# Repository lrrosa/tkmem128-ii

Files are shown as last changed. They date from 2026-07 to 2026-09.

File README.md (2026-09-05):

# TKMEM-128 II



Expansão externa de **128 KB (ou 512 KB) de RAM paginada no padrão ZX Spectrum 128**
para **TK90X, TK95 e ZX Spectrum 48K**. Redesenho completo em **KiCad 10**, com
arquivos de fabricação prontos.

> O nome vem da placa brasileira que originou este redesenho, mas o circuito é do
> **Velesoft e nasceu para o ZX Spectrum 48K**. A adaptação de 2012 ao TK usava um
> contato que no Spectrum carrega vídeo; aqui isso foi corrigido, e a placa voltou
> a servir nas duas famílias. Ver [Compatibilidade](#compatibilidade).

> **Estado: placas fabricadas e conferidas eletricamente, ainda não montadas.**
> ERC e DRC estão zerados, a netlist foi conferida contra a intenção de projeto,
> e as duas placas **voltaram da fábrica em setembro de 2026 com todas as ilhas
> aprovadas no teste de continuidade**. O que ainda não foi feito: **montar os
> componentes e ligar num micro real**. Antes de mandar fabricar, leia
> [`docs/ANTES-DE-FABRICAR.md`](docs/ANTES-DE-FABRICAR.md) — há itens que
> dependem de medir peças físicas.
>
> O conector de borda é o **TE/AMP 5645235**, de entrada vertical. As cotas do
> footprint saíram do desenho de cliente e estão no
> [datasheet arquivado](docs/), mas ninguém montou a peça ainda.

---

## Este projeto é uma derivação

Ele não inventa o circuito: junta e redesenha dois trabalhos anteriores.

| Origem | Autor | O que veio de lá |
| --- | --- | --- |
| [**external 128kb upgrade**](https://velesoft.speccy.cz/zx/external_128kb_upgrade/index.htm) (`zx48_to_128-EASY_3`), 2009 | **Velesoft** (Pavel Cimbal, República Tcheca) | O circuito base: as equações do GAL20V8, o latch da porta `0x7FFD` e o esquema de paginação da SRAM, incluindo a extensão de 512K |
| **TKMEM-128**, 2012 | **Luccas Eletrônica** (Eduardo Luccas, Brasil) | A adaptação ao TK90X/TK95: soquete de EPROM com a ROM do Spectrum 128, jumpers de seleção de ROM, a auto-desativação da RAM interna de 32K por um pino livre do barramento, e a divisão em placa principal + expansor |

Créditos também a **Flávio Matsumoto**, que sugeriu o circuito do Velesoft para
os TKs e identificou a caixa Patola PB 085/3, e a **Daniel Jose Viana
(danjovic)**, cujo trabalho documentou as cotas da placa para essa caixa.

E a [**goloskokovic/zx16to128upgrade**](https://github.com/goloskokovic/zx16to128upgrade),
que redistribui o material do Velesoft com o crédito devido. De lá vieram duas
coisas que não estavam aqui: os **pontos de desativação da RAM interna num ZX
Spectrum 48K**, por Issue de placa-mãe (ver
[`docs/PREPARAR-O-TK.md`](docs/PREPARAR-O-TK.md#e-num-zx-spectrum-48k)), e os
arquivos da variante **`EASY_6b`**, que permitiram comparar as duas versões do
circuito original (ver
[`docs/VELESOFT-EASY3-x-EASY6B.md`](docs/VELESOFT-EASY3-x-EASY6B.md)). Nenhum
desses dois foi verificado em bancada por nós.

Este redesenho é distribuído sob **CERN-OHL-S v2** (ver [LICENSE.txt](LICENSE.txt)),
uma licença *fortemente recíproca*: quem fabricar, modificar ou distribuir
precisa disponibilizar as fontes das modificações sob a mesma licença.

---

## O que a placa faz

O ZX Spectrum 128 difere do 48K em três coisas: 128K de RAM em 8 bancos de 16K,
o chip de som AY-3-8912, e o espelhamento da memória de vídeo ("shadow video").
Esta placa entrega **a primeira**. O som AY exige interface separada; o shadow
video é inviável numa interface externa, porque exigiria interceptar a RAM baixa
da ULA dentro do micro.

Na prática a grande maioria dos jogos de 128K funciona — a exceção são os poucos
títulos que dependem do shadow video.

### Mapa de memória

| Faixa | Quem responde |
| --- | --- |
| `0x0000-0x3FFF` | ROM — a interna do micro, ou a 27C256 da placa (jumper) |
| `0x4000-0x7FFF` | RAM baixa **interna do micro** (memória de vídeo da ULA). Não é decodificada aqui |
| `0x8000-0xBFFF` | SRAM externa, **banco 2 fixo** |
| `0xC000-0xFFFF` | SRAM externa, banco selecionado pela porta `0x7FFD` |

Como a SRAM externa cobre `0x8000-0xFFFF`, **os 32 KB superiores de RAM interna
precisam ser desativados** — é a única alteração necessária dentro do micro, e a
única coisa que difere entre TK e ZX Spectrum. Veja
[`docs/PREPARAR-O-TK.md`](docs/PREPARAR-O-TK.md).

> **Sobre a variante `EASY_6b` do Velesoft.** Circula junto com a nossa em
> outros repositórios, e é fácil confundir com uma versão melhor. Não é: a
> serigrafia da placa dela diz `MEMORY UPGRADE FOR ZX 16`. É para um Spectrum de
> **16 KB**, onde a RAM inteira vem de fora — por isso as equações dela também
> decodificam `0x4000-0x7FFF`. **Este projeto deriva da `EASY_3`**; a comparação
> completa, incluindo a conferência do nosso esquemático e do nosso layout contra
> os do Velesoft, está em
> [`docs/VELESOFT-EASY3-x-EASY6B.md`](docs/VELESOFT-EASY3-x-EASY6B.md).

### Porta 0x7FFD

Um `74HCT273` latcheia o barramento de dados quando o GAL detecta a escrita na
porta (`A15=0`, `A5=1`, `A1=0`, `/IORQ` e `/WR` ativos):

| Bit | Sinal | Função |
| --- | --- | --- |
| 0–2 | `BANK0..BANK2` | Banco de RAM em `0xC000` |
| 3 | `VRAM` | Shadow screen — latcheado, **sem uso** nesta arquitetura (disponível em TP1) |
| 4 | `ROMA14` | Seleciona a metade da 27C256 |
| 5 | `DIS128` | Trava a paginação até o reset |
| 6–7 | `BANK3..BANK4` | Extensão 512K (só no modo ZX512) |

A trava do bit 5 é elegante: `DIS128` entra na equação do clock do latch
(`CLK7FFD = ... + DIS128`), então ao ser setado o clock fica preso em nível alto
e o latch nunca mais é acionado.

---

## Compatibilidade

**TK90X, TK95 e ZX Spectrum 48K.** Não é uma promessa vaga: reduz-se a uma regra
que dá para verificar.

O barramento de expansão é o mesmo conector de 2×28 nas duas famílias, mas
**nove contatos não carregam a mesma coisa** em cada uma. Enquanto a placa não
tocar nenhum deles, ela serve nas duas:

| Contato | No TK90X/TK95 | No ZX Spectrum 48K |
| --- | --- | --- |
| 4 | +9 V | USS |
| 7 | N.C. | GND |
| 15 | GND | sinal |
| 16, 17, 18 | livres | **Y, V e U do vídeo componente** |
| 34, 35 | 12 V | difere |
| 37 | **+5 V** | **−5 V** |

Esta placa liga **34 dos 54 contatos, e nenhum é dessa lista.** Alimentação sai
dos contatos 3 (+5 V), 6 e 14 (GND), que são iguais nas duas máquinas.

A verificação é automática, para a afirmação não envelhecer:

```bash
python tools/confere_compatibilidade.py
```

Ele cruza a lista de divergências de `busdef.py` com os contatos que a netlist
realmente usa, e falha se algum aparecer.

> ⚠️ **O que ainda é específico de cada máquina: desativar a RAM interna de 32 KB.**
> Isso não é opcional — sem desativar, a memória do micro colide com a SRAM
> externa em `0x8000-0xFFFF`. No TK é um fio do contato 29 ao pino 10 do IC27;
> num Spectrum o ponto é outro e **depende da Issue da placa-mãe** — os dois
> procedimentos estão em
> [`docs/PREPARAR-O-TK.md`](docs/PREPARAR-O-TK.md#e-num-zx-spectrum-48k).
> Num Spectrum a placa não aciona nada pelo contato 29 — mas **não porque o
> contato seja diferente**: ele é N.C. nas duas máquinas. É porque o
> procedimento publicado para o Spectrum amarra o pino do mod ao +5 V do
> próprio CI, sem trazer fio até o conector. Levar o truque do TK para lá é a
> mesma topologia, e esbarra numa diferença *elétrica* —
> [analisada aqui](docs/PREPARAR-O-TK.md#dava-para-levar-a-auto-desativação-para-o-spectrum).
>
> Não montamos a placa num Spectrum: a compatibilidade acima é do barramento,
> conferida contato a contato, não de bancada — e o ponto interno do Spectrum
> vem de terceiros, também não verificado por nós.

---

## As duas placas

A placa de componentes fica **em pé** dentro da caixa. O conector de borda é
soldado **diretamente nela** — e como esse conector é de entrada vertical
(a placa que entra fica perpendicular à que segura o conector), a fenda dele cai
no plano horizontal e recebe a placa do micro.

Os terminais do conector são **retos** e atravessam a placa, sobrando ~3,18 mm
do outro lado em duas fileiras a 4,85 mm. A **tira de expansão** entra **entre
essas fileiras** — uma passa por cima dela, a outra por baixo — e é soldada
**dos dois lados**. Ela não tem conector nenhum: ilhas de solda nas duas faces
de um extremo, dedos de borda no outro.

Vista de lado, com as caixas em corte

O **conector fica fora da caixa Patola**, atravessando o recorte que se abre na
frente dela. Não é escolha estética: no TK e no ZX Spectrum a abertura
`EXPANSION` é **recuada dentro da carcaça**, então a caixa encosta na traseira do
micro e só o conector entra. A placa, por sua vez, assenta rente ao fundo da
caixa.

> No conector, **1..28 fica na fileira de baixo** (junto à aresta inferior da
> placa), igual à fileira inferior da placa do micro; 29..56 fica do lado de
> dentro. É a mesma convenção no TK e no ZX Spectrum, onde essas fileiras são
> chamadas de B e A.
>
> ⚠️ **O lado dos componentes tem que ficar virado para a tira de expansão**,
> nunca para o lado do conector. Ao contrário, a placa dentro da caixa esbarra
> no micro e não encaixa direito. Na prática o conector de borda é **o único
> componente do lado do cobre**: entra por baixo e é soldado por cima.

| Placa | Arquivo | Conteúdo |
| --- | --- | --- |
| Principal | [`hardware/tkmem128-ii.kicad_pro`](hardware/) | GAL20V8B, 74HCT273, SRAM DIP-32, EPROM 27C256, 3 jumpers, desacoplamento e o conector de borda |
| Tira de expansão | [`hardware/expansor/`](hardware/expansor/) | Ilhas de solda nas duas faces de um lado, dedos de borda do outro — nenhum componente, só o fio de terra `W1` |

A **placa principal é de 4 camadas**; a tira de expansão, de 2.

| Camada | Placa principal | Tira |
| --- | --- | --- |
| F.Cu | sinal | 27 retas de 1,5 mm (pinos 29..56) |
| In1.Cu | **plano de GND** inteiro | — |
| In2.Cu | **plano de +5V** inteiro | — |
| B.Cu | sinal | 27 retas de 1,5 mm (pinos 1..28) |

Como todos os componentes são passantes, cada ilha de `+5V` e de `GND` toca o seu
plano direto: **não há uma única trilha de alimentação nas faces de sinal**, e
nenhuma via serve só para alimentação. Sinal de 0,5 mm, isolação de 0,2 mm,
21 vias, e nenhum fio de ligação.

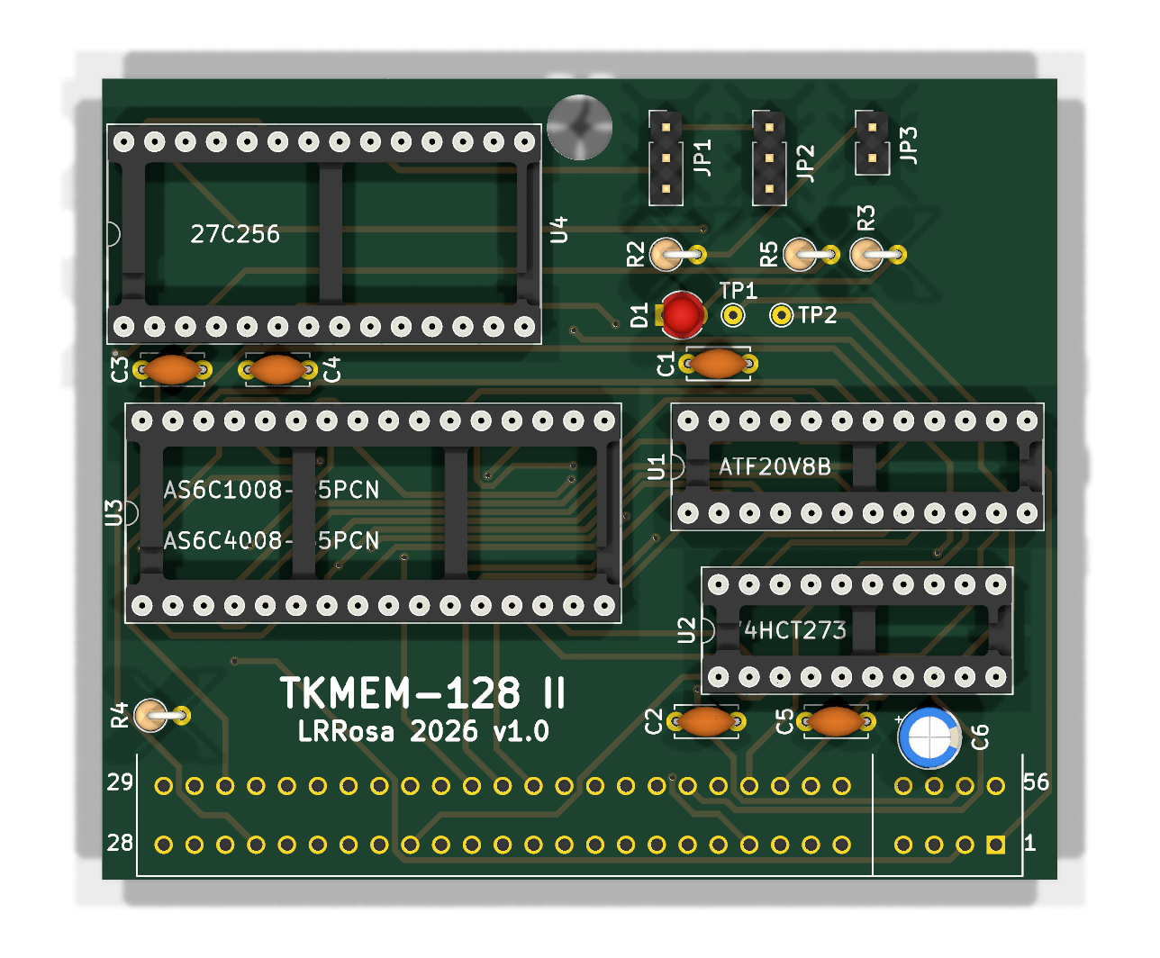
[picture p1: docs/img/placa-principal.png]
Placa principal


O furo grande no topo é o `H1`, e ele não é furo de parafuso: por ali **passa a
torre** de fixação da caixa Patola, que tem Ø5 externo e nasce do fundo da
tampa. O parafuso da caixa corre dentro da torre e nunca toca a placa — `H1`
serve para localizar, não para apertar.

O conector é passante e é usado pelos dois lados — por baixo entra o conector,
por cima solda a tira —, então a numeração dele está serigrafada nas duas
faces.

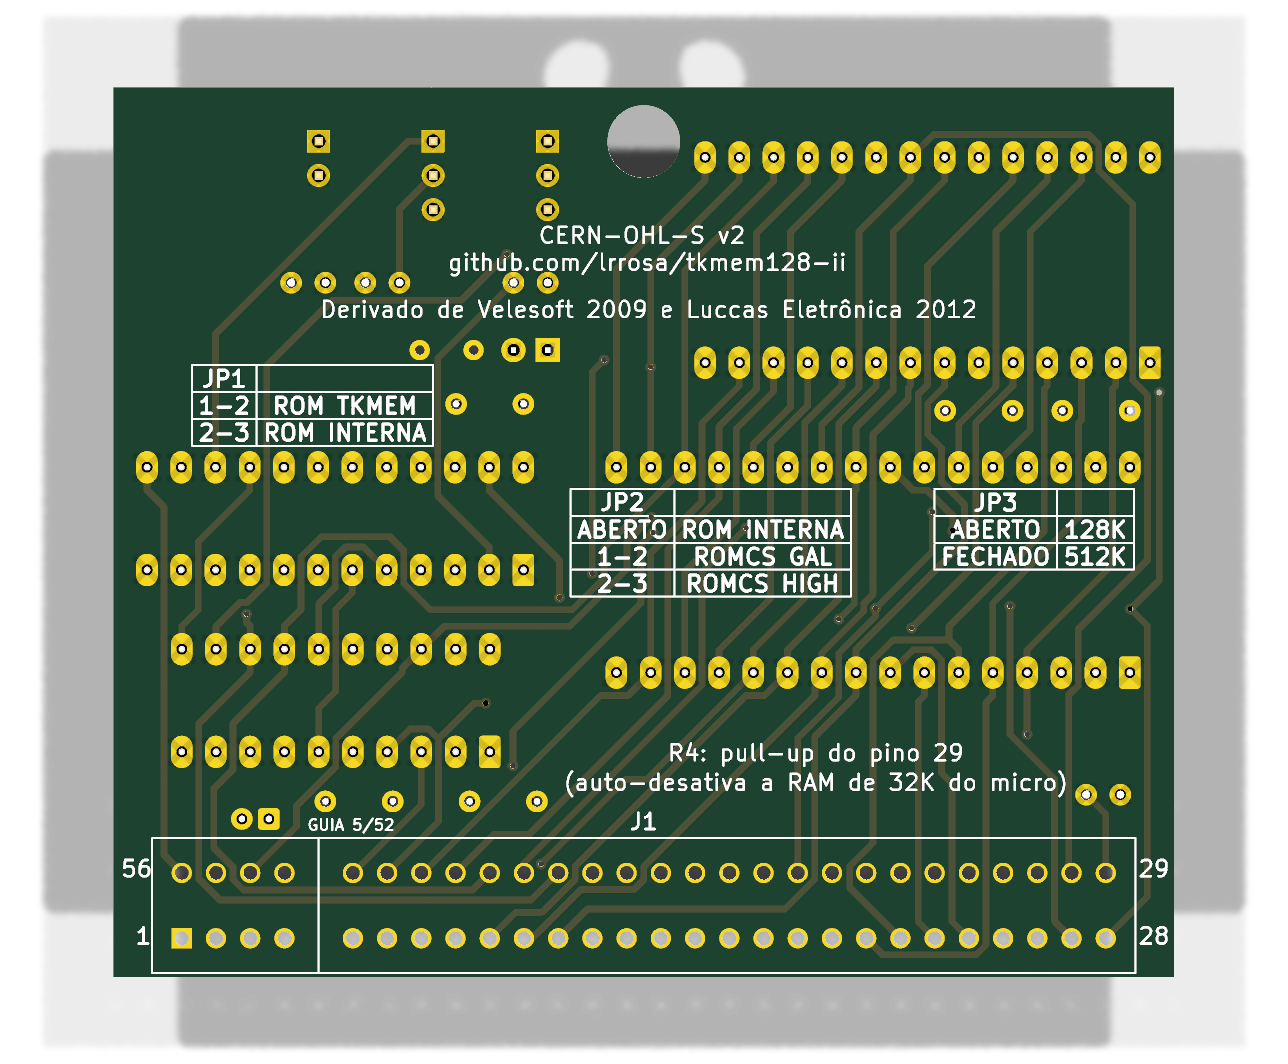
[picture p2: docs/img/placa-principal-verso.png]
Placa principal, verso


O verso é o manual da placa. Traz as **três tabelas de jumper**, a função do
`R4` e a licença — na bancada, com um shunt na pinça, isso vale mais que este
README.

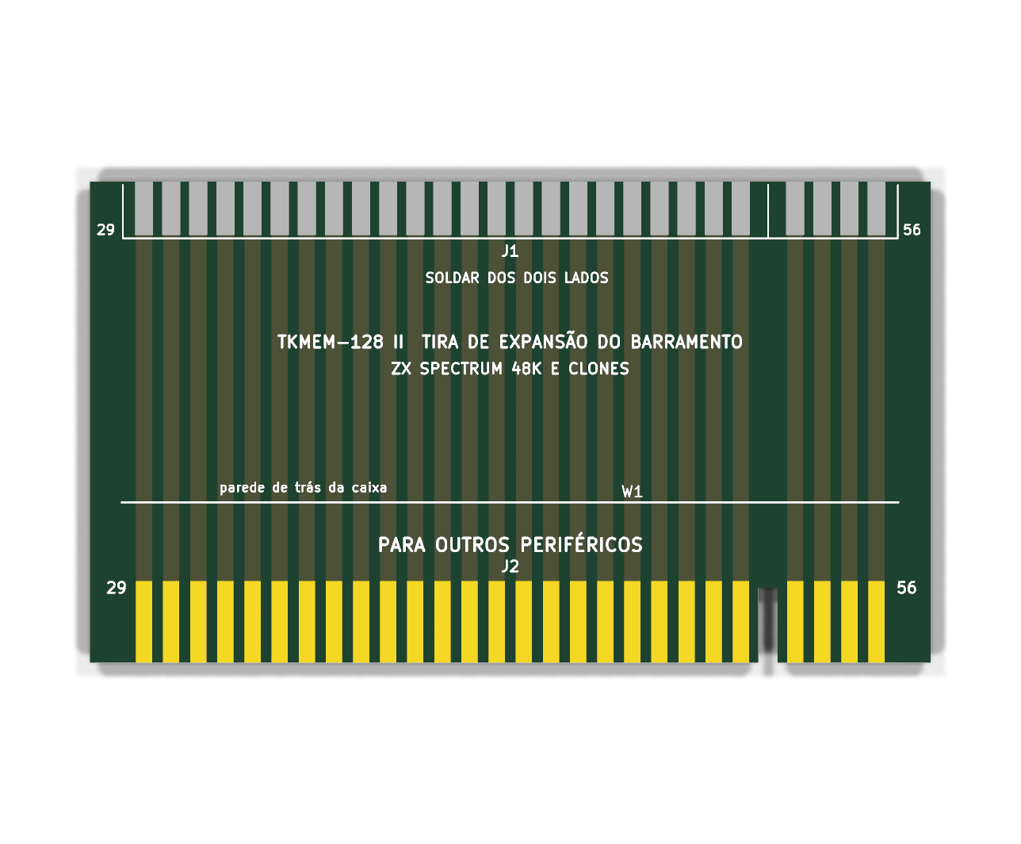
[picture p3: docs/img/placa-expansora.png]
Tira de expansão


A tira é soldada dos dois lados, então cada face traz a numeração dos **seus**
pinos: 29..56 na frente, 1..28 no verso.

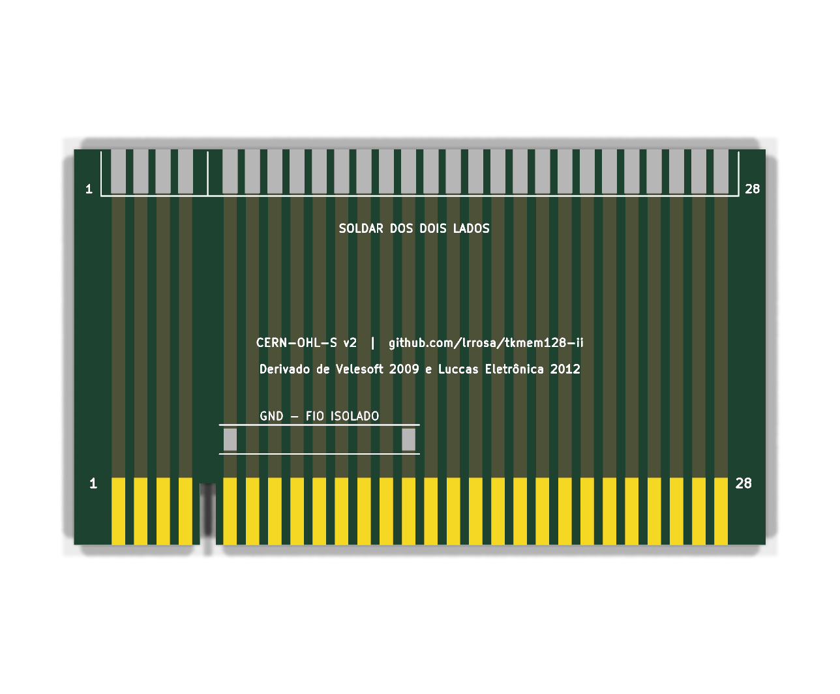
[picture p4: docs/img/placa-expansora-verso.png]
Tira de expansão, verso


### E fabricadas

Primeira tiragem, setembro de 2026. **Todas as ilhas passaram no teste de
continuidade** — as placas ainda não foram montadas nem ligadas num micro.

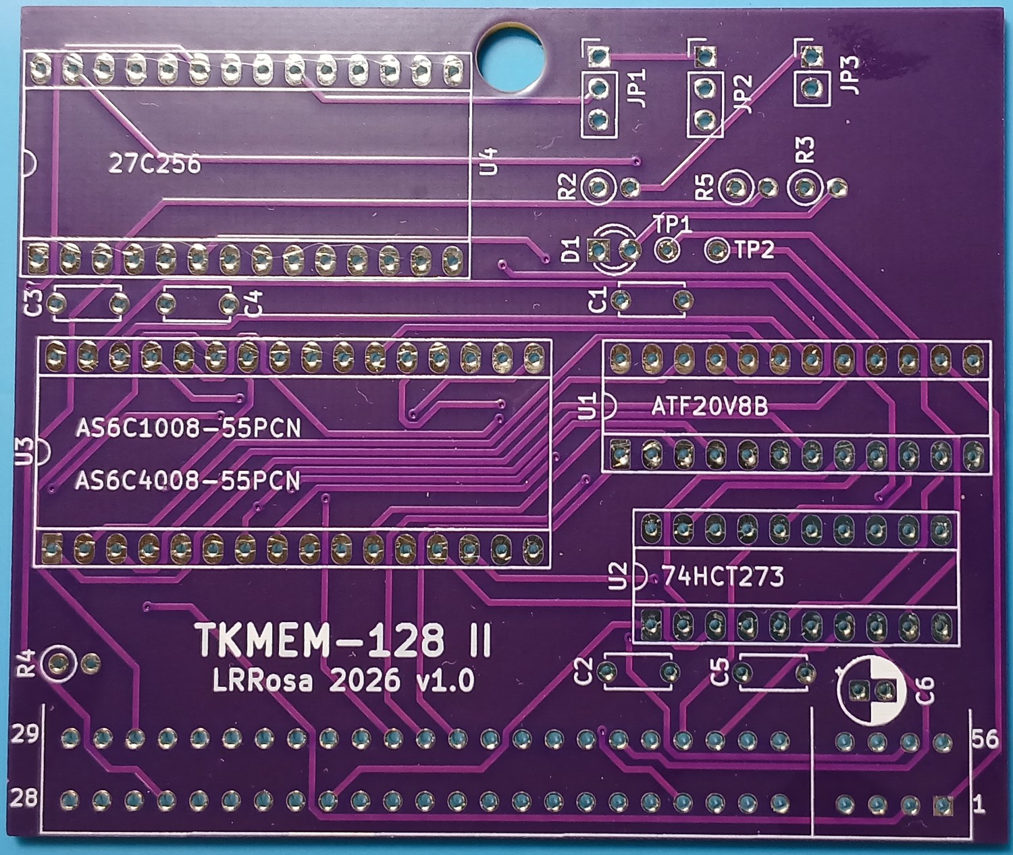
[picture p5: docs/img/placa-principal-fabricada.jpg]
Placa principal fabricada, lado dos componentes


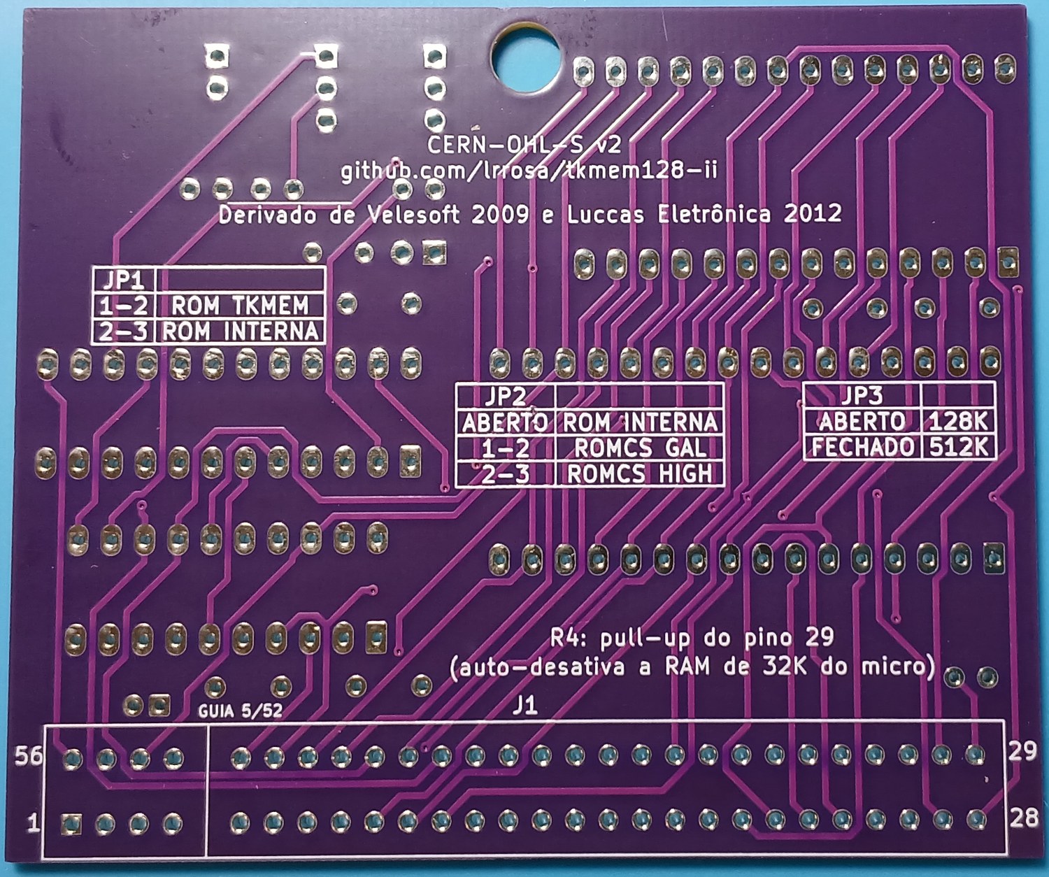
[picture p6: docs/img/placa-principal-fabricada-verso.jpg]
Placa principal fabricada, lado do cobre


O verso cumpriu o que o render prometia: as três tabelas de jumper e a nota do
`R4` ficam legíveis a olho nu com a serigrafia de 1,2 mm — que é o ponto de
tê-las na placa em vez de só aqui.

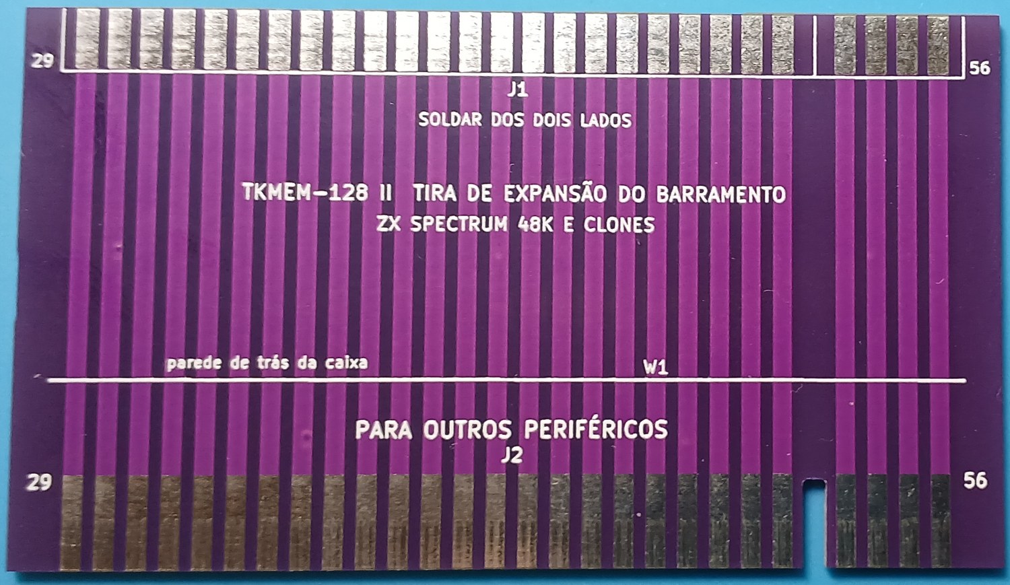
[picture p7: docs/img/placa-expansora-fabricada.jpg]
Tira de expansão fabricada


A tira mostra os dois itens do formulário que **não viajam nos gerbers** (item 0
do [ANTES-DE-FABRICAR](docs/ANTES-DE-FABRICAR.md)) tendo saído certos: os dedos
vieram com **ENIG** e com o **chanfro de 45°**. O entalhe na borda de baixo, à
direita do centro, é o rasgo da guia — aprofundado de 5,0 para 7,0 mm depois da
conferência em papel.

---

## O que mudou em relação ao original

| Melhoria | Motivo |
| --- | --- |
| **Passagem do barramento** (dedos de borda na expansora) | O original ocupava o barramento; agora dá para encadear outros periféricos |
| **Desacoplamento por CI** (100 nF em cada um) + 10 µF de reservatório | O original tinha desacoplamento mínimo |
| **4 camadas com planos de GND e +5V inteiros** | Alimentação sem uma única trilha nas faces de sinal, retorno de corrente curto e imunidade a ruído. O original era de 2 camadas |
| **Jumper JP2 com duas estratégias de ROMCS** | O `ROMCS` do barramento é **ativo em nível alto** para desligar a ROM interna, o oposto da saída `/ROMCS` do GAL. É a explicação mais provável para a ROM 128 do original "funcionar num TK e não em outro". JP2 permite escolher entre acionar pelo GAL ou fixar em nível alto (como fazem os cartuchos da Interface 2), com R5 em série |
| **Auto-desativação sem jumper nenhum** | A original usava o **pino 17**, livre no TK mas **V do vídeo componente no ZX Spectrum** — daí o jumper e o aviso de que a posição errada danifica o micro. Aqui o sinal vai pelo **pino 29**, que é N.C. nas duas máquinas, então o pull-up é permanente e **JP4 deixou de existir**. Ver [a análise](docs/PREPARAR-O-TK.md#por-que-o-pino-29) |
| **GAL com `.jed` pronto e verificado** | O usuário não precisa montar nada: o `.jed` distribuído é gerado das equações deste projeto e conferido fusível a fusível contra o mapa de referência (checksum `C5752`, zero divergências) |
| **Degrau zero na corrente de periféricos** | A tira de expansão solda nos terminais do próprio conector, ficando coplanar com a placa do micro. O periférico seguinte entra no mesmo plano, sem escadinha |
| **Bit N da porta 7FFD no flip-flop N** | O original embaralhava as entradas do latch; aqui a ordem é natural e o esquemático se lê sozinho |
| **Endereços e dados da EPROM 1:1** | Obrigatório (o conteúdo da ROM é fixo) e documentado |
| **Pontos de teste** (`VRAM`, `CLK7FFD`) | Para depurar sem grampear em perna de CI |
| **LED de energia** (opcional) | Diagnóstico imediato |
| **Peças em produção na BOM** | AS6C1008 e ATF20V8B no lugar de peças só encontráveis como estoque antigo |

---

## Configuração dos jumpers

| Jumper | Posição | Efeito |
| --- | --- | --- |
| **JP1** SELECIONA ROM | 1-2 | ROM 128: a EPROM da placa responde em `0x0000-0x3FFF` |
| | 2-3 | ROM interna: EPROM desligada (padrão) |
| **JP2** ROMCS BARRAMENTO | aberto | Usa a ROM interna do micro (padrão) |
| | 1-2 | Aciona `ROMCS` pelo GAL (comportamento da placa original) |
| | 2-3 | Fixa `ROMCS` em nível alto (estilo Interface 2) |
| **JP3** ZX128/ZX512 | aberto | 128K — SRAM `AS6C1008` (padrão) |
| | fechado | 512K — SRAM `AS6C4008` |

Esta tabela está **serigrafada no verso da placa**, uma por jumper, com as
mesmas palavras — ver o render do verso acima.

> ⚠️ **JP1 em 1-2 sem JP2** não faz nada útil: sem desligar a ROM interna, os dois
> chips disputam o barramento de dados. Use os dois juntos ou nenhum.

> **A auto-desativação da RAM não tem jumper.** `R4` mantém o **pino 29** em
> nível 1 permanentemente, e esse pino é N.C. tanto no TK quanto no ZX Spectrum.
> Num Spectrum a placa não faz nada ali; num TK, com o fio interno do pino 29 ao
> pino 10 do IC27, ela desliga os 32 KB. Nada a configurar.

---

## Lista de material

### Placa principal

| Ref | Valor | Encapsulamento | Observação |
| --- | --- | --- | --- |
| U1 | GAL20V8B, **ATF20V8B-15PC** ou PALCE20V8H | DIP-24 300 mil | Grave [`hardware/gal/tkmem128.jed`](hardware/gal/tkmem128.jed) — peças equivalentes em [hardware/gal](hardware/gal/README.md) |
| U2 | 74HCT273 | DIP-20 300 mil | Latch da porta 7FFD |
| U3 | **AS6C1008-55PCN** (128K×8) | DIP-32 600 mil | Ou `AS6C4008-55PCN` (512K×8) no modo ZX512 — outras peças servem, ver [equivalentes](#equivalentes-para-u3-a-sram) |
| U4 | 27C256 | DIP-28 600 mil | **Opcional** — ver seção da ROM |
| R2, R4 | 1 kΩ | axial, vertical | |
| R5 | 0 Ω | axial, vertical | Fio; 100–470 Ω se houver disputa no ROMCS |
| R3 | 2,2 kΩ | axial, vertical | Opcional (LED) |
| C1–C5 | 100 nF cerâmico | disco 5 mm, passo 5 mm | |
| C6 | 10 µF eletrolítico | radial 5 mm, passo 2 mm | |
| D1 | LED 3 mm | | Opcional |
| JP1, JP2 | header 1×3 | passo 2,54 mm | |
| JP3 | header 1×2 | passo 2,54 mm | |
| J1 | **TE/AMP 5645235** — conector de borda 56 vias, entrada vertical | passo 2,54 mm, fileiras a 4,85 mm | Único componente do lado do cobre; recebe os dedos do micro |
| — | soquetes torneados DIP-20/24/28/32 | | Recomendado |

### Equivalentes para U3 (a SRAM)

O projeto não depende de um fabricante. Serve **qualquer SRAM 128K×8 de 5 V em
DIP-32 na pinagem JEDEC de 1 Mbit** — que é a pinagem padrão dessa família:
`/CS1` no 22, `/OE` no 24, `/WE` no 29, `CE2` no 30, `VCC` no 32, `GND` no 16.

| Peça | Fabricante | Situação |
| --- | --- | --- |
| **AS6C1008-55PCN** | Alliance | Da BOM — ainda em produção, a mais fácil de achar nova |
| **HM628128A** (ex.: `HM628128ALP-7`) | Hitachi | Descontinuada; comum como estoque antigo |
| **TC551001** | Toshiba | Descontinuada |
| **KM681000** | Samsung | Descontinuada |
| **CY62128** | Cypress | |
| **IS61C1024 / IS62C1024** | ISSI | O `1024` é 1024 kbit = 1 Mbit, não 1 M×8 |

> ⚠️ **Uma 62256 não serve.** É 32K×8 (256 kbit) em DIP-28 — outra
> capacidade e outro encapsulamento. A confusão é fácil porque a numeração
> parece próxima.

**A única divergência real entre essas peças é o pino 30**, e vale conferir no
datasheet da que você comprou:

| Pino 30 | Funciona? |
| --- | --- |
| `CE2` / `CS2`, ativo alto | **Sim** — é o caso da `AS6C1008` |
| `NC`, não conectado | **Sim** — o sinal é ignorado e o `/CS1` do pino 22 controla sozinho |
| `A17` | Aí é uma 512K×8, não uma 128K — ver abaixo |

Isso funciona porque `/SA17` é uma saída **invertida** do GAL:

```
/SA17 = A14 * A15 * BANK3 * /ZX512
```

Com **JP3 aberto**, o pull-up põe `ZX512` em alto, o produto zera e o pino 30
fica **fixo em nível alto** — exatamente o `CE2` que a memória espera.

> ⚠️ **Com uma 128K×8, JP3 fica aberto — sempre.** Fechado por engano, o
> pino 30 deixa de ser nível fixo e passa a receber `/SA17` paginado: toda vez
> que o software escrever `BANK3=1` na porta `0x7FFD`, o pino cai para nível
> baixo e **desabilita a RAM** em 0xC000. A falha é intermitente e depende do
> jogo, que é o pior tipo de falha para diagnosticar.

**Velocidade é indiferente.** Peças dessa família vão de 55 a 100 ns, e a
3,5 MHz há mais de 500 ns entre o endereço ficar válido e o Z80 amostrar o
dado. Até a mais lenta sobra.

**Procedência importa mais que velocidade.** As descontinuadas circulam como
estoque antigo e SRAM antiga é alvo comum de remarcação. Se o preço for
parecido, prefira a peça em produção.

#### No modo 512 KB

Aí a peça tem que ser uma **512K×8** de verdade — `AS6C4008`, `HM628512`,
`TC554001`, `IS61C4008` — porque o pino 30 passa a ser `A17` e o pino 1, `A18`.
E **JP3 fecha**. Ver [Modo 512 KB](docs/MONTAGEM.md#modo-512-kb).

### Tira de expansão

Não leva componente nenhum, nem conector: os "conectores" são cobre da própria
PCB, e o único item a soldar além das ilhas é um pedaço de fio.

| Ref | O que é | Observação |
| --- | --- | --- |
| J1 | Ilhas de solda nas duas faces, até a borda | Solda nos terminais retos do conector da placa principal, por cima e por baixo |
| J2 | Dedos de borda | Passagem do barramento ao próximo periférico |
| W1 | Fio isolado curto | Liga as duas ilhas `GND - FIO ISOLADO` no verso (pinos 6 e 14); passa por cima das trilhas, por isso isolado |

---

## Montagem

Guias detalhados:

- [`docs/PREPARAR-O-TK.md`](docs/PREPARAR-O-TK.md) — desativar a RAM interna de 32K
- [`docs/MONTAGEM.md`](docs/MONTAGEM.md) — ordem de montagem, guia do conector, caixa
- [`docs/ANTES-DE-FABRICAR.md`](docs/ANTES-DE-FABRICAR.md) — conferências obrigatórias
- [`docs/VELESOFT-EASY3-x-EASY6B.md`](docs/VELESOFT-EASY3-x-EASY6B.md) — as duas variantes do circuito original, e por que este projeto usa a `EASY_3`

Dois pontos que costumam pegar quem monta:

1. **A guia do conector de borda.** O conector de 56 vias vem sem guia. Na
   posição **5/52** você encaixa um pedacinho de PCB (ou material equivalente)
   casando com o rasgo entre os dedos do TK — a placa não tem furos ali,
   porque não há terminal nessa posição. Sem a guia é fácil plugar deslocado
   e danificar o micro.
2. **A tira de expansão é soldada dos dois lados.** Ela entra entre as duas
   fileiras de terminais retos do conector — uma fileira por cima, outra por
   baixo — e as ilhas chegam até a borda, então o terminal encontra cobre
   mesmo se for curto.

---

## Fabricação

Arquivos prontos em [`production/`](production/): Gerber X2, furação Excellon,
BOM e mapa de posições, para as duas placas.

Cada placa tem o seu `gerbers.zip`, que é o arquivo que se envia à fábrica.

| | Placa principal | Tira de expansão |
| --- | --- | --- |
| Camadas | **4** (F.Cu / GND / +5V / B.Cu) | **2** |
| Espessura | 1,6 mm | 1,6 mm |
| Trilha | 0,5 mm | 1,5 mm |
| Isolação | 0,2 mm | 0,25 mm |
| Furo mínimo | 0,3 mm | — (sem furos) |
| Via | 0,8 mm com furo de 0,4 mm | nenhuma |
| Furo não metalizado | 1 × Ø5,4 (`H1`, passagem da torre da caixa) | nenhum |

Tudo folgado dentro da capacidade padrão de fábrica barata — nada aqui entra em
faixa de preço especial, a não ser as 4 camadas da placa principal.

> ⚠️ **Peça 4 camadas para a placa principal.** Se pedir 2 por engano, a fábrica
> descarta os dois planos internos e a placa sai sem alimentação nenhuma — falha
> que não aparece na inspeção visual. Ver
> [ANTES-DE-FABRICAR, item 3b](docs/ANTES-DE-FABRICAR.md).

**A tira de expansão precisa de acabamento em ouro (ENIG) na placa inteira e
chanfro de 45° na borda dos dedos.** Os dedos entram e saem do conector do
periférico seguinte muitos ciclos, e as ilhas de solda do outro extremo também
chegam à borda — HASL descasca nos dois casos. Peça o chanfro explicitamente,
é um item à parte no pedido.

---

## Gravando o GAL

**Já vai pronto**: grave [`hardware/gal/tkmem128.jed`](hardware/gal/tkmem128.jed)
direto no programador. Checksum de fusíveis **`C5752`** — confira no software do
gravador ao abrir o arquivo.

Esse `.jed` não foi copiado de lugar nenhum: é gerado por
[`tools/galgen.py`](tools/galgen.py) a partir das equações deste projeto, e
conferido **fusível a fusível** contra o mapa de referência do projeto do
Velesoft — *zero divergências em 2706 fusíveis*. O fonte em sintaxe GALasm está
em [`tkmem128.pld`](hardware/gal/tkmem128.pld) para quem quiser modificar.

Programadores XGecu (T48/T56) gravam GAL20V8B, ATF20V8B e PALCE20V8H — mas
**escolha no software o dispositivo que você tem de verdade**: o mapa de
fusíveis é o mesmo, o algoritmo de gravação não.

---

## A ROM do Spectrum 128

**A imagem da ROM não está neste repositório** — ela é copyright da Amstrad/Sky.
O hardware (soquete U4 + jumpers) está lá; a imagem você monta com as suas
cópias de `128-0.rom` e `128-1.rom`:

```bash
cat 128-0.rom 128-1.rom > rom_tkmem128_27c256.bin
```

A ordem importa: `A14` da EPROM vem de `ROMA14` (bit 4 da porta 7FFD), então a
ROM 0 (editor do 128) tem que ficar na metade baixa.

Vale dizer que **a ROM é dispensável**: o autor da TKMEM-128 original deixou de
fornecê-la depois de constatar que os jogos de 128K não dependem dela, e que ela
causava incompatibilidades entre unidades diferentes de TK90X.

---

## Estrutura do repositório

```
hardware/
  tkmem128-ii.kicad_pro/.kicad_sch/.kicad_pcb   placa principal
  expansor/                                   tira de expansão
  lib/                                        símbolos e footprints próprios
  gal/                                        fonte e documentação do GAL
production/
  placa-principal/                            gerbers, furação, BOM, posições, PDF
  tira-expansao/                            idem
docs/
  PREPARAR-O-TK.md   MONTAGEM.md   ANTES-DE-FABRICAR.md
  VELESOFT-EASY3-x-EASY6B.md                  comparação com a variante do autor original
  relatorios/                                 saídas de ERC e DRC
tools/                                        geradores do projeto KiCad
```

A biblioteca de símbolos e footprints é **local ao projeto** — nada depende da
versão das bibliotecas do seu KiCad.

O projeto KiCad **nasceu gerado por script** a partir de uma descrição única da
netlist ([`tools/`](tools/)) — é o que garante que esquemático e placa não
divergem — e depois foi refinado à mão no KiCad. A fonte corrente são os
arquivos em `hardware/`; os geradores ficam como registro e ferramenta de apoio.

### Estado da verificação

| Placa | ERC | DRC | Ligações |
| --- | --- | --- | --- |
| Principal | 0 | 0 erros (6 avisos cosméticos) | 0 pendentes |
| Tira de expansão | 0 | 0 erros (4 avisos cosméticos) | 0 pendentes |

A netlist exportada pelo KiCad foi comparada nó a nó com a intenção de projeto
nas duas placas: **74 nets na principal e 53 na tira, zero divergência**.

---

## Licença

Hardware sob **CERN-OHL-S v2** — ver [LICENSE.txt](LICENSE.txt).

```
Copyright Leonardo Rosa e contribuidores.
Derivado de: "external 128kb upgrade" (Velesoft, 2009)
             TKMEM-128 (Luccas Eletrônica, 2012)

Este código-fonte é licenciado sob CERN-OHL-S v2 ou posterior.
Você pode redistribuí-lo e modificá-lo nos termos dessa licença.
Distribuído SEM QUALQUER GARANTIA, incluindo as de COMERCIALIZAÇÃO,
ADEQUAÇÃO A UM FIM ESPECÍFICO E NÃO-VIOLAÇÃO.
Consulte a CERN-OHL-S v2 para os termos aplicáveis.
```

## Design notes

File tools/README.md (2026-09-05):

# Geradores

Todo o projeto KiCad deste repositório é **gerado por script** a partir de uma
descrição única da netlist. Isso mantém esquemático, PCB, símbolos e footprints
sempre coerentes entre si — não existe a possibilidade de o esquemático dizer
uma coisa e a placa outra.

Você **não precisa destes arquivos** para fabricar ou modificar a placa: abra o
projeto no KiCad normalmente. Eles estão aqui porque documentam como o desenho
nasceu, e porque a CERN-OHL-S pede a fonte completa.

> ⚠️ **Os geradores são ferramenta de bootstrap, não a fonte corrente.**
> O esquemático e o posicionamento foram refinados à mão no KiCad depois de
> gerados. Rodar `gen_schematic.py` ou `gen_pcb.py` de novo **sobrescreve esse
> trabalho**. A fonte corrente são os arquivos em `hardware/`.
>
> O que continua seguro rodar a qualquer momento: `gen_symbols.py` e
> `gen_footprints.py` (bibliotecas), `galgen.py` (o `.jed` do GAL), e o trio de
> roteamento `mk_decoy.py` / `import_ses.py` / `add_zones.py` quando você
> quiser reroteá-las de propósito.

## Arquivos

| Arquivo | Papel |
| --- | --- |
| `busdef.py` | Pinagem 1..56 do barramento do TK e mapa do header entre as placas |
| `netlist.py` | Netlist, posicionamento e serigrafia da **placa principal** |
| `netlist_exp.py` | Idem para a **placa expansora** |
| `gen_symbols.py` | Gera `hardware/lib/tkmem128.kicad_sym` |
| `gen_footprints.py` | Gera `hardware/lib/tkmem128.pretty/` |
| `gen_schematic.py` | Gera o `.kicad_sch` (estilo netlist: rótulo global em cada pino) |
| `gen_pcb.py` | Gera o `.kicad_pcb` com contorno, footprints posicionados e nets |
| `mk_decoy.py` | Placa-isca + export do DSN para o Freerouting |
| `import_ses.py` | Importa o `.ses` roteado de volta |
| `add_zones.py` | Planos de GND nas duas faces (usado só na tira, que é de 2 camadas) |
| `limpa_cotocos.py` | Remove fragmentos de trilha de décimos de mm deixados pela importação do SES |
| `maze.py` | Roteador de labirinto A* de duas camadas com via, para fechar a última ligação quando o autorouter desiste. **Não é mais necessário** — fica como ferramenta |
| `galgen.py` | Monta o mapa de fusíveis do GAL20V8 das equações e confere contra um `.jed` de referência |
| `troca_j1.py` | Troca o footprint de `J1` na placa principal preservando esquemático e serigrafia |
| `corrige_silk_tira.py` | Acerta a serigrafia da tira (numeração por face, contorno em U, texto da passagem) sem regerar a placa |
| `silk_conector_principal.py` | Leva a numeração de `J1` para o lado dos componentes e apara o contorno que passava da aresta |
| `ajusta_guia.py` | Refaz o rasgo da guia da tira com a profundidade de `KEYSLOT_DEPTH` e repreenche as zonas |
| `silk_negrito.py` | Poe toda a serigrafia em negrito (espessura = 0,2 x tamanho, como o KiCad faz) |
| `rota_tira.py` | Roteia a tira a mao: 54 retas verticais de 1,5 mm, zero via, zero plano |
| `tira_sem_c1.py` | Removeu C1 do esquematico da tira (ilha passante e curto numa placa de passagem) |
| `repoe_principal.py` | Reposicionamento da principal para roteamento: CIs horizontais, desacoplamento junto aos CIs, corredor livre, regras 0,5/0,20 |
| `silk_principal.py` | Reposiciona a serigrafia de nível de placa depois do rearranjo |
| `tira_sj.py` | Removeu SJ1/SJ2 do esquemático — histórico, já aplicado |
| `planos_4camadas.py` | Cria os planos internos de GND e +5V da placa principal |
| `move_ramdis.py` | Moveu a auto-desativação do pino 17 para o 29 e removeu JP4 — histórico, já aplicado |
| `sobe_j1.py` | Subiu `J1` 1,5 mm: o corpo do conector deixa de sair pela aresta. Apaga o roteamento de propósito |
| `furo_da_torre.py` | Abriu `H1` em Ø5,4 — passagem da **torre** Ø5 da caixa, não do parafuso — e recuou `U4` 1,5 mm para caber. Apaga o roteamento |
| `tabelas_jumpers.py` | Serigrafia dos jumpers em tabela no verso e título da placa em duas linhas. Idempotente: limpa a faixa antes de desenhar |
| `endireita_trilhas.py` | Poda os desvios que o Freerouting deixa e chanfra cantos de 90°. Simula por padrão; `--grava` aplica. Rodar até dar zero |
| `silk_r4.py` | Quebra a nota do `R4` em duas linhas (era uma só de 43,4 mm) e troca "do TK" por "do micro" |
| `ajusta_u4_c6.py` | Traz a referência de `U4` de volta para dentro da placa (o recuo dele a jogou para x = −0,57), aproxima o `27C256`, e move `C6` 0,70 mm para cima e 0,80 para a esquerda — longe dos terminais de `J1` e da vertical de `D5`. Confere as trilhas vizinhas antes de gravar |
| `fecha_silk_conector.py` | Fecha o contorno de `J1` na serigrafia agora que o corpo cabe dentro da placa, tira as linhas duplicadas, e afasta o rótulo `GUIA 5/52` de qualquer ilha vizinha |
| `fecha_a14.py` | Fecha `A14` à mão pela margem direita: o Freerouting deixa essa uma em aberto |
| `producao.sh` | Regenera **tudo que é derivado** das placas — gerbers, furação, BOM, posições, esquemático em PDF, os `.zip`, os renders de `docs/img/` e o manifesto `production/fontes.json` — e no fim roda as verificações de regressão. Qualquer uma falhando derruba a geração |
| `confere_svg.py` | Procura texto pousado sobre trilha, ilha, parede ou outro texto no `docs/img/vista-de-lado.svg` |
| `confere_saidas.py` | **Verificação de regressão**: diz se as saídas correspondem às placas atuais, comparando o hash das fontes contra o manifesto |
| `confere_compatibilidade.py` | **Verificação de regressão**: confere que a placa não liga nenhum contato que difere entre TK e ZX Spectrum 48K |
| `confere_pinos.py` | **Verificação de regressão**: confere que os rótulos de pino do conector nos dois esquemáticos e na biblioteca de símbolos batem com `busdef.py` |
| `confere_alinhamento.py` | **Verificação de regressão**: confere que as colunas, a guia, as faces e a numeração serigrafada batem entre a placa principal e a tira |
| `confere_links.py` | **Verificação de regressão**: confere que os links entre os documentos e as âncoras de seção ainda resolvem. Aceita uma raiz por argumento, para conferir também o pacote de release |
| `monta_pacote.py` | Monta o `.zip` de fabricação e montagem publicado pelo `release.yml` |
| `corta_fotos.py` | Recorta a placa do fundo nas fotos das placas fabricadas, conferindo o resultado contra a razão real da placa |

## Refazendo tudo do zero (destrói os ajustes manuais)

Símbolos e footprints usam o Python comum; o resto usa o Python embutido do
KiCad (que traz o módulo `pcbnew`).

```bash
python gen_symbols.py
python gen_footprints.py
python gen_schematic.py netlist
python gen_schematic.py netlist_exp
```

```bash
KIPY="C:/Program Files/KiCad/10.0/bin/python.exe"
"$KIPY" gen_pcb.py netlist
"$KIPY" gen_pcb.py netlist_exp
```

Roteamento (Freerouting), para cada placa:

**Placa principal** (4 camadas). Os planos internos entram *antes* do roteamento:
o DSN precisa declará-los para o Freerouting saber que `+5V` e `GND` já estão
ligados e não tentar roteá-los nas faces de sinal.

```bash
"$KIPY" planos_4camadas.py                   # GND em In1.Cu, +5V em In2.Cu
"$KIPY" mk_decoy.py netlist main
sed -i "s/(clearance 200)/(clearance 215)/g" route.dsn
freerouting -de route.dsn -do route.ses -mp 900
"$KIPY" import_ses.py netlist main
"$KIPY" limpa_cotocos.py netlist
"$KIPY" fecha_a14.py                         # a unica que o autorouter nao fecha
```

Depois de importar, **repreencher as zonas**: o SES traz só as trilhas, e um DRC
com os planos desatualizados acusa centenas de violações que não existem.

**Tira de expansão** — não usa autorouter: as 54 ligações são retas verticais.

```bash
"$KIPY" rota_tira.py
```

O Freerouting fecha 73 das 74 nets da principal com isolação **0,215** no DSN; a
que sobra é sempre `A14`, fechada à mão por `fecha_a14.py`. Ele é determinístico
por entrada: se sobrar ligação em aberto, repetir não muda nada — tem que
perturbar a isolação. E a resposta **não é monotônica**: uma varredura deu, numa
mesma placa,

| isolação no DSN | 200 | 205 | 211 | 213 | 214 | 216 | 220 |
| --- | --- | --- | --- | --- | --- | --- | --- |
| nets em aberto | 14 | 2 | 1 | 1 | **17** | 2 | 13 |

— ou seja, 1 mícron a mais que o ótimo faz saltar de 1 para 17. Não adianta
"afrouxar até funcionar"; varra a faixa 200–220 e escolha o melhor. E **varra de
novo a cada mudança de placa**: com `U4` recuado e o furo em Ø5,4 o ótimo saiu de
0,213 para **0,215**, e 0,213 passou a deixar 2 nets.

Antes de mexer em posicionamento por causa de net em aberto, **conferir o vão
entre ilhas do conector**: foi ali que o gargalo real estava.

E depois de importar o SES, rodar `endireita_trilhas.py`. O otimizador do
Freerouting não desfaz escadinha: sobra caminho de iterações anteriores, de
quando outra rede ainda ocupava o espaço. Na rodada em que isto foi escrito ele
tirou **54,7 mm em 41 cadeias** e reduziu os cantos de 90° de 23 para zero, sem
mudar nenhuma ponta, sem trocar de camada e sem mexer em via. Rodar repetido
até dar `total: 0` — cada passada muda a decomposição em cadeias e abre a
seguinte.

> Os caminhos das ferramentas estão fixos no topo dos scripts — ajuste para a
> sua instalação.

## Uma regra de DRC que vale a pena estar ligada

Os dois projetos trazem `silk_over_copper` em **`warning`**, e não no `ignore`
que é o padrão do KiCad. É a regra que acusa serigrafia por cima da abertura de
máscara de uma ilha — texto que na placa pronta sai cortado, ou pior, tinta
sobre a área a soldar.

Ela ficou desligada por um tempo e no meio disso um capacitor andou 0,8 mm, o
rótulo `GUIA 5/52` passou a cobrir uma ilha dele, e **nada acusou**: DRC zerado,
os quatro conferidores passando, e o defeito só apareceu quando alguém olhou o
render. Ligada, ela acusa exatamente esse caso e nenhum falso positivo nas duas
placas.

## Refazendo o `.jed` do GAL

`galgen.py` monta o mapa de fusíveis do GAL20V8 a partir das equações (matriz
AND, polaridade das saídas, habilitação dos termos e bits de modo), **deduzindo o
mapa de colunas das próprias equações** em vez de assumi-lo, e compara o
resultado com um `.jed` de referência:

```bash
python tools/galgen.py caminho/para/referencia.jed
```

Saída esperada:

```
fusiveis divergentes: 0 de 2706
checksum de referencia: 5752
checksum reconstruido : 5752
```

É essa comparação que autoriza distribuir `hardware/gal/tkmem128.jed` pronto: o
arquivo é gerado das equações deste projeto, e bate fusível a fusível com o mapa
do projeto original.

## Uma geração que também confere

`producao.sh` termina rodando `confere_pinos`, `confere_links`,
`confere_compatibilidade`, `confere_svg` e `confere_alinhamento`. Com
`set -eo pipefail`, qualquer uma falhando derruba a geração antes do
`pronto.` — conferido com teste negativo.

Não é zelo: regerar sem conferir já deixou passar coisa demais aqui. A
biblioteca ficou com ilha de 1,75 mm enquanto a placa usava 1,50; o bloco de
legenda ficou com o nome antigo do projeto; e o símbolo do conector continuou
rotulando *pino 17 = RAMDIS* depois de a auto-desativação ter ido para o 29 —
esse último saindo no PDF entregue. **Nenhum aparecia no ERC nem no DRC**, que
não leem `busdef.py` nem o esquemático um do outro.

O `pipefail` não é decoração: a saída do `confere_alinhamento` passa por um
`grep` para tirar o ruído do wxWidgets, e sem ele o status seria o do `grep`.

### E no CI

[`.github/workflows/conferidores.yml`](../.github/workflows/conferidores.yml)
roda **as seis** verificações a cada push e pull request, em dois jobs
paralelos porque os custos são diferentes:

| Job | O que roda | Como |
| --- | --- | --- |
| `rapidos` | os cinco conferidores em Python puro | ~15 s, sem dependência nenhuma |
| `alinhamento` | `confere_alinhamento.py` | dentro de `kicad/kicad:10.0.4`, porque precisa do `pcbnew` |

A versão da imagem é a mesma da bancada de propósito: as placas estão no
formato do KiCad 10 (`version 20260206`) e não abrem em 8 nem 9. O job usa
`docker run` em vez de `container:` para o checkout rodar no host como
usuário normal — a imagem do KiCad não roda como root, e o conferidor só
precisa **ler** o workspace montado.

Isso cobre o furo que o `producao.sh` não cobre: ele só confere quando alguém
lembra de rodá-lo. As duas que mais ganham com isso são o `confere_saidas`,
que pega o caso de editar uma placa e commitar sem regerar — aí gerbers, BOM,
PDF e renders passam a descrever uma placa que não existe mais —, e o
`confere_alinhamento`, que é o único a enxergar a relação **entre** as duas
placas. Uma tira espelhada passa em ERC e em DRC, porque cada placa é válida
sozinha; o que não existe é o casamento entre elas.

O job do KiCad só se tornou possível depois que os caminhos absolutos saíram
do `netlist.py` e do `netlist_exp.py`: dentro do container eles resolviam
para `F:/downloads/...`, o disco da máquina de origem.

## O pacote de release

```bash
python tools/monta_pacote.py v1.0
```

Monta em `dist/` o que alguém precisa para **mandar fabricar e montar** — os
dois gerbers, a lista de material, o `.jed`, os renders, os esquemáticos e os
três documentos — e fecha num `.zip`. Ficam de fora os fontes do KiCad e o
`tools/` (quem quer modificar clona o repositório), o `posicoes.csv` (é
pick-and-place, e aqui tudo é passante montado à mão) e a ROM do Spectrum 128
(copyright da Amstrad/Sky).

Não é para rodar à mão a cada versão: quem publica é o
[`release.yml`](../.github/workflows/release.yml), disparado por uma tag
`v*`, **depois** que os seis conferidores passam. O comando acima serve para
conferir o resultado antes de criar a tag.

Duas coisas que o script faz e que não são óbvias:

1. **A tag tem que bater com a serigrafia da placa.** O `.kicad_pcb` traz
   `LRRosa 2026 v1.0`, e uma tag divergente aborta a montagem. O número no
   cobre é o que fica na mão de quem monta — se o download disser outra
   coisa, a placa e o arquivo contam histórias diferentes.
2. **Os links dos `.md` são reescritos.** Os que apontam para arquivos que
   entram no pacote continuam relativos; os que apontam para fora (como
   `../tools/galgen.py`) viram URL do GitHub na tag. No fim o próprio
   `confere_links.py` roda sobre o pacote montado, então link quebrado
   derruba a geração em vez de sair no zip.

## Como saber se as saídas estão atualizadas

```bash
python tools/confere_saidas.py
```

As duas maneiras óbvias de responder isso **não funcionam** neste projeto, e vale
saber por quê antes de tentar:

| Tentativa | Por que falha |
| --- | --- |
| comparar **data** dos arquivos | O `kicad-cli` reescreve a `.kicad_pcb` byte a byte idêntica ao rodar `export` e `render`. A placa fica sempre "mais nova" que os derivados dela, e a comparação acusa defasagem que não existe |
| comparar **conteúdo** | Gerber, `.drl`, `.gbrjob` e PDF carregam a data de geração embutida. E o **raytracer dos renders não é determinístico**: duas rodadas seguidas dão PNGs diferentes com a placa intacta |

Então `producao.sh` registra o hash das **fontes** em `production/fontes.json`, e
`confere_saidas.py` compara. Se bate, as saídas foram geradas desta versão das
placas. Sai com código 1 se não bate, então serve em hook ou CI.

## A outra verificação de regressão

```bash
python tools/confere_compatibilidade.py
```

A placa serve em TK90X/TK95 **e** em ZX Spectrum 48K, e isso se resume a uma
regra: dos 54 contatos do barramento, **nove não carregam a mesma coisa nas duas
máquinas** (4, 7, 15, 16, 17, 18, 34, 35, 37), e a placa não pode tocar nenhum.
O script cruza as ressalvas de `busdef.py` com os contatos que a netlist usa e
falha se algum aparecer. Rodar depois de qualquer mexida em `busdef.py` ou
`netlist.py` — e antes de repetir a afirmação de compatibilidade em qualquer
lugar.

## A verificação que vale rodar sempre

```bash
"$KIPY" confere_alinhamento.py
```

As duas placas se encaixam por solda, não por conector — nada no KiCad amarra
uma à outra. Cada uma passa em ERC e DRC isoladamente mesmo se a tira estiver
espelhada; o erro só apareceria na bancada, com o barramento invertido ponta a
ponta. Esse script fecha essa lacuna: confere que a coluna de cada pino, a
guia, as faces das fileiras e a fileira junto à aresta batem entre as duas.

Ele também confere a **numeração serigrafada**. As ilhas e os dedos são SMD —
cada pino existe em uma face só —, então a serigrafia de uma face não pode
nomear o pad da outra: na coluna x=73,66 o cobre de `F.Cu` é o pino 56 e o de
`B.Cu` é o pino 1. O script acha, para cada rótulo numérico, o pad mais próximo
*naquela face* e exige que o número bata.

## Por que gerado

O barramento do TK tem 56 posições e a numeração dele (1..56) não bate com a
convenção A/B do ZX Spectrum. Descrever isso uma vez em `busdef.py` e derivar
símbolo, footprint, esquemático e placa a partir dali elimina a classe de erro
mais provável neste tipo de projeto: um pino trocado entre o desenho e a placa.

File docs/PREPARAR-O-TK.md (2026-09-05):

# Preparando o TK90X / TK95

A TKMEM-128 II mapeia a SRAM externa em `0x8000-0xFFFF`. Como o banco superior de
32 KB do TK ocupa exatamente essa faixa, **os dois brigariam pelo barramento**.
Desativar essa RAM interna é a **única alteração necessária dentro do micro**.

> **TK90X de 16 KB não precisa de nada** — esse modelo não tem o banco de 32 KB.

Há três caminhos, do mais bruto ao mais elegante.

---

## 1. Remover os CIs de RAM

O jeito mais direto: arrancar os **quatro chips 4416**. Só é prático se estiverem
soquetados na sua unidade.

Definitivo enquanto os chips estiverem fora, e trivial de reverter (é só
recolocá-los).

---

## 2. Desabilitar por lógica — um fio

Se os chips estiverem soldados direto na placa e você não quiser dessoldá-los:

Solde um fio ligando o **pino 10 ao pino 14 do IC27** (um 74LS32, que fica no
canto da placa, perto dos CIs de RAM).

Pronto — 32 KB desabilitados. A desvantagem é que o TK fica permanentemente com
16 KB quando a interface não está conectada.

---

## 3. Auto-desativação — o método recomendado

Faz o TK voltar a ser 48 KB sozinho quando você desconecta a interface.

1. Solde um fio do **pino 29 do conector de expansão** até o **pino 10 do IC27**
   (74LS32).
2. Confirme a ligação com multímetro no teste de continuidade **antes de ligar o
   micro**.
3. Nada a fazer na TKMEM-128 II: `R4` já mantém o pino 29 em nível 1
   permanentemente.

Ao remover a interface o pino fica flutuando e o TK volta a operar como 48 KB.
Transparente, e **sem jumper nenhum para configurar**.

> **Atenção ao lado da placa.** O pino 29 está na **fileira de cima** (29..56),
> ou seja, na face da placa do TK oposta à dos pinos 1..28. Se você já viu as
> fotos da modificação original — que usava o pino 17 —, o ponto de solda agora é
> do outro lado da placa-mãe.

### Por que o pino 29

Porque ele é **não-conectado nas duas máquinas**, TK e ZX Spectrum:

```
    fileira de cima (vista da interface, esquerda -> direita)
    [29] 30 31 32 33 34 35 36 37 38 39 40 41 42 43 44 ... [52=guia] ... 56
    ^^^^
    N.C. no TK e no Spectrum (onde é chamado de 28A)

    fileira de baixo
     1  2  3  4 [ 5=guia]  6  7  8  9 10 11 12 13 14 15 16 [17] 18 19 20 ...
                                                            ^^^^
                                              N.C. no TK, mas V do vídeo
                                              componente no ZX Spectrum
```

No TK isso está confirmado na pinagem oficial arquivada em [`docs/`](.), que
marca o 29 como `N.C.`, e nas fotos da placa, onde o dedo não tem trilha
nenhuma. No Spectrum, o 28A também é livre.

**Consequência prática:** o pull-up de `R4` pode ficar permanente. Num Spectrum
não há nada ligado nesse contato, então nada acontece; num TK ele faz exatamente
o que tem que fazer. Foi por isso que **o jumper JP4 deixou de existir** neste
projeto.

> A placa original da Luccas usava o **pino 17**, que é livre no TK mas é o
> **V do vídeo componente no ZX Spectrum** — e por isso precisava de um jumper e
> de um aviso. Um jumper cuja posição errada estraga o micro é um risco que não
> precisa existir. Se você tem uma placa antiga com JP4, o aviso continua
> valendo: **nunca feche JP4 num Spectrum**.

Se algum dia quiser liberar o pino 29 — por exemplo para um periférico que o use
—, basta **não montar R4**.

--- | --- | --- |
| 16, 17, 18 | N.C. | Y, V, U do vídeo componente |
| 34, 35 | 12 V | +12 V / −12 V |
| 37 | **+5 V** | **−5 V** |
| 7 | N.C. | GND |
| 15 | GND | sinal |

Escolher a posição "Spectrum" num TK mandaria o sinal de desativação — que é
nível 1 injetado sem resistor de série na placa original — para um pino que no TK
é trilho de alimentação. Curto entre fontes explica bem um aviso em letras
garrafais.

**Aqui esse risco não existe**, e por dois motivos: não há jumper para pôr na
posição errada, e o sinal vai para o pino 29, que é N.C. nas duas máquinas.
`R4` de 1 kΩ em série continua limitando corrente — é mais firme que o pull-up de
10 kΩ da placa original, que já bastava.

---

## E num ZX Spectrum 48K?

A placa serve — o barramento é compatível contato a contato, ver
[Compatibilidade](../README.md#compatibilidade) — mas **esta página não serve**.
Ela descreve o interior do TK.

O que vale igual: os 32 KB superiores de RAM interna também têm que sair de
`0x8000-0xFFFF`, senão colidem com a SRAM da placa. O que muda é **o ponto
interno onde se faz isso**, e ele depende da revisão da placa-mãe:

| Issue | Componente | Fio |
| --- | --- | --- |
| 2, 3 e 4 | `IC23`, um **74LS32** | do **pino 5** ao **pino 14** (+5 V) |
| 5 e 6 | `IC27`, o **ZX8401** | do **pino 35** ao **pino 40** (+5 V) |

O efeito é o mesmo nos dois casos e é o mesmo do TK: segurar `CAS`/`RAS` em
nível alto para que não chegue aos chips de RAM de cima. Repare que a versão
Issue 2/3/4 é literalmente o mesmo tipo de intervenção que a do TK — forçar a
entrada de uma porta do 74LS32 para +5 V —, só que noutra porta e noutro CI.

**Teste rápido de que o fio ficou certo:** com o mod feito e a interface
*desconectada*, o micro tem que se comportar como um **Spectrum de 16K**.

> ⚠️ **`IC27` não quer dizer a mesma coisa nas duas máquinas.** No TK90X/TK95 o
> `IC27` é o 74LS32 desta página; num Spectrum Issue 5/6 o `IC27` é o ZX8401 —
> outro chip, outro pino, 40 pinos em vez de 14. Lendo os dois procedimentos
> lado a lado é fácil trocar. Confira o que está escrito no encapsulamento
> antes de soldar.

**De onde veio isto:** do [goloskokovic/zx16to128upgrade](https://github.com/goloskokovic/zx16to128upgrade),
que redistribui o mesmo projeto do Velesoft de onde este aqui deriva.
**Não verificamos em bancada** — não temos a máquina aqui. Se você fizer, uma
[issue](https://github.com/lrrosa/tkmem128-ii/issues) dizendo se funcionou é
bem-vinda.

Sem esse fio, o pull-up de `R4` não chega a lugar nenhum — e isso vale para as
**duas** máquinas, não só para o Spectrum. O contato 29 é `N.C.` no TK e no
Spectrum, e é justamente isso que torna a placa segura nas duas: ela nunca
injeta 5 V num contato que já tenha função.

A diferença entre as duas máquinas não está no barramento, está no
**procedimento**. No TK o fio vai do contato 29 até o ponto interno, e a
desativação passa a acompanhar a presença da interface. O mod publicado para o
Spectrum amarra o pino do mod ao +5 V do próprio CI, sem passar pelo conector —
então ali a desativação é permanente, e o micro só volta a ser 48K desfazendo a
solda. Se dá para mudar isso é o assunto da seção seguinte.

### Dava para levar a auto-desativação para o Spectrum?

A pergunta é natural: em vez de amarrar o pino do mod ao +5 V do próprio chip,
por que não ligá-lo ao **contato 29**, como fazemos no TK, e ganhar a mesma
comodidade — tirou a interface, voltou a ser 48K?

Em princípio sim, é a mesma topologia. Mas há uma diferença elétrica que decide
o caso, e ela é fácil de passar despercebida:

> **O contato 29 não é +5 V. É +5 V através de `R4`, 1 kΩ.**
> O mod publicado liga o pino do mod ao **pino de alimentação do próprio CI** —
> impedância zero. `R4` é um pull-up fraco, e pull-up fraco só vence quem não
> está brigando.

| O que houver no ponto do mod | O que o pull-up de 1 kΩ faz |
| --- | --- |
| Nada (entrada solta) ou pull-down ≥ 4k7 | **segura em nível alto com folga** — 4,1 V ou mais |
| Saída TTL-LS puxando para baixo | **perde**: ela absorve 8 mA e o `R4` só injeta 5 mA |

E há um indício de que o ponto do Spectrum é do segundo tipo: **se o pino 5 do
IC23 já ficasse alto sozinho, o mod não precisaria existir**. Amarrá-lo ao +5 V
só faz sentido porque alguma coisa o mantém baixo — e essa alguma coisa
provavelmente é uma saída, que ganharia do `R4`.

Compare com o TK, onde o truque funciona: ali a placa original do Luccas usava
pull-up de **10 kΩ** e bastava. Um ponto que se deixa levar por 10 kΩ é um ponto
de alta impedância, não uma saída em disputa. As duas máquinas simplesmente não
oferecem o mesmo tipo de nó.

**O que precisaria acontecer para funcionar**, se alguém quiser tentar:

1. **Cortar a trilha** que alimenta a entrada do mod, para que ela pare de ser
   disputada;
2. acrescentar um **pull-down** nessa entrada (10 kΩ para GND serve: com o `R4`
   de 1 kΩ o nó vai a 4,55 V com a interface, e a 0 V sem ela);
3. ligar a entrada ao **contato 28A/29** do conector.

Aí sim o comportamento fica igual ao do TK. Sem o passo 2 o resultado é o
oposto do desejado: entrada de LS solta flutua **alta**, e o micro ficaria em
16K justamente quando a interface fosse removida.

> **Nada disto foi verificado por nós, nem em bancada nem em esquemático** — não
> temos a máquina nem o desenho da Issue aqui. Antes de cortar trilha nenhuma,
> meça o pino do mod com o micro ligado: se ele chaveia, é saída, e o caminho é
> este; se fica parado num nível, meça a impedância para GND com o micro
> desligado. E conte o resultado numa
> [issue](https://github.com/lrrosa/tkmem128-ii/issues).

O que **não** muda em nenhum cenário: a placa já faz a parte dela. `R4` está lá,
o contato 29 é N.C. nas duas máquinas, e nada precisa ser alterado no hardware
para tentar.

---

## Conferindo

Com a interface conectada, ligue o TK. Ele deve iniciar
normalmente. Em BASIC:

```basic
PRINT PEEK 23732 + 256 * PEEK 23733
```

Isso mostra o topo da RAM (`RAMTOP`/P-RAMT). Num TK com os 32 KB desativados e a
interface ativa, você tem os 128 KB paginados disponíveis pela porta `0x7FFD` —
o teste real é carregar um jogo de 128 KB.

---

## Fontes

O procedimento vem do artigo **"Preparando o TK90X/TK95 para a TKMEM-128"**, de
Eduardo Luccas (Luccas Eletrônica), que documentou os três métodos com fotos da
placa do TK indicando o IC27 e o ponto do barramento.

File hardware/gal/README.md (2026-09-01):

# GAL20V8B — decodificador da TKMEM-128 II

O GAL faz toda a decodificação de endereços da placa: seleciona ROM e SRAM,
gera o clock do latch da porta `0x7FFD` e produz os bits altos de endereço da
SRAM a partir do banco selecionado.

## Pinagem

Nome do pino = **função programada** (o símbolo no esquemático usa esses nomes).

```
                       ._____    _____.
                       |     \__/     |
                  MREQ |  1        24 | VCC
                 ZX512 |  2        23 | IORQ
                    A1 |  3        22 | SA14
                    WR |  4        21 | SA15
                DIS128 |  5        20 | SA16
                 BANK2 |  6        19 | /RAMCS
                    A5 |  7        18 | /SA17
                 BANK0 |  8        17 | SA18
                 BANK4 |  9        16 | CLK7FFD
                 BANK3 | 10        15 | /ROMCS
                 BANK1 | 11        14 | A14
                   GND | 12        13 | A15
                       |______________|
```

Entradas: 14 pinos dedicados. Saídas: 8, todas combinatórias com habilitação
permanente. Uso de termos-produto: 18 de 64 (28%) — sobra folga para
modificações.

## As equações

```
/ROMCS  = /MREQ * /A14 * /A15
/RAMCS  = /MREQ *  A15
CLK7FFD = /IORQ * /WR * /A15 * A5 * /A1
        + DIS128
SA14    =  A14 * A15 * BANK0
SA15    =  A14 * A15 * BANK1
        + /A14 * A15
SA16    =  A14 * A15 * BANK2
/SA17   =  A14 * A15 * BANK3 * /ZX512
SA18    =  A14 * A15 * BANK4 * /ZX512
```

Três detalhes que não são óbvios:

1. **`+ DIS128` no clock é a trava de paginação.** Quando o bit 5 da porta
   `0x7FFD` é setado, `CLK7FFD` fica preso em nível alto, o latch nunca mais é
   clocado e a paginação trava até o reset — exatamente o comportamento do
   Spectrum 128.
2. **O termo `/A14 * A15` de `SA15`** fixa o banco 2 na janela `0x8000-0xBFFF`,
   independente do que estiver no latch. Só `0xC000-0xFFFF` é paginado.
3. **`SA17` acumula duas funções.** No modo 512K é o bit A17 da SRAM. No modo
   128K (`ZX512` em nível alto, JP3 aberto) a saída fica permanentemente em
   nível alto e serve de `CE2` da `AS6C1008` — que é ativo alto no pino 30.

## Gravando

**Já vai pronto: [`tkmem128.jed`](tkmem128.jed).** Abra no programador, escolha o
dispositivo e grave. Não precisa montar nada.

| | |
| --- | --- |
| Arquivo | `tkmem128.jed` |
| Dispositivo | `GAL20V8B` (Lattice), `ATF20V8B` (Microchip) ou `PALCE20V8H` (AMD/Vantis) |
| Fusíveis | 2706 |
| **Checksum de fusíveis** | **`C5752`** |
| Programador | XGecu T48/T56 (Xgpro) ou equivalente |

Confira o checksum que o software do programador mostra ao abrir o arquivo: tem
que dar `C5752`. Se der outro valor, o arquivo foi corrompido no download.

### De onde vem esse arquivo

O `.jed` **não foi copiado de lugar nenhum** — é gerado por
[`tools/galgen.py`](../../tools/galgen.py) a partir das equações deste projeto:

1. O script monta o mapa de fusíveis do GAL20V8 diretamente das equações
   (matriz AND, polaridade das saídas, habilitação dos termos e bits de modo).
2. O mapa de colunas da matriz AND é **deduzido das próprias equações**, não
   chutado — e depois conferido por consistência entre as oito saídas.
3. O resultado é comparado, fusível a fusível, com o mapa de referência do
   projeto do Velesoft.

O resultado dessa comparação:

```
fusiveis divergentes: 0 de 2706
checksum de referencia: 5752
checksum reconstruido : 5752
```

Ou seja: está provado que o arquivo distribuído implementa **exatamente** as
equações documentadas aqui, e que essas equações são as mesmas do projeto
original. Para reproduzir a verificação você só precisa de um `.jed` de
referência e do Python:

```bash
python tools/galgen.py caminho/para/referencia.jed
```

### Montando a partir do fonte, se preferir

O [`tkmem128.pld`](tkmem128.pld) está em sintaxe **GALasm** (compatível com
`galasm`, derivado do GALer):

```bash
galasm tkmem128.pld
```

Vale lembrar que montadores diferentes podem escolher modos diferentes do GAL
(*simple* × *complex*) e produzir mapas distintos, ainda que funcionalmente
equivalentes. O `.jed` distribuído usa o modo **complex** (SYN=1, AC0=1), que é
o do projeto original.

### Peças que servem

| Peça | Situação |
| --- | --- |
| **GAL20V8B-15LP** (Lattice) | Descontinuada; ainda comum como estoque antigo |
| **ATF20V8B-15PC** (Microchip) | Substituta pino a pino, ainda distribuída — a mais fácil de achar nova |
| **PALCE20V8H-15/-25** (AMD/Vantis/Lattice) | Serve; CMOS EEPROM, regravável. Ver as duas ressalvas abaixo |

Todas são DIP-24 de 300 mil e gravam com **o mesmo mapa de 2706 fusíveis** — o
`.jed` deste diretório serve nas três sem alteração. O modo **complex** que o
projeto usa (SYN=1, AC0=1, todas as saídas combinatórias em tristate) é
justamente a emulação de um PAL20L8, que é o que a PALCE20V8H faz nativamente.

Duas ressalvas para a PALCE20V8H:

1. **Selecione `PALCE20V8H` no software do programador, não `GAL20V8`.** O mapa
   de fusíveis é idêntico, mas o algoritmo de gravação (tensões e sequência) é
   outro. Gravar com o perfil errado falha na verificação — ou grava torto.
2. **Ela consome mais que a ATF20V8B**, e as versões rápidas (`-5`, `-7`)
   consomem bem mais. Prefira `-10`, `-15` ou `-25`. Velocidade aqui não é
   problema: com o barramento a 3,5 MHz há mais de 500 ns entre o endereço
   ficar válido e o Z80 amostrar o dado, contra os 25 ns do pior caso da peça
   mais lenta. A corrente é que pesa, porque tudo sai dos 5 V do micro.

## Mapa de colunas da matriz AND

Deduzido do mapa de fusíveis e confirmado pelas oito equações:

| Coluna | Sinal | | Coluna | Sinal |
| --- | --- | --- | --- | --- |
| 1 | `/ZX512` | | 24 | `BANK0` |
| 3 | `/MREQ` | | 28 | `BANK4` |
| 5 | `/A1` | | 32 | `BANK3` |
| 7 | `/WR` | | 34 / 35 | `A14` / `/A14` |
| 9 | `A5` | | 36 | `BANK1` |
| 12 | `DIS128` | | 38 / 39 | `A15` / `/A15` |
| 16 | `BANK2` | | 20 | `/IORQ` |

Quatro literais (`/IORQ`, `/WR`, `A5`, `/A1`) só aparecem juntos num mesmo termo
produto, então a atribuição entre eles é intercambiável — como AND é comutativo,
qualquer permutação dentro desse grupo dá o mesmo mapa de fusíveis.

## Modificando

Se for alterar as equações, lembre que:

- `SA14..SA18` precisam continuar sendo uma permutação bijetora sobre os bits de
  endereço alto da SRAM — qualquer embaralhamento entre eles é inofensivo, desde
  que consistente, porque nada mais acessa essa memória.
- O mesmo **não vale** para a EPROM: o conteúdo dela é fixo, então endereços e
  dados têm que ser 1:1 com o barramento.
- Sobram 46 termos-produto livres, mas apenas 8 saídas físicas.

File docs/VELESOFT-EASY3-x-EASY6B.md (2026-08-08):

# As duas variantes do Velesoft: `EASY_3` e `EASY_6b`

Este projeto deriva da **`zx48_to_128-EASY_3`** do Velesoft (Pavel Cimbal, 2009).
Existe uma variante posterior, **`EASY_6b`**, que circula nos mesmos pacotes —
por exemplo em [goloskokovic/zx16to128upgrade](https://github.com/goloskokovic/zx16to128upgrade),
que credita o Velesoft e aponta para
[a página original](https://velesoft.speccy.cz/zx/external_128kb_upgrade/index.htm).

Esta página registra o que foi comparado, para ninguém precisar refazer.

## O `EASY_3` de terceiros é o mesmo que o nosso

Os cinco arquivos do `EASY_3` naquele repositório têm **exatamente o mesmo
tamanho** dos que estão preservados aqui, e as nossas cópias são as do pacote
original de 2009:

| Arquivo | Bytes |
| --- | --- |
| `zx48_to_128-EASY_3.sch` | 109 065 |
| `zx48_to_128-EASY_3.brd` | 23 427 |
| `zx48_to_128-easy_3.eqn` | 545 |
| `zx48_to_128-easy_3.jed` | 3 432 |
| `zx48_to_128-easy_3.log` | 3 318 |

O `.jed` daqui tem `QF2706` e checksum **`5752`**, e o `tools/galgen.py`
reconstrói esse mapa de fusíveis a partir das equações deste projeto com **zero
divergências**. Ou seja: o GAL que gravamos é o do Velesoft, bit a bit.

## O `EASY_6b` é outra arquitetura de memória

Comparando as equações lado a lado (`.eqn` de 545 contra 605 bytes):

| Saída | `EASY_3` — o nosso | `EASY_6b` |
| --- | --- | --- |
| `/ROMCS` | `/MREQ*/A14*/A15` | igual |
| `/RAMCS` | `/MREQ*A15` | **`+ /MREQ*A14`** |
| `CLK7FFD` | `/IORQ*/WR*/A15*A5*/A1 + DIS128` | **`+ DIS128*ZX512`** no lugar de `+ DIS128` |
| `SA14` | `A14*A15*BANK0` | **`+ A14*/A15`** |
| `SA15` | `A14*A15*BANK1 + /A14*A15` | igual |
| `SA16` | `A14*A15*BANK2` | **`+ A14*/A15`** |
| `/SA17` | `A14*A15*BANK3*/ZX512` | igual |
| `SA18` | `A14*A15*BANK4*/ZX512` | igual |

Duas mudanças de fundo:

**1. A janela `0x4000-0x7FFF` passa a ser decodificada.** No `EASY_3`, `RAMCS`
só responde com `A15=1`, então a SRAM externa cobre `0x8000-0xFFFF` e a faixa de
baixo continua sendo a RAM interna que a ULA lê. No `EASY_6b`, `RAMCS` também
responde com `A14=1`; e como `SA14` e `SA16` ganham o termo `A14*/A15`, nessa
janela o endereço de banco vira `SA = 0b101` — **banco 5**, que é justamente o
banco de tela do Spectrum 128.

**2. A trava de paginação fica condicionada ao modo.** No `EASY_3`, setar o bit 5
(`DIS128`) prende o clock do latch em nível alto e a paginação trava até o reset,
em qualquer modo. No `EASY_6b` isso só acontece com `ZX512` ativo — o que faz
sentido, porque no modo 512K os bits 6 e 7 da porta continuam sendo necessários.

## O esquemático do `EASY_6b` contradiz o `.eqn` dele

Os `.sch` são binário do Eagle, mas exportados em PDF e rasterizados dão para
ler. E aí aparece uma inconsistência **dentro do próprio pacote deles**:

**A folha do `EASY_6b` imprime, no quadro verde de equações, o conjunto do
`EASY_3`** — `/RAMCS = /MREQ*A15` sem o `+ /MREQ*A14`, `SA14 = A14*A15*BANK0`
sem o `+ A14*/A15`, e `CLK7FFD = ... + DIS128` sem o `*ZX512`. Ou seja, o
desenho diz uma coisa e o arquivo de equações ao lado diz outra.

**Quem ganha é o `.eqn`**, e quem decide é a tabela de uso de termos do relatório
do compilador (`zx48_to_128-EASY_6b.log`), porque ela é o que de fato foi
compilado:

| Saída | Termos no log do `6b` | `EASY_3` teria | `.eqn` do `6b` tem |
| --- | --- | --- | --- |
| `ROMCS`, `SA17`, `SA18` | 1 | 1 | 1 |
| `SA14`, `SA16`, `RAMCS` | **2** | 1 | **2** |

A comparação é interna à mesma tabela, mesma ferramenta, mesma contagem: as três
saídas de uma equação só ficam em 1 termo, e justamente `SA14`, `SA16` e `RAMCS`
— as três que o `.eqn` do `6b` engorda — aparecem com 2. **O quadro de texto da
folha é que ficou para trás.**

## O resto do `EASY_6b` é o `EASY_3`

Lado a lado, as duas folhas têm os mesmos quatro blocos e a mesma fiação: o
conector `ZX-EDGET`, o `GAL 20V8`, o `74HCT273N` e a `SRAM 128 KB`. O que o
`6b` acrescenta é **dois LEDs** junto do jumper `ZX128/512` e **desacoplamento
melhor** (100 µF + 100 nF em vez de dois cerâmicos). O `.sch` ser 2,4× maior é
bagagem do Eagle, não circuito.

## E o layout do `6b` diz para que máquina ele é

A serigrafia da placa `EASY_6b` traz, em letras grandes:

> `ZX 128/512/1024 kB MEMORY UPGRADE FOR ZX 16`

**"FOR ZX 16"** — é para um ZX Spectrum de **16 KB**, não de 48. E aí as
diferenças do `.eqn` param de parecer arbitrárias e passam a fazer sentido: num
16K não existe RAM interna acima de `0x7FFF`, então a SRAM externa tem de cobrir
`0x4000-0xFFFF` — que é exatamente o que `/RAMCS = /MREQ*A15 + /MREQ*A14` faz — e
a janela `0x4000-0x7FFF` tem de aparecer como **banco 5**, que é onde o Spectrum
128 põe a tela. Os termos `+ A14*/A15` em `SA14` e `SA16` são precisamente isso.

Ou seja: **o `EASY_6b` não é uma versão melhor do `EASY_3` para a nossa máquina.
É outra máquina.** E isso reforça, com um motivo melhor do que "conservadorismo",
a decisão de ficar no `EASY_3`.

O que continua **sem explicação**: como a ULA obtém os dados de vídeo se a
janela dela vem de fora. Não há hardware adicional no `6b` para arbitrar isso, e
o pacote não documenta a intervenção interna que essa variante exigiria. Fica
como pergunta em aberto — não é conclusão nossa que funcione.

Enquanto isso, a limitação que este projeto documenta continua valendo: **não há
shadow video aqui**, e os poucos jogos de 128K que dependem dele não funcionam.

## A nossa placa confere com a do Velesoft

Com o esquemático legível deu para comparar o que antes só se comparava pelas
equações. Duas diferenças, as duas deliberadas e nenhuma funcional:

**O latch da porta `0x7FFD`.** O Velesoft usa os flip-flops do `74HCT273` fora de
ordem: `D3` entra no FF1, `D6` no FF2, `D1` no FF3, e assim por diante. Nós
ligamos bit *n* no flip-flop *n*. O que importa é o mapeamento lógico, e ele é
**idêntico nos dois**:

| Bit | Função | Velesoft (pino de entrada → saída) | Nosso |
| --- | --- | --- | --- |
| 0 | `BANK0` | 8 → 9 | 3 → 2 |
| 1 | `BANK1` | 7 → 6 | 4 → 5 |
| 2 | `BANK2` | 14 → 15 | 7 → 6 |
| 3 | `VRAM` | 3 → 2 | 8 → 9 |
| 4 | `ROMA14` | 18 → 19 | 13 → 12 |
| 5 | `DIS128` | 17 → 16 | 14 → 15 |
| 6 | `BANK3` | 4 → 5 | 17 → 16 |
| 7 | `BANK4` | 13 → 12 | 18 → 19 |

`RESET` no `/CLR` (pino 1) e `CLK7FFD` no `CLK` (pino 11) são iguais.

**O endereçamento da SRAM.** O Velesoft **embaralha** as linhas: `A3` do micro vai
no `A2` da SRAM, `A2` no `A3`, `A7` no `A4`, `SA15` no `A8`, `SA14` no `A9`,
`SA16` no `A13`… Nós ligamos 1:1, `A0`→`A0` até `A13`→`A13` e `SA14`→`A14` até
`SA18`→`A18`.

Embaralhar é legítimo e é truque velho de roteamento: a SRAM não liga para qual
bit vai onde, desde que a ligação seja consistente. Com os 14 bits da CPU e os 5
do banco em posições fixas, cada valor de banco continua selecionando um conjunto
de 16 KB disjunto dos outros — só que não contíguo no endereço físico. Como nada
mais acessa essa SRAM, é invisível.

Ficamos no 1:1 porque a placa é de 4 camadas e o roteamento não precisou do
favor, e porque um mapa contíguo é mais fácil de depurar com analisador.

O resto bate: pinagem do GAL idêntica, `/RAMCS` no `/CS1`, `/SA17` no `CS2`
(que no `AS6C1008` é habilitação ativa em alto, e é por isso que essa saída do
GAL é invertida), `WR` no `/WE`, `RD` no `/OE`.

## Os layouts

Medidos nos PDFs, usando o passo de 2,54 mm do conector como régua:

| | Contorno | Camadas | Plano | Passagem do barramento |
| --- | --- | --- | --- | --- |
| `EASY_3` | ~77 × 41 mm | 2 | nenhum | não tem |
| `EASY_6b` | ~77 × 40 mm | 2 | nenhum | não tem |
| **TKMEM-128 II** | 78,7 × 66,0 mm | **4** | GND e +5 V inteiros | dedos de borda na tira |

As duas do Velesoft são **de duas camadas sem plano nenhum**: trilhas finas de
sinal e algumas bem gordas fazendo o papel de alimentação, que é como se fazia
placa caseira de dois lados. As três placas têm as mesmas **27 ilhas por
fileira** no conector — 28 colunas menos a guia —, o que confirma que o
barramento é o mesmo.

Nossa placa é maior por dois motivos que não são do circuito: ela precisa caber
na caixa Patola PB 085/3 (e ocupa a tampa inteira), e leva a **EPROM**, que o
Velesoft não tem — a 27C256 e o soquete dela vieram da adaptação do Luccas.

E nenhuma das duas do Velesoft tem **passagem do barramento**: quem as usa perde
o conector de expansão. A tira que resolve isso é herança do Luccas, e aqui
virou uma segunda PCB.

## Por que ficamos no `EASY_3`

Dois motivos, e o segundo só ficou claro depois de ler a serigrafia do `6b`:

1. A placa de 2012 do Luccas, da qual herdamos a adaptação ao TK, os jumpers e a
   divisão em duas placas, é construída sobre o `EASY_3`.
2. O `EASY_6b` **é para outra máquina** — um Spectrum de 16 KB, onde a RAM
   inteira vem de fora. Adotá-lo aqui não seria uma atualização, seria trocar de
   alvo.

E trocar as equações mudaria o que precisa ser desativado dentro do micro — que
é justamente a parte já específica de cada máquina e a que mais tem chance de
danificar alguma coisa se estiver errada.

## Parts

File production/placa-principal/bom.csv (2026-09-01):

Reference | Value | Footprint | Description
C1-C5 | 100n | Capacitor_THT:C_Disc_D5.0mm_W2.5mm_P5.00mm | Desacoplamento U1,Desacoplamento U2,Desacoplamento U3,Desacoplamento U4,Desacoplamento do conector
C6 | 10u | Capacitor_THT:CP_Radial_D5.0mm_P2.00mm | Reservatorio de entrada
D1 | LED | LED_THT:LED_D3.0mm | LED de energia (opcional)
J1 | Barramento TK | tkmem128:ZX_TK_Bus_Socket_56 | Conector de borda TE 5645235 soldado nesta placa. O corpo fica do lado OPOSTO aos componentes; os terminais atravessam e recebem a tira de expansao pelo lado dos componentes.
JP1 | SELECIONA ROM | Connector_PinHeader_2.54mm:PinHeader_1x03_P2.54mm_Vertical | 1-2 = ROM 128 (EPROM ativa) | 2-3 = ROM TK (EPROM desligada)
JP2 | ROMCS BARRAMENTO | Connector_PinHeader_2.54mm:PinHeader_1x03_P2.54mm_Vertical | Aberto = ROM do TK | 1-2 = aciona ROMCS pelo GAL | 2-3 = ROMCS fixo em 1
JP3 | ZX128/ZX512 | Connector_PinHeader_2.54mm:PinHeader_1x02_P2.54mm_Vertical | Aberto = 128K (AS6C1008) | Fechado = 512K (AS6C4008)
R2,R4 | 1k | Resistor_THT:R_Axial_DIN0207_L6.3mm_D2.5mm_P2.54mm_Vertical | Pull-up do modo ZX128/ZX512,Serie da auto-desativacao da RAM interna
R3 | 2k2 | Resistor_THT:R_Axial_DIN0207_L6.3mm_D2.5mm_P2.54mm_Vertical | Limitador do LED de energia (opcional)
R5 | 0R | Resistor_THT:R_Axial_DIN0207_L6.3mm_D2.5mm_P2.54mm_Vertical | Serie do ROMCS (0R; 100-470R se houver disputa)
TP1 | VRAM | TestPoint:TestPoint_THTPad_D1.5mm_Drill0.7mm | Bit 3 do 7FFD (shadow screen), sem uso nesta arquitetura
TP2 | CLK7FFD | TestPoint:TestPoint_THTPad_D1.5mm_Drill0.7mm | Clock do latch - trava em 1 quando DIS128 e setado
U1 | GAL20V8B | Package_DIP:DIP-24_W7.62mm_Socket_LongPads | Decodificador de enderecos (GAL20V8B, ATF20V8B ou PALCE20V8H)
U2 | 74HCT273 | Package_DIP:DIP-20_W7.62mm_Socket_LongPads | Latch da porta 0x7FFD
U3 | AS6C1008-55PCN | Package_DIP:DIP-32_W15.24mm_Socket_LongPads | SRAM 128Kx8 (ou AS6C4008 512Kx8 no modo ZX512)
U4 | 27C256 | Package_DIP:DIP-28_W15.24mm_Socket_LongPads | EPROM opcional com o par de ROMs do Spectrum 128

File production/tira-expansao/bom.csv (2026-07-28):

Reference | Value | Footprint | Description
J1 | Terminais do conector | tkmem128:ZX_TK_Bus_SolderPads_56 | Ilhas de solda nos terminais do conector de borda que atravessam a placa principal
J2 | Passagem | tkmem128:ZX_TK_Bus_Fingers_56 | Dedos de borda 56 vias - passagem do barramento a outros perifericos

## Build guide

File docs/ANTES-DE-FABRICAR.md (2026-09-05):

# Antes de mandar fabricar

Este projeto foi validado em software (**ERC e DRC zerados, netlist conferida
item a item contra a intenção de projeto**) e as duas placas já voltaram da
fábrica com a **continuidade conferida**. Mas nenhuma delas foi montada nem
ligada num micro real.

Os itens abaixo dependem de medir peças físicas ou de decisões que não dá para
verificar de dentro do KiCad. Confira antes de gastar dinheiro com PCB.

> **Conferência em papel — julho de 2026.** As duas placas foram impressas em
> escala 1:1 e comparadas com as peças reais. **Todas as medidas e alinhamentos
> bateram**, com uma correção: o rasgo da guia da tira passou de 5,0 para
> **7,0 mm** de profundidade (item 3). Isso confirmou as cotas do conector, o
> tamanho das placas e o encaixe na caixa.

> ✅ **Continuidade na placa fabricada — setembro de 2026.** As duas placas
> voltaram da fábrica e **todas as ilhas passaram no teste de continuidade**.
> Isso fecha a pendência que este documento carregava desde o início: os gerbers
> daqui produzem placas eletricamente corretas, com estas regras de fabricação e
> este número de camadas.
>
> **O que isso não cobre:** as placas ainda não foram montadas nem ligadas num
> micro. Os itens abaixo que dependem do *micro* — a fileira do conector
> (item 2), a chaveta (item 3), a polaridade do ROMCS (item 5) e a preparação
> descrita em [PREPARAR-O-TK.md](PREPARAR-O-TK.md) — continuam por confirmar na
> bancada, e são os que podem danificar o computador.

---

## 0. O formulário do pedido (o que não viaja nos gerbers)

Os gerbers descrevem **o cobre**. Empilhamento e acabamento não estão neles:
são campos que você preenche à mão no formulário da fábrica. Se esquecer, a
placa sai errada com os arquivos certos — e nos dois casos o erro **não aparece
na inspeção visual**.

| Campo do pedido | Placa principal | Tira de expansão | Detalhe |
| --- | --- | --- | --- |
| Camadas | **4** | 2 | [item 3b](#3b-a-placa-principal-é-de-4-camadas-crítico-no-pedido) |
| Acabamento | HASL serve | **ENIG (ouro)** | [item 4](#4-acabamento-dos-dedos-de-borda) |
| Chanfro 45° nos dedos | não se aplica | **sim** | [item 4](#4-acabamento-dos-dedos-de-borda) |
| Espessura | 1,6 mm | 1,6 mm | [item 8](#8-regras-de-fabricação) |

São **dois pedidos separados**, um `.zip` cada:
`production/placa-principal/gerbers.zip` e
`production/tira-expansao/gerbers.zip`. Não dá para pedir as duas juntas — o
número de camadas difere.

O chanfro (*gold finger beveling*) costuma ser uma caixinha à parte, fora do
bloco de opções principal, e é o item mais fácil de passar batido.

---

## 1. O conector de borda (cotas do datasheet)

**Onde:** placa principal, conector `J1`.

O conector é o **TE / AMP 5645235, "Standard Edge II", passo 2,54 mm**
(desenho de cliente arquivado em [`docs/`](.)). Cotas usadas no footprint:

| Dimensão | Valor |
| --- | --- |
| Passo entre contatos | 2,54 mm [.100] |
| **Distância entre as duas fileiras de terminais** | **4,85 mm [.191]** |
| **Furo recomendado na PCB** | **1,02 ± 0,08 mm [.040]** |
| Aceita placa de | 1,37 – 1,78 mm [.054–.070] |
| Altura do corpo acima da placa | 15,49 mm [.610] |
| Terminal abaixo da placa | 3,18 ± 0,51 mm [.125] |
| Largura do corpo | 9,35 mm [.368] |
| Chanfro da entrada | 1,52 × 45° [.060] |

A **guia** ocupa a posição das vias 5 e 52 — é um pedacinho de PCB que o
montador encaixa ali, casando com o rasgo entre os dedos do micro. Como não há
terminal nessa posição, o footprint tem **54 furos**, não 56.

**Onde a furação cai em relação à aresta.** A fileira de baixo (pinos 1–28) fica
a **2,885 mm** da aresta inferior — 2,135 mm de cobre até a borda. Não é sobra
gratuita: o corpo do conector tem 10 mm de fundo, e nessa posição ele termina
**0,31 mm dentro** do contorno da placa. Numa versão anterior a furação estava
1,5 mm mais para baixo, e o corpo sobrava 1,19 mm para fora — o contorno da PCB
cortava o conector, restavam 0,635 mm de cobre até a aresta e a serigrafia dele
tinha que ser um "U" aberto. A medida de 1,5 mm veio de conferir interfaces reais
de TK90X.

**Conferido em papel (jul/2026)** contra o conector real: as duas fileiras
(4,85 mm) e o furo (1,02 mm) batem. Ainda assim, **confira com paquímetro o
conector que você comprou** — modelos de outros fabricantes variam, e é aqui que
uma divergência de décimos custa a placa inteira.

---

## 1b. Orientação: componentes virados para a tira (CRÍTICO)

O conector é de **entrada vertical** — a placa que entra fica perpendicular
àquela em que ele está soldado. Por isso ele vai na placa **em pé**, e a fenda cai no
plano horizontal para receber a placa do micro.

O corpo do conector fica de **um** lado da placa e os terminais atravessam para
o **outro**, onde a tira de expansão é soldada.

> ⚠️ **O lado dos componentes tem que ficar virado para a tira de expansão.**
> Se a placa for montada ao contrário, com os componentes do lado do conector,
> ela esbarra no micro dentro da caixa e não encaixa direito.

Consequência prática: o conector é **o único componente do lado do cobre** da
placa principal. Você o encaixa por baixo e solda por cima, pelo lado dos
componentes. No projeto ele está atribuído à camada `B.Cu`, e é assim que
aparece na serigrafia do verso.

---

## 2. Qual fileira do conector é qual (CRÍTICO)

**Onde:** placa principal, conector `J1`.

O projeto assume, com a placa **em pé** e o conector na borda de baixo:

| Fileira de terminais | Pinos | Corresponde a |
| --- | --- | --- |
| a **de baixo**, junto à aresta inferior da placa | **1..28** | fileira de baixo do micro (fileira B no ZX Spectrum) |
| a **de cima**, do lado de dentro da placa | **29..56** | fileira de cima do micro (fileira A no ZX Spectrum) |

Ou seja: o pino 1 (`A14`) fica embaixo, junto da borda. É a mesma orientação
física da placa do micro, onde 1..28 é a fileira inferior.

Trocar as duas inverte a placa inteira e **pode danificar o micro** (alimentação
onde deveriam estar sinais).

Repare que o conector é montado **pelo lado do cobre**: no projeto ele está na
camada `B.Cu`, o que espelha o footprint — inserir a peça pelo outro lado
inverte a ordem das colunas *e* troca as duas fileiras. É a consequência física
de enfiar o conector por baixo, e é justamente por isso que este teste existe.

**O que fazer:** antes de soldar qualquer CI, monte só o conector `J1` na placa
principal e faça um teste de continuidade com o micro **desligado e desconectado**:

1. Encaixe a placa nos dedos do micro.
2. Meça continuidade entre o contato **3** do soquete (+5 V nas duas máquinas) e
   o ponto de +5 V do micro.
3. Meça o contato **6** (GND) contra o terra do micro.

Se +5 V e GND aparecerem trocados ou em contatos inesperados, a fileira está
invertida: gire o footprint 180° no eixo Y (troque as fileiras) e regenere.

---

## 3. A guia do conector

O conector de 56 vias vem **sem guia**. Onde ficariam os contatos **5 e 52**
você precisa encaixar um pedacinho de PCB (ou material equivalente, ~1,6 mm) que
sirva de guia, casando com o rasgo entre os dedos da placa do micro.

Sem isso, é fácil plugar deslocado por uma posição — e aí sinais e alimentação
vão para os lugares errados.

Do outro lado da corrente, a **tira** tem o rasgo correspondente entre os dedos
de `J2`: 1,8 mm de largura por **7,0 mm de profundidade**, centrado em
x = 63,50. A profundidade foi conferida contra a placa real em julho de 2026
(impressão em papel 1:1) — os 5,0 mm iniciais não chegavam ao fundo da guia.

Se algum dia precisar de mais profundidade, saiba que **restam só 0,62 mm**: os
dedos começam em y = 37,38 e o rasgo já vai até y = 38,00. Passar disso obriga a
encurtar os dedos também. A folga lateral para o cobre mais próximo (pinos 4, 6,
51 e 53) é de 0,88 mm.

O valor mora em `KEYSLOT_DEPTH`, em `tools/netlist_exp.py`; para aplicar numa
placa já roteada use `tools/ajusta_guia.py`, que refaz o contorno e repreenche
as zonas.

---

## 3b. A placa principal é de 4 camadas (CRÍTICO no pedido)

**Onde:** `production/placa-principal/gerbers.zip`.

Peça **4 camadas**, empilhamento padrão de 1,6 mm:

| Gerber | Papel |
| --- | --- |
| `tkmem128-ii-F_Cu.gbr` | sinal, lado dos componentes |
| `tkmem128-ii-In1_Cu.gbr` | **plano de GND** |
| `tkmem128-ii-In2_Cu.gbr` | **plano de +5V** |
| `tkmem128-ii-B_Cu.gbr` | sinal, lado do cobre |

Se pedir 2 camadas por engano, a fábrica descarta os dois planos e a placa sai
sem alimentação nenhuma — e isso não aparece na inspeção visual. Confira no
formulário antes de fechar.

A **tira de expansão continua de 2 camadas** e é pedida separadamente
(`production/tira-expansao/gerbers.zip`).

---

## 4. Acabamento dos dedos de borda

**Onde:** tira de expansão, `J2`.

Peça explicitamente à fábrica:

- **ENIG (ouro)** nos dedos — HASL descasca com a inserção repetida
- **chanfro de 45°** na borda dos dedos (às vezes chamado *gold finger
  beveling*); costuma ser item separado no pedido

O ENIG vale para a tira inteira: as ilhas de solda do outro extremo (`J1`)
também chegam à borda e ficam melhor sem HASL.

Sem chanfro, a placa entra forçando e arranha os contatos do conector do micro.

---

## 5. Polaridade do ROMCS

**Onde:** placa principal, `JP2`.

O sinal `ROMCS` do barramento (pino 25) é **ativo em nível alto** para desligar a
ROM interna, enquanto a saída do GAL (`/ROMCS`) é ativa em nível baixo. JP2
oferece as duas estratégias, mas **qual funciona no seu micro só o teste dirá**:

| JP2 | Comportamento |
| --- | --- |
| aberto | ROM interna do micro (comece por aqui) |
| 1-2 | Aciona `ROMCS` pela saída do GAL — comportamento da placa original |
| 2-3 | Fixa `ROMCS` em nível alto, estilo cartucho da Interface 2 |

`R5` fica em série. Comece com 0 Ω (fio). Se houver disputa de barramento
(imagem instável, travamentos ao usar a ROM 128), troque por 100–470 Ω.

Se você não vai usar a EPROM — e ela é dispensável, ver o README — deixe JP1 em
2-3 e JP2 aberto e nada disso importa.

---

## 5b. Alinhamento entre as duas placas (CRÍTICO)

Os dois layouts correm no **mesmo sentido de X**: a principal fica em pé com os
componentes virados para trás, a tira fica deitada com o cobre de cima virado
para cima e sai para trás. Logo, vistos nos respectivos layouts do KiCad:

| | Coluna do pino 1 | Guia (coluna sem contato) |
| --- | --- | --- |
| Conector `J1` da principal | x = 73,66 mm | x = 63,50 mm |
| Ilhas `J1` da tira | x = 73,66 mm | x = 63,50 mm |
| Dedos `J2` da tira | x = 73,66 mm | x = 63,50 mm |

Se a tira for desenhada espelhada, tudo continua com ERC e DRC zerados — os
dois projetos são válidos isoladamente — e a placa só falha na bancada, com o
barramento invertido ponta a ponta.

**Verificação automática:** rode
[`tools/confere_alinhamento.py`](../tools/confere_alinhamento.py) depois de
qualquer mexida em footprint, rotação ou posicionamento de conector. Ele
confere as colunas, a guia, as faces das fileiras e qual fileira fica junto à
aresta, e falha alto se algum invariante quebrar.

---

## 6. A tira de expansão é soldada, não encaixada

**Onde:** tira de expansão, `J1`.

A tira **não tem conector**. Os terminais do conector são **retos** e ficam em
duas fileiras a 4,85 mm; a tira entra **entre elas**, com uma fileira passando
por cima e a outra por baixo.

Por isso ela tem ilhas de solda nas **duas faces**, nas mesmas posições
(`J1`, 54 vias, passo 2,54 mm, sem furos), e **a solda é feita dos dois lados**:
por cima e por baixo. Do outro extremo ficam os dedos de borda (`J2`) para o
próximo periférico.

As ilhas **chegam até a aresta da tira** e entram 5 mm. Os terminais do TE
5645235 avançam 3,18 ± 0,51 mm, mas há conectores com terminal mais curto — com
a ilha começando na borda, o terminal encontra cobre em qualquer caso, e a
solda fica fácil independentemente de quanto a tira entra.

Isso é o que mantém tudo coplanar. Não substitua por um header: qualquer
conector empilhado reintroduz o degrau.

---

## 7. Caixa Patola PB 085/3

Conferido contra os desenhos técnicos da Patola (`PB 085/3_CX` e `PB 085/3_TP`).

| Medida | Valor |
| --- | --- |
| Caixa fechada (externo) | 32 × 73 × 85 mm |
| Tampa: área interna onde a placa assenta | **81 × 69 mm** |
| Tampa: profundidade interna | 6 mm |
| Caixa (metade funda): interna | 83 × 71 × 25 mm |
| Torres de fixação | Ø5 externo, furo Ø2,5, **58 mm entre centros**, centradas |

### A placa principal cabe

| | Disponível | Usado | Folga |
| --- | --- | --- | --- |
| Largura | 81 mm | 78,74 mm | 1,13 mm por lado |
| Altura | 69 mm | 66,04 mm | 1,48 mm por lado |
| Altura de componentes | ~25 mm | ~10 mm (soquete torneado + DIP) | ~15 mm |

### O furo `H1` — passagem da torre, não do parafuso

As torres ficam em **x = 39,37 mm** (centro) e **y = 4,02 e 62,02 mm** nas
coordenadas da placa, medidas conferidas contra a caixa real em impressão 1:1.

O ponto que engana: no desenho `PB 085/3_TP` a torre tem **Ø5 externo**; o Ø2,5
é só o furo-piloto **dentro** dela. E a placa assenta no fundo da tampa, que é de
onde a torre nasce. Ou seja, o furo na placa não é passagem de parafuso — é
**passagem da torre**. Com um furo de parafuso a placa simplesmente não desce:
para em cima da torre.

- A torre de **y = 62,02** cai exatamente sobre o conector `J1`. É a que se
  desgasta com micro-retífica ao abrir a fenda — não tem como ser furo.
- A de **y = 4,02** virou `H1`, **Ø5,4 não metalizado**: 0,2 mm de folga radial,
  que a conicidade de desmoldagem pede, porque é a **base** da torre — a parte
  mais larga — que encontra a placa.

Consequência boa: o parafuso da caixa corre dentro da torre e **nunca toca a
placa**. Não há questão de folga para a cabeça do parafuso, nem risco de parafuso
metálico raspar a parede do furo e encostar o plano de GND no de +5 V. `H1` é um
**pino de localização**, não um ponto de aperto — o que segura a placa continua
sendo o **EVA** colado no fundo e nas laterais, mais a fenda frontal por onde o
corpo do conector atravessa.

O que esse furo custou: **U4 recuou 1,5 mm para a esquerda**, senão ele entraria
no *courtyard* do soquete. Depois do recuo sobram 0,60 mm entre o cobre de U4 e a
aresta esquerda (a regra pede 0,30), e 2,91 mm entre o soquete e o furo. `H1` não
tem courtyard de propósito: nessa vizinhança não existe envelope livre para
declarar.

> Na furação, `H1` sai no mesmo `.drl` dos outros furos, declarado como
> `NonPlated,NPTH` (o arquivo é `MixedPlating`). Se a sua fábrica ignorar o
> atributo e metalizar tudo, não há curto: nenhum cobre chega à parede do furo em
> nenhuma das quatro camadas. Só avise, porque metalizado ele fica com a parede
> mais estreita e a torre pode não passar.

### O conjunto montado também cabe — mas só com a fenda aberta

O corpo do conector (15,49 mm) e a tira de expansão ficam **fora** do contorno
da tampa, na fenda cortada na base. Isso é inerente ao formato e é o que a
montagem original faz.

### Comprimento da tira de expansão

A tira sai da placa principal e atravessa a caixa pelo eixo de **32 mm**, indo
até fora para os dedos de passagem. Com **45 mm** ela cobre a travessia e ainda
sobra o suficiente do lado de fora. O conector do micro fica na frente, do lado
oposto — a tira não precisa alcançá-lo.

### Adaptação da caixa

Conforme documentado por Eduardo Luccas: abra duas fendas na base — uma maior
para o soquete de borda e uma menor para a passagem —, desgaste com
micro-retífica a torre que cair dentro da fenda, e fixe com **pedaços de EVA**
colados no fundo e nas laterais. A caixa fecha com trava, então o EVA segura bem.

---

## 8. Regras de fabricação

| Parâmetro | Placa principal | Tira de expansão |
| --- | --- | --- |
| Camadas | **4** | 2 |
| Espessura | 1,6 mm | 1,6 mm |
| Trilha | 0,5 mm | 1,5 mm |
| Isolação | 0,2 mm | 0,25 mm |
| Furo mínimo | 0,3 mm | sem furos |
| Via | 0,8 mm / furo 0,4 mm | nenhuma |
| Ilha do conector | 1,50 mm / furo 1,02 mm | — |

Nada disso é apertado: 0,2 mm de isolação e 0,5 mm de trilha estão muito acima do
mínimo de qualquer fábrica barata (JLCPCB e PCBWay especificam 0,127 mm). Uma
versão anterior deste projeto usava 0,25 mm de trilha com 0,14 de isolação para
caber em 2 camadas — foi abandonada justamente por ser apertada demais para
inspeção e retrabalho.

A **ilha de 1,50 mm no conector** não é arbitrária: com os 1,75 mm iniciais
sobravam 0,79 mm entre ilhas vizinhas, e nenhum sinal conseguia sair da fileira
de baixo (a fuga passa entre duas ilhas da fileira de cima, e uma trilha de
0,5/0,2 precisa de 0,90 mm). Se for mexer no footprint do conector, **não reduza
o vão abaixo de 0,90 mm**.

---

## Resumo

| Item | Risco se errar |
| --- | --- |
| 0. Formulário do pedido | Camadas ou acabamento errados — **não aparecem na inspeção visual** |
| 1. Cotas do conector | Conector não entra na placa |
| 1b. Orientação invertida | A placa esbarra no micro e não encaixa |
| 2. Fileira invertida | **Pode danificar o micro** |
| 3. Chaveta | **Pode danificar o micro** |
| 3b. Pedir 2 camadas em vez de 4 | **Placa sem alimentação** — não aparece na inspeção visual |
| 4. Acabamento dos dedos | Contato ruim, desgaste rápido |
| 5. ROMCS | ROM 128 instável (só afeta quem usa a EPROM) |
| 5b. Alinhamento das placas | **Barramento invertido ponta a ponta** — ERC/DRC não pegam |
| 6. Tira soldada | Empilhar conector reintroduz o degrau |
| 7. Caixa | Não fecha |
| 8. Regras de fabricação | Nenhuma folga é apertada; conferir só se a fábrica for muito básica |

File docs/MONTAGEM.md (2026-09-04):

# Montagem

Antes de começar, leia [ANTES-DE-FABRICAR.md](ANTES-DE-FABRICAR.md) — há itens
lá que, se estiverem errados, podem danificar o micro.

---

## Antes de tudo: a orientação

A placa principal fica **em pé** e o conector de borda é soldado nela. O corpo
do conector sai por **um** lado e os terminais atravessam para o **outro**, onde
a tira de expansão é soldada.

> ⚠️ **Os componentes vão do mesmo lado da tira de expansão.** O conector de
> borda é **o único componente do lado do cobre**: você o encaixa por baixo e
> solda por cima, pelo lado dos componentes. Montada ao contrário, a placa
> esbarra no micro dentro da caixa.

---

## Ordem de montagem

### Placa principal

1. **Resistores** R2, R4, R5 (e R3 se for usar o LED).
2. **Soquetes torneados** dos CIs — U1 (DIP-24), U2 (DIP-20), U3 (DIP-32),
   U4 (DIP-28). Use soquetes: a SRAM e o GAL são peças caras e o GAL você vai
   querer regravar.
3. **Capacitores** C1–C5 (100 nF) e C6 (10 µF, atenção à polaridade).
4. **Headers de jumper** JP1–JP3.
5. **LED D1** (opcional, atenção à polaridade).
6. **Conector de borda `J1`** — por último. Ele entra pelo **lado do cobre** e
   é soldado pelo lado dos componentes. Solde dois terminais das pontas,
   confira o esquadro, e só então o resto.
   A **guia**: encaixe um pedacinho de PCB de ~1,6 mm na posição **5/52** do
   conector (a placa não tem furos ali, justamente porque não há terminal),
   casando com o rasgo entre os dedos do micro.
7. Só então **encaixe os CIs** nos soquetes.

A numeração do conector está serigrafada **nas duas faces**, nas mesmas
posições: os terminais são passantes, então cada pino existe dos dois lados na
mesma coluna. Você vê `28`/`29` de um lado e `1`/`56` do outro — o pino 1 é o
da **ilha quadrada**. Qual deles aparece à esquerda depende de qual face você
está olhando; o traço vertical curto marca a coluna da guia (5/52) e serve de
referência rápida.

### Tira de expansão

Ela não tem componente nenhum: de um lado ilhas de solda, do outro dedos de
borda. As 54 ligações são retas verticais de **1,5 mm**, 27 em cada face, sem
uma via sequer — J1 e J2 estão nas mesmas colunas, então nada precisa cruzar.

Só há uma coisa a soldar além das ilhas: **o fio de terra `W1`**. Os pinos 6 e
14 do barramento são os dois GND. Cada um atravessa a tira reto, mas ligá-los
entre si exigiria cruzar 7 colunas, e as duas faces estão ocupadas pelas
verticais. Use um pedaço de **fio isolado** entre as duas ilhas marcadas
`GND - FIO ISOLADO`, no verso. Ele passa por cima das outras trilhas — por isso
o fio tem que ser isolado.

1. Enfie a tira **entre as duas fileiras** de terminais do conector, que são
   retos: uma fileira fica por cima da tira e a outra por baixo. Ela sai
   perpendicular à placa principal, no plano da placa do micro.
2. **Solde dos dois lados** — por cima e por baixo. Comece pelas duas pontas
   de cada face para travar o alinhamento, depois preencha o resto.
   As ilhas chegam até a aresta da tira, então não importa se o seu conector
   tem o terminal mais curto: sempre há cobre embaixo dele.
3. Confira com multímetro alguns pontos contra os dedos da outra extremidade
   antes de energizar.

Como as ilhas são SMD — uma face para cada pino — **a serigrafia de cada face
numera só os pinos daquela face**, nas duas extremidades da tira:

| Face | Pinos | O que está escrito nas pontas |
| --- | --- | --- |
| Frente (F.Cu) | 29..56 | `29` à esquerda, `56` à direita |
| Verso (B.Cu) | 1..28 | `1` à esquerda, `28` à direita |

Os números aparecem trocados de lado entre as faces porque você está olhando a
mesma placa por trás — o pino 1 e o pino 56 ocupam a **mesma coluna**, um em
cada face. O traço vertical mais próximo dessa ponta marca a coluna da guia
(onde ficariam os pinos 5 e 52), e serve de conferência rápida: ele tem que
cair no mesmo lugar na tira e no conector da placa principal.

Tira de expansão, verso

---

## Configuração inicial dos jumpers

Comece na configuração mais conservadora — só RAM, sem mexer em ROM:

| Jumper | Posição inicial |
| --- | --- |
| JP1 (SELECIONA ROM) | **2-3** (EPROM desligada) |
| JP2 (ROMCS BARRAM.) | **aberto** |
| JP3 (ZX128/ZX512) | **aberto** (128 KB) |

Nessa configuração U4 (a EPROM) nem precisa estar montada.

**Não há jumper de auto-desativação.** O sinal sai permanentemente por `R4` no
**pino 29**, que é não-conectado tanto no TK quanto no ZX Spectrum — logo não há
nada para configurar nem posição errada para escolher. Num Spectrum a placa
simplesmente não faz nada nesse contato.

---

## Primeiro teste

1. Micro **desligado**. Encaixe o conector da placa principal nos dedos dele,
   atenção à guia das posições 5 e 52.
2. Confira que os componentes estão virados para o lado da tira de expansão.
3. Ligue. O micro deve iniciar normalmente com a tela de sempre.
4. Carregue um jogo de 128 KB. Se rodar, a paginação está funcionando.

Se o micro não iniciar, desligue imediatamente e confira:

- a modificação do pino 29 (continuidade até o pino 10 do IC27)
- se os 32 KB superiores de RAM interna foram mesmo desativados
- orientação dos CIs nos soquetes
- o teste de continuidade do soquete de borda

### Pontos de teste

| Ponto | Sinal |
| --- | --- |
| TP1 | `VRAM` — bit 3 da porta `0x7FFD` (shadow screen; latcheado mas sem uso) |
| TP2 | `CLK7FFD` — clock do latch. Deve pulsar a cada escrita em `0x7FFD` e **travar em nível alto** depois que o bit 5 (`DIS128`) for setado |

---

## Modo 512 KB

Troque U3 por uma **AS6C4008** (512K×8, mesmo encapsulamento DIP-32) e feche
**JP3**. O software precisa saber usar os bits 6 e 7 da porta `0x7FFD` — jogos
comuns de 128 KB não usam.

> Com a SRAM de **128K×8**, JP3 fica **aberto**. Fechado por engano, o pino 30
> passa a receber `/SA17` paginado e a RAM em 0xC000 é desabilitada sempre que o
> software escrever `BANK3=1` — falha intermitente, difícil de diagnosticar.

Outras peças servem no lugar da `AS6C1008` e da `AS6C4008`: a regra e a lista
estão em [Equivalentes para U3](../README.md#equivalentes-para-u3-a-sram).

---

## A EPROM (opcional)

A ROM do Spectrum 128 **não vem neste repositório** (copyright da Amstrad/Sky) e
**não é necessária** para rodar jogos de 128 KB. Se quiser mesmo:

```bash
cat 128-0.rom 128-1.rom > rom_tkmem128_27c256.bin
```

Grave numa 27C256, encaixe em U4, e ponha **JP1 em 1-2** e **JP2 em 1-2**
(ou 2-3 — ver ANTES-DE-FABRICAR item 5). Use os dois juntos: JP1 sozinho deixa a
EPROM e a ROM interna disputando o barramento de dados.

---

## A caixa

Caixa **Patola PB 085/3** (32 × 73 × 85 mm fechada). A placa principal assenta na
**tampa**, cuja área interna é 81 × 69 mm — daí os 78,74 × 66,04 mm da placa.

| | Disponível | Usado |
| --- | --- | --- |
| Largura | 81 mm | 78,74 mm |
| Altura | 69 mm | 66,04 mm |
| Altura livre para componentes | ~25 mm | ~10 mm |

A tira de expansão tem **45 mm** e atravessa a caixa pelo eixo de 32 mm, saindo
pela traseira com os dedos de passagem. O conector do micro fica na frente, do lado
oposto da placa principal.

### Adaptando a caixa

1. Abra duas fendas: uma **na frente**, para o corpo do conector de borda sair
   e receber os dedos do micro, e uma **atrás**, para a tira de expansão passar.
   A da frente não é opcional: a abertura `EXPANSION` do micro é **recuada dentro
   da carcaça**, então a caixa encosta na traseira dele e o conector precisa
   atravessar a parede da caixa para alcançar a placa do micro. Ver a
   [vista de lado](img/vista-de-lado.svg).
2. Uma das torres de fixação (a de `y = 62,02 mm`, sob o conector `J1`) cai dentro
   da fenda maior e precisa ser desgastada com micro-retífica.
3. A outra torre (`y = 4,02 mm`) **passa pela placa**, pelo furo `H1` de
   **Ø5,4 não metalizado**. Ela é que localiza a placa; o parafuso da caixa
   corre por dentro dela e não encosta em nada.
4. Fixe as placas com **pedaços de EVA** colados no fundo e nas laterais — é como
   a montagem original resolve, e funciona bem porque a caixa fecha com trava.

> `H1` não é furo de parafuso: a torre da Patola tem **Ø5 externo** e o Ø2,5 do
> desenho é o furo-piloto dentro dela. Detalhes em
> [ANTES-DE-FABRICAR.md](ANTES-DE-FABRICAR.md#7-caixa-patola-pb-0853).

O resultado fica com a placa em pé dentro da caixa, o conector saindo pela
frente e a tira de expansão pela traseira — exatamente como a TKMEM-128
original e os demais periféricos do micro.

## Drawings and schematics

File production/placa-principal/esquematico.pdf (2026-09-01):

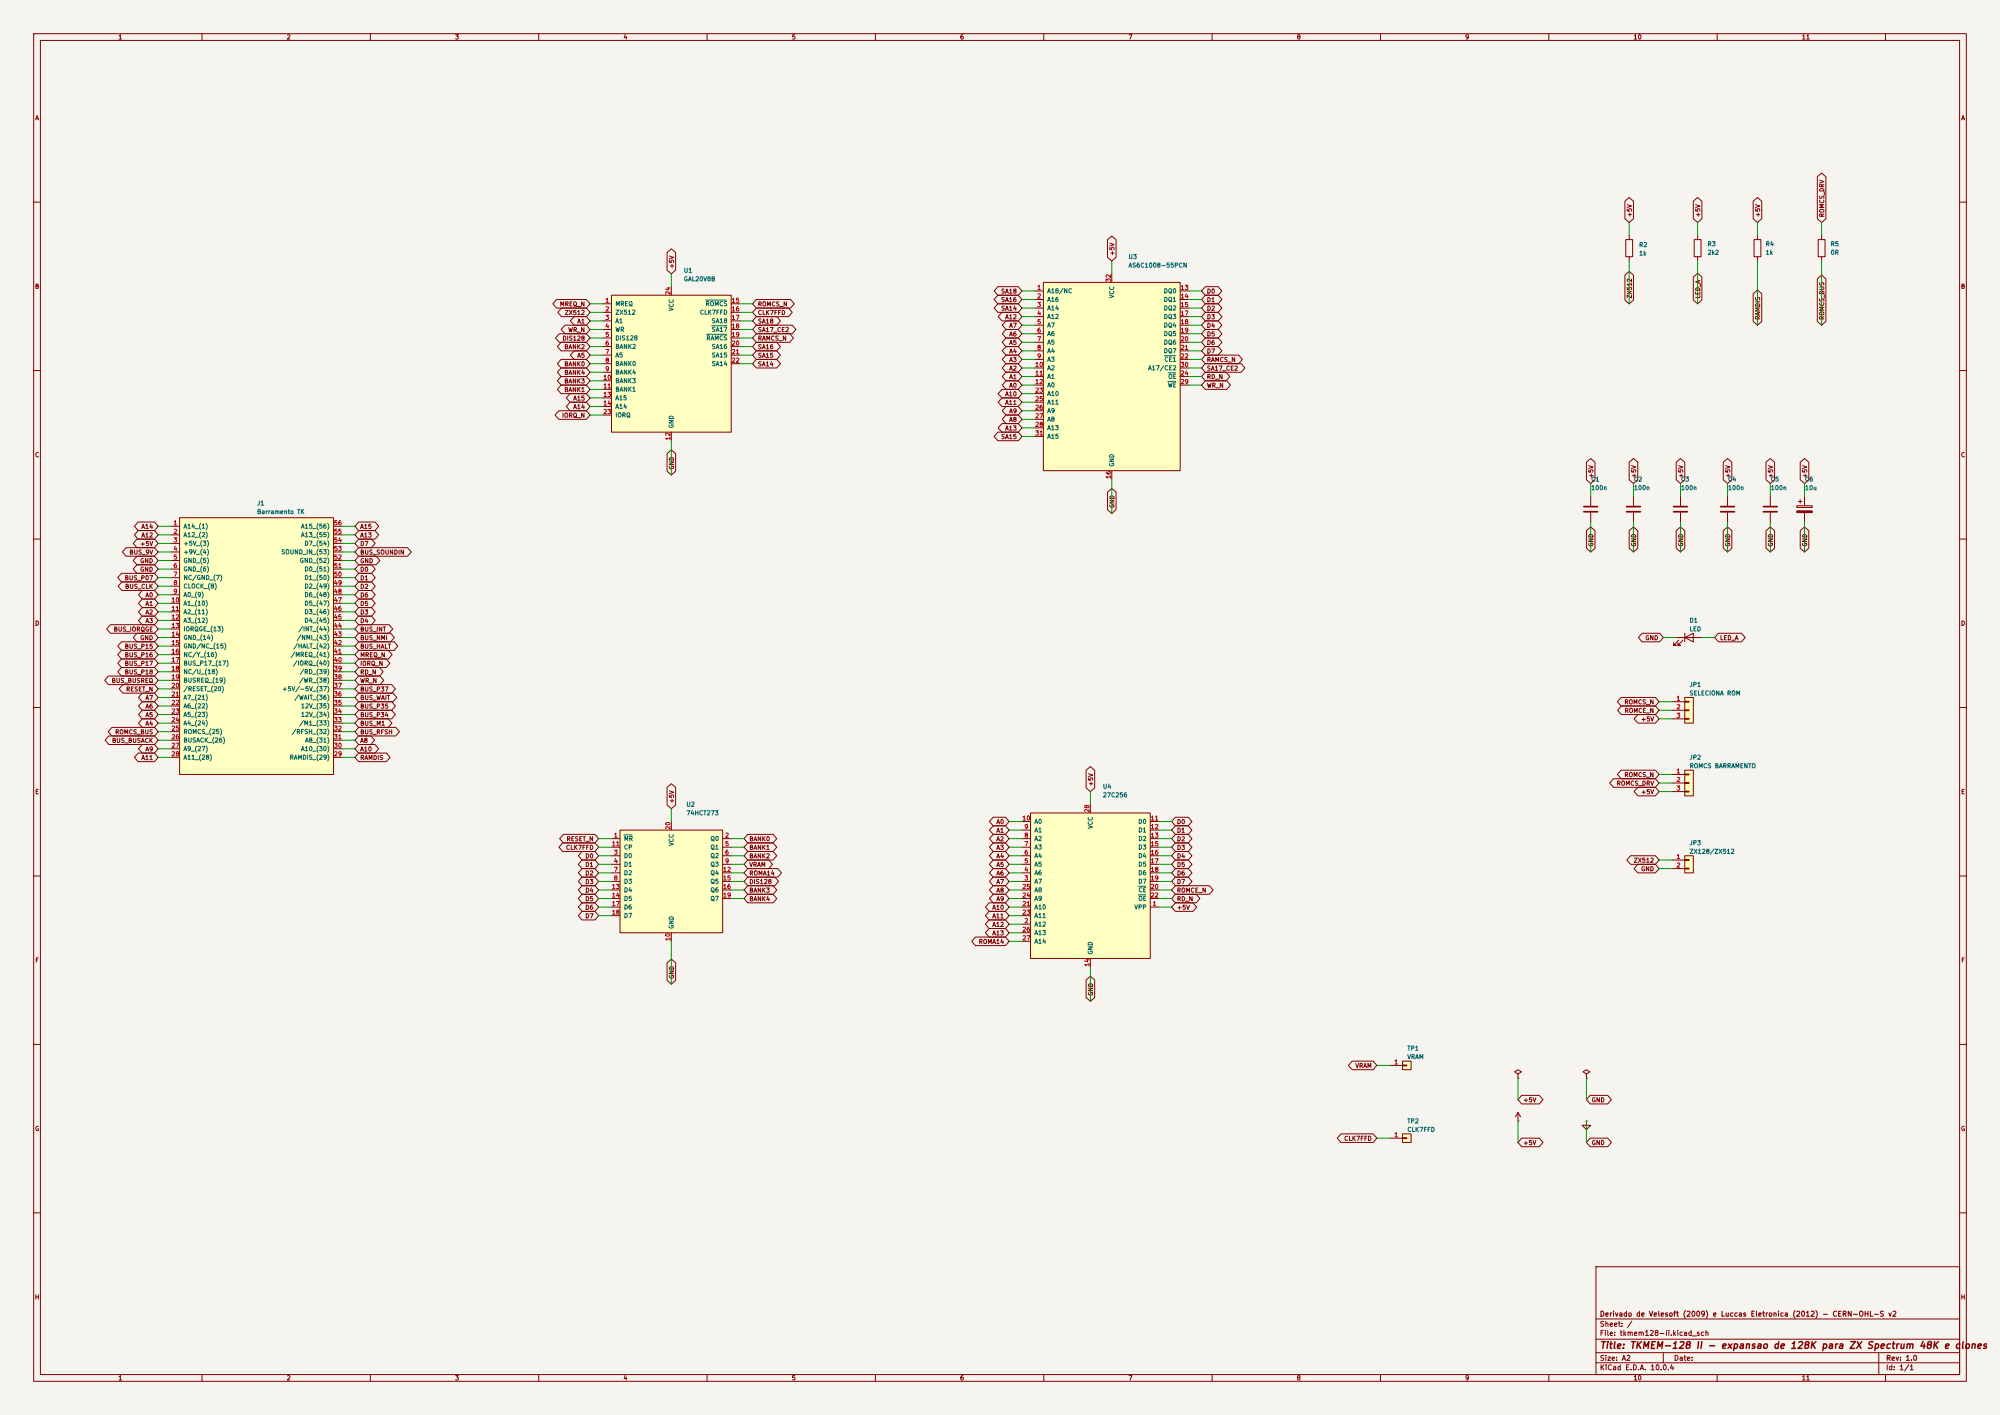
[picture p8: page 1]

Derivado de Velesoft (2009) e Luccas Eletronica (2012) - CERN-OHL-S v2
Sheet: /
File: tkmem128-ii.kicad_sch
Title: TKMEM-128 II - expansao de 128K para ZX Spectrum 48K e clones

Size: A2 | Rev: 1.0
KiCad E.D.A. 10.0.4 | Id: 1/1

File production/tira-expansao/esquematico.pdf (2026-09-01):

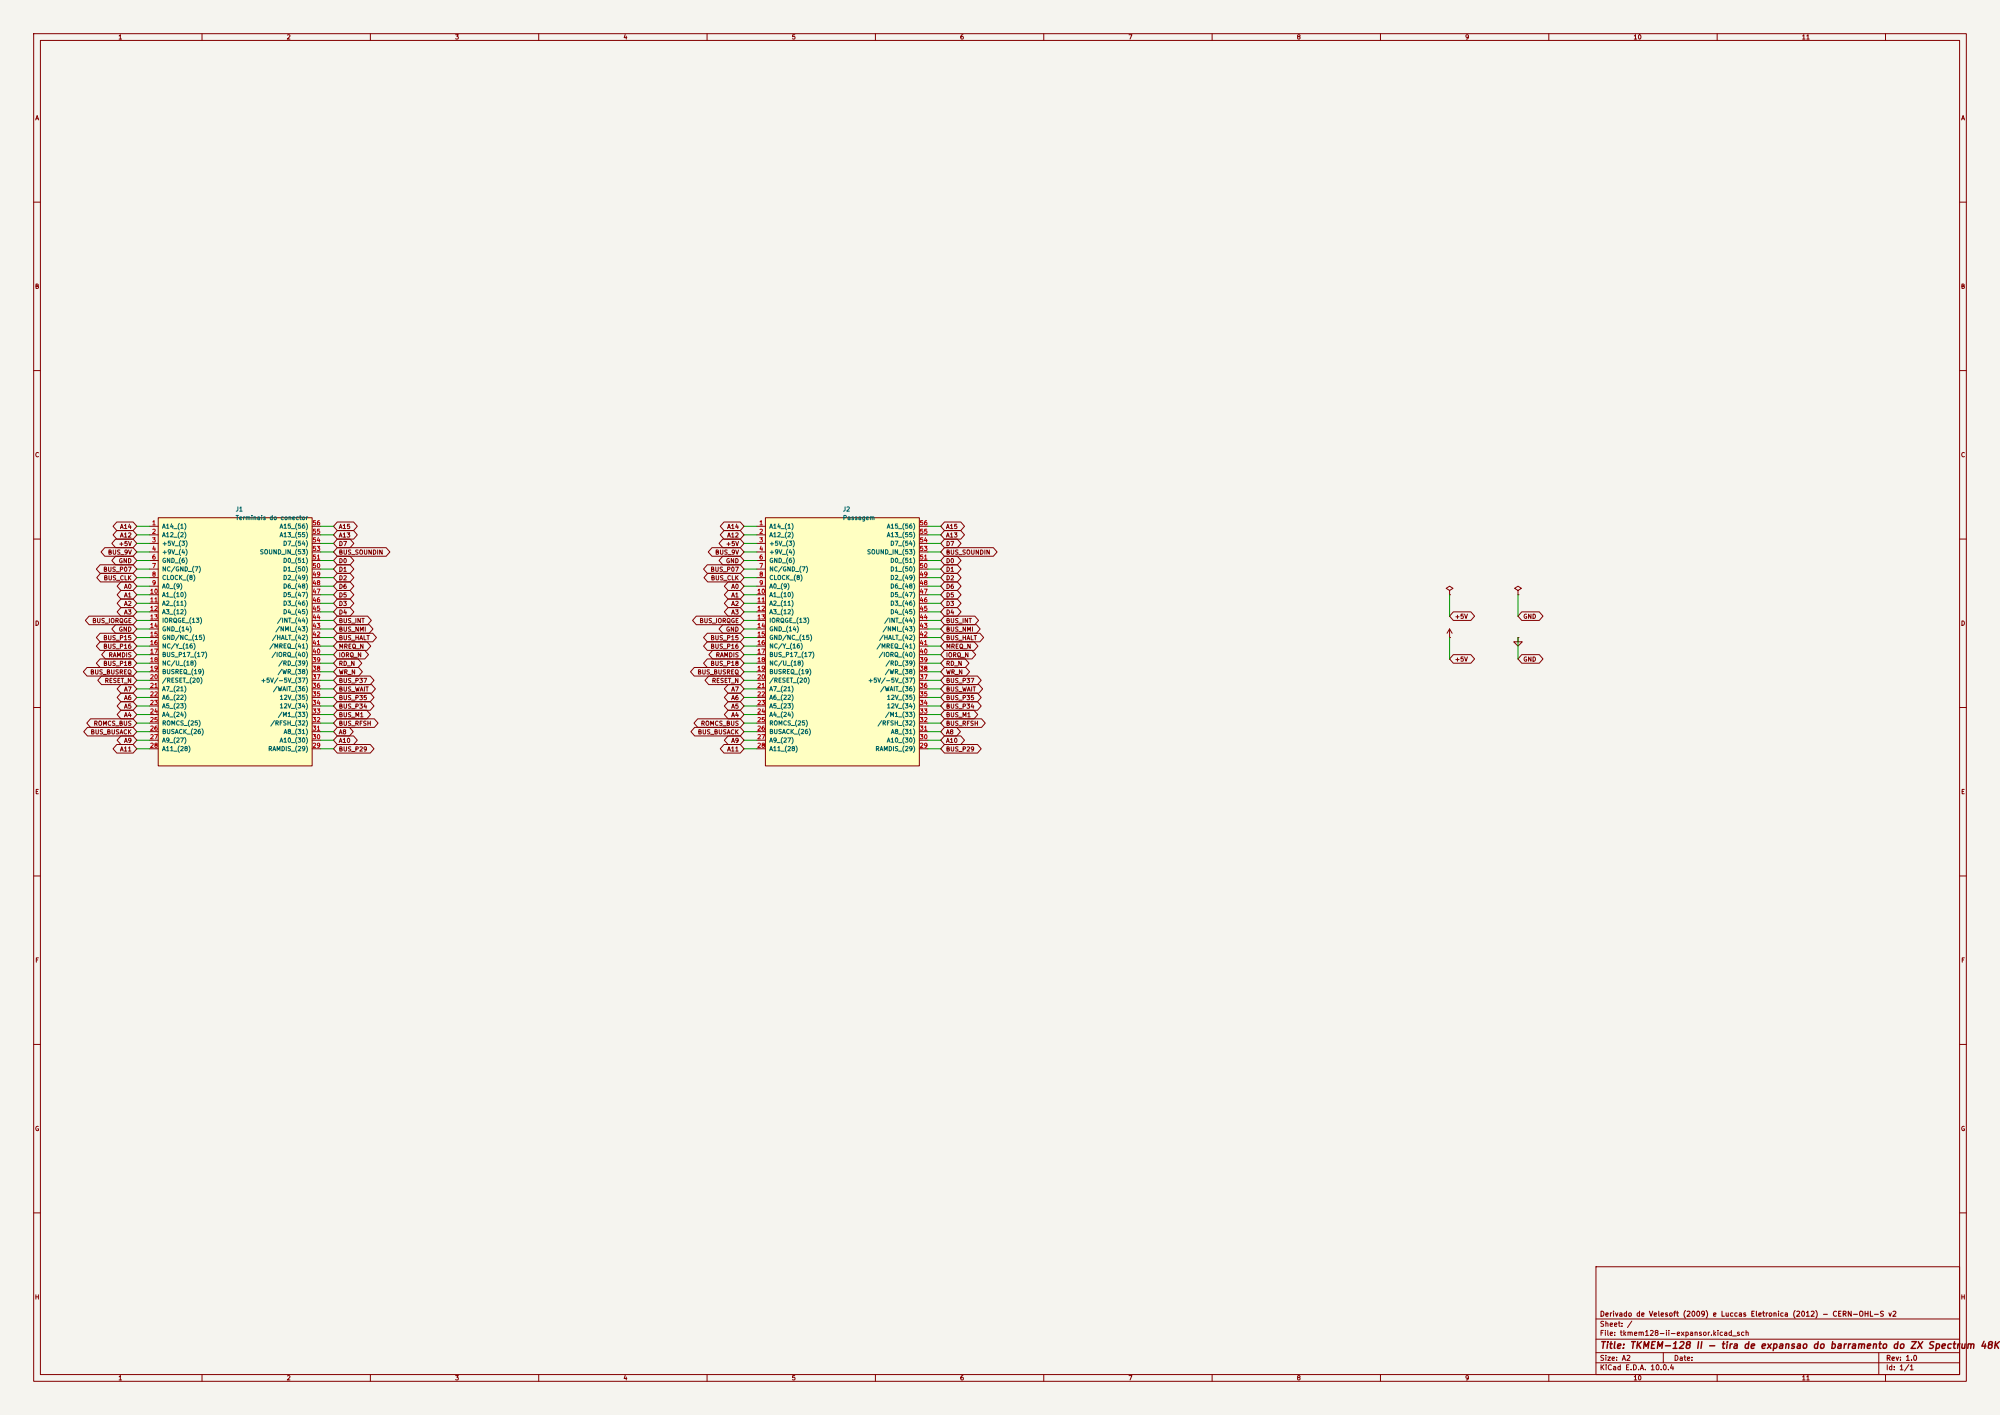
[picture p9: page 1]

Derivado de Velesoft (2009) e Luccas Eletronica (2012) - CERN-OHL-S v2
Sheet: /
File: tkmem128-ii-expansor.kicad_sch
Title: TKMEM-128 II - tira de expansao do barramento do ZX Spectrum 48K e clones

Size: A2 | Rev: 1.0
KiCad E.D.A. 10.0.4 | Id: 1/1

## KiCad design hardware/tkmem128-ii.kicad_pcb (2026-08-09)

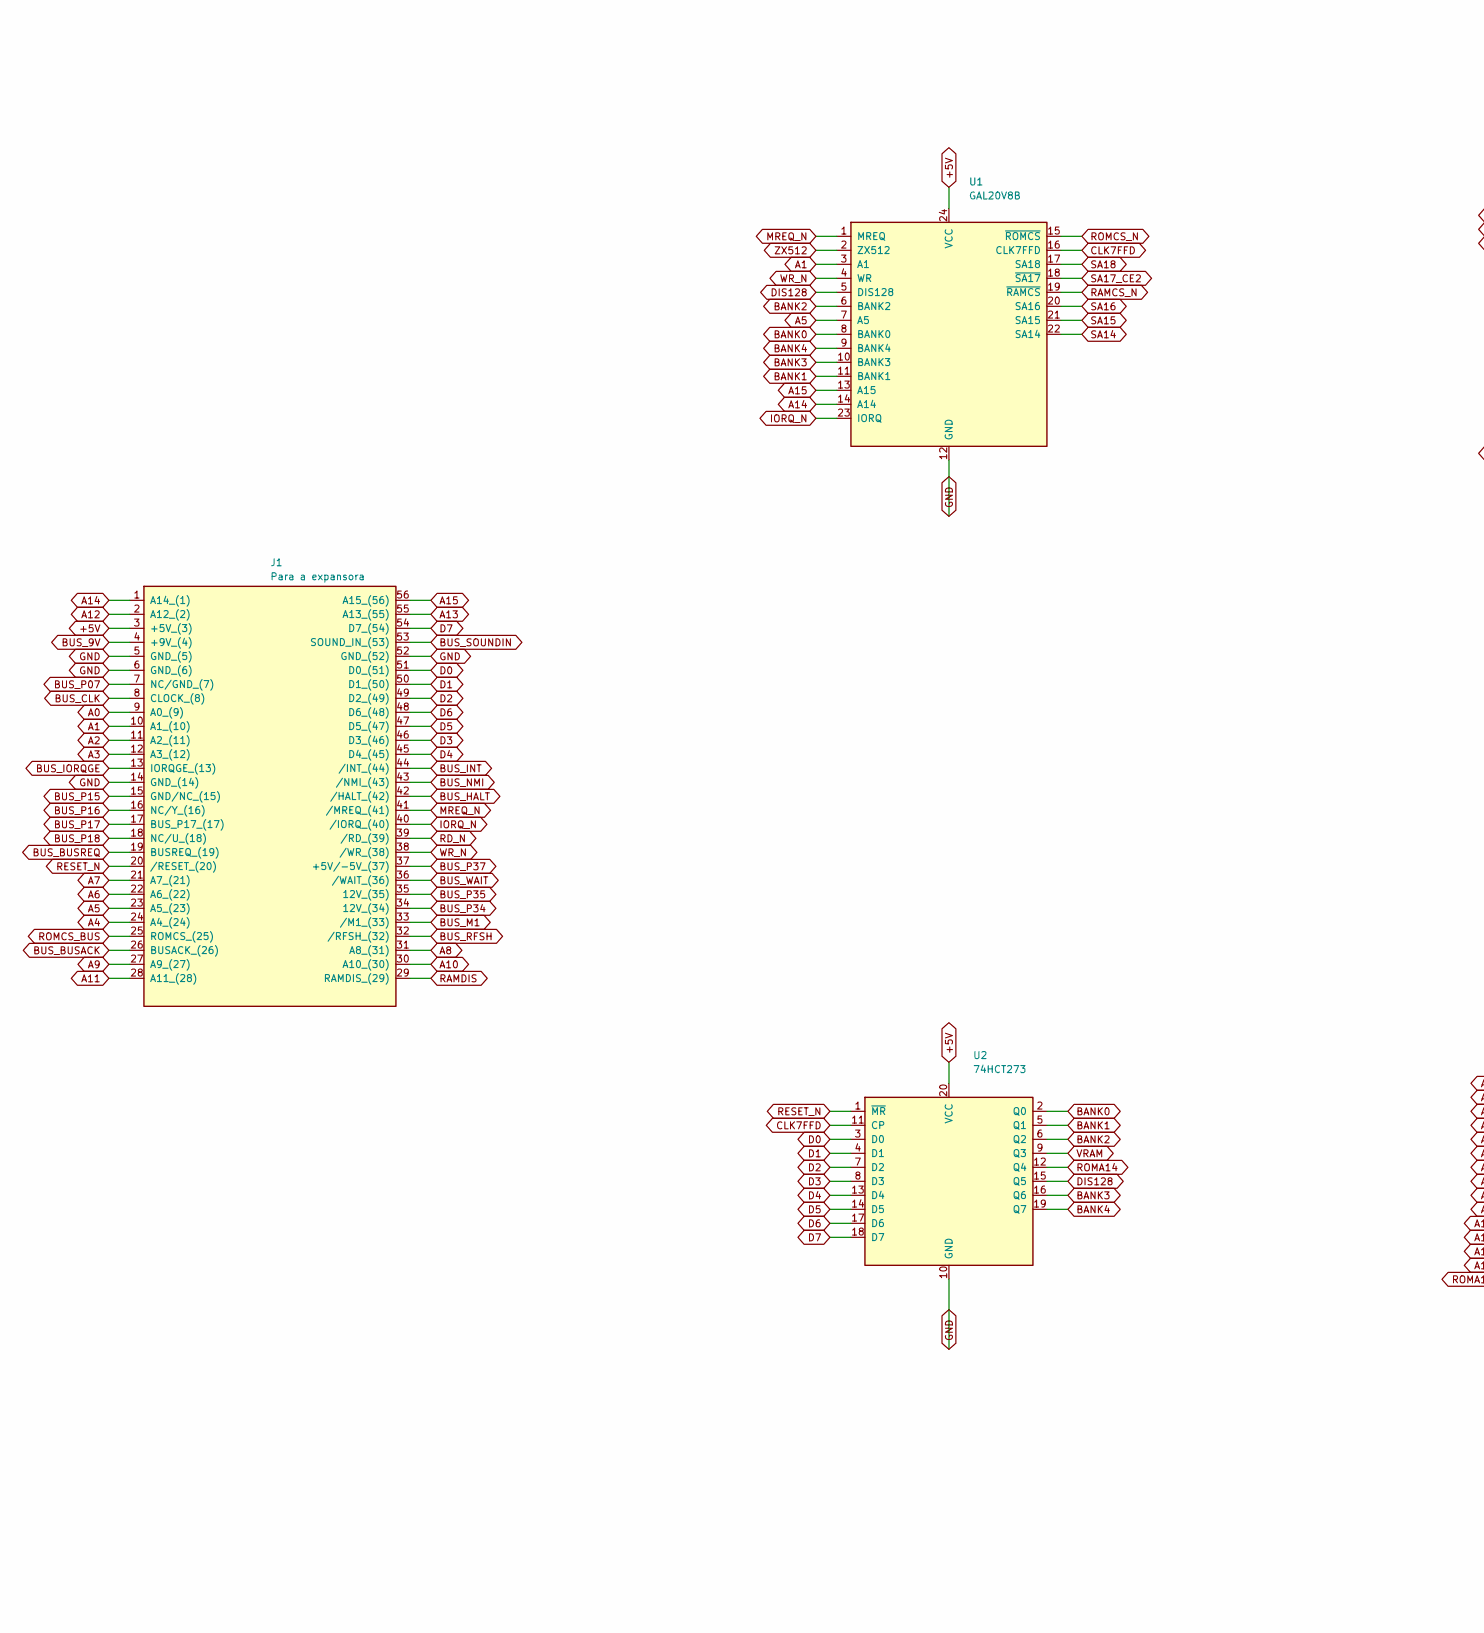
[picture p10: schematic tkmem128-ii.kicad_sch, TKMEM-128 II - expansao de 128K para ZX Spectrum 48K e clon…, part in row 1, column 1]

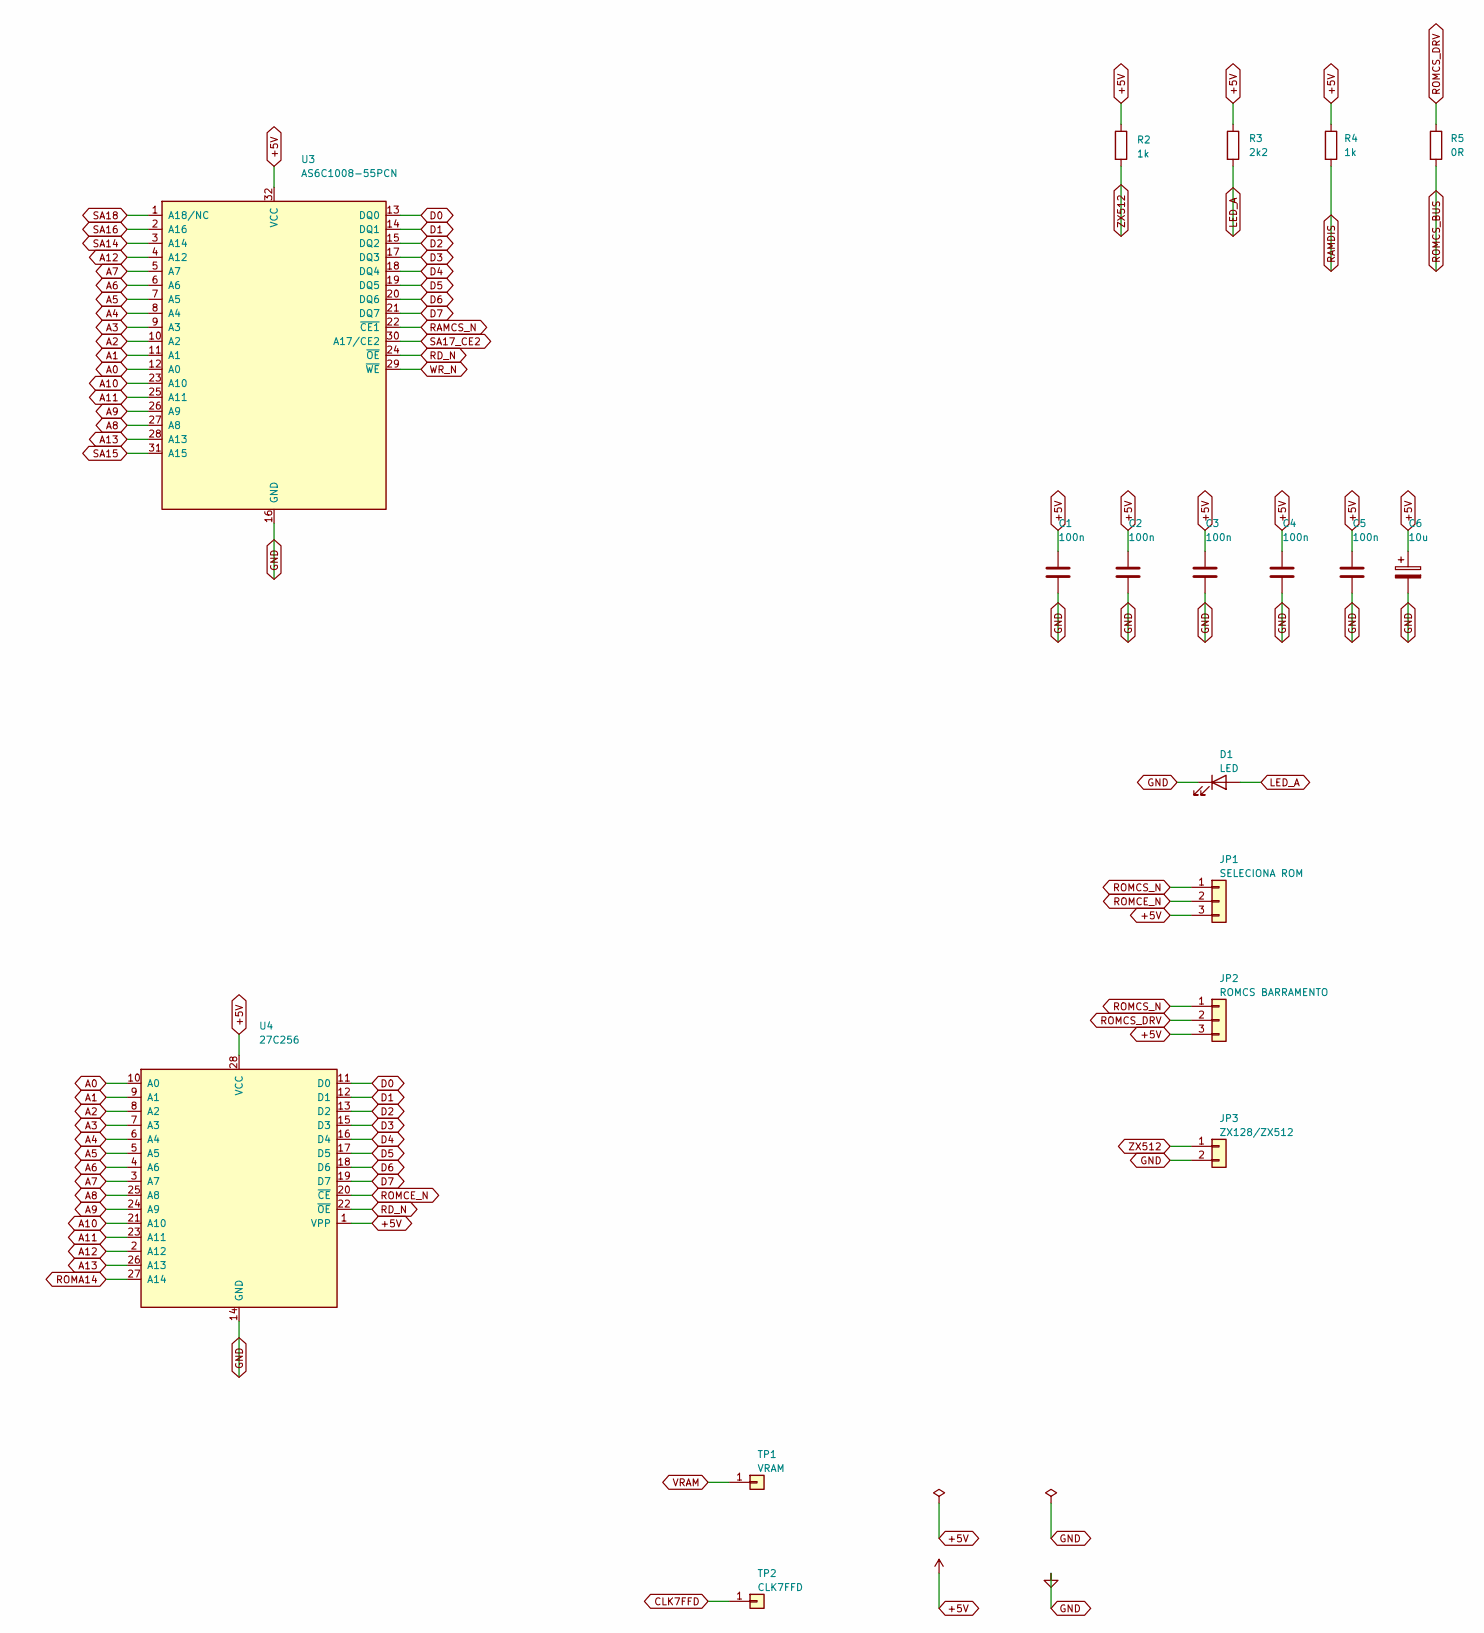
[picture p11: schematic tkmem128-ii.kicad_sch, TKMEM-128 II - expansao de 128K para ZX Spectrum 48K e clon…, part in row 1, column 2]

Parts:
C1, C2, C3, C4, C5: 100n; C_Disc_D5.0mm_W2.5mm_P5.00mm
C6: 10u; CP_Radial_D5.0mm_P2.00mm
D1: LED; LED_D3.0mm
J1: Para a expansora; ZX_TK_Bus_Header_2x28
JP1: SELECIONA ROM; PinHeader_1x03_P2.54mm_Vertical
JP2: ROMCS BARRAMENTO; PinHeader_1x03_P2.54mm_Vertical
JP3: ZX128/ZX512; PinHeader_1x02_P2.54mm_Vertical
R2, R4: 1k; R_Axial_DIN0207_L6.3mm_D2.5mm_P2.54mm_Vertical
R3: 2k2; R_Axial_DIN0207_L6.3mm_D2.5mm_P2.54mm_Vertical
R5: 0R; R_Axial_DIN0207_L6.3mm_D2.5mm_P2.54mm_Vertical
TP1: VRAM; TestPoint_THTPad_D1.5mm_Drill0.7mm
TP2: CLK7FFD; TestPoint_THTPad_D1.5mm_Drill0.7mm
U1: GAL20V8B; DIP-24_W7.62mm_Socket_LongPads
U2: 74HCT273; DIP-20_W7.62mm_Socket_LongPads
U3: AS6C1008-55PCN; DIP-32_W15.24mm_Socket_LongPads
U4: 27C256; DIP-28_W15.24mm_Socket_LongPads

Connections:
+5V: C1.1, C2.1, C3.1, C4.1, C5.1, C6.1, J1.3 (+5V_(3)), JP1.3, JP2.3, R2.1, R3.1, R4.1, U1.24 (VCC), U2.20 (VCC), U3.32 (VCC), U4.1 (VPP), U4.28 (VCC)
A0: J1.9 (A0_(9)), U3.12 (A0), U4.10 (A0)
A1: J1.10 (A1_(10)), U1.3 (A1), U3.11 (A1), U4.9 (A1)
A2: J1.11 (A2_(11)), U3.10 (A2), U4.8 (A2)
A3: J1.12 (A3_(12)), U3.9 (A3), U4.7 (A3)
A4: J1.24 (A4_(24)), U3.8 (A4), U4.6 (A4)
A5: J1.23 (A5_(23)), U1.7 (A5), U3.7 (A5), U4.5 (A5)
A6: J1.22 (A6_(22)), U3.6 (A6), U4.4 (A6)
A7: J1.21 (A7_(21)), U3.5 (A7), U4.3 (A7)
A8: J1.31 (A8_(31)), U3.27 (A8), U4.25 (A8)
A9: J1.27 (A9_(27)), U3.26 (A9), U4.24 (A9)
A10: J1.30 (A10_(30)), U3.23 (A10), U4.21 (A10)
A11: J1.28 (A11_(28)), U3.25 (A11), U4.23 (A11)
A12: J1.2 (A12_(2)), U3.4 (A12), U4.2 (A12)
A13: J1.55 (A13_(55)), U3.28 (A13), U4.26 (A13)
A14: J1.1 (A14_(1)), U1.14 (A14)
A15: J1.56 (A15_(56)), U1.13 (A15)
BANK0: U1.8 (BANK0), U2.2 (Q0)
BANK1: U1.11 (BANK1), U2.5 (Q1)
BANK2: U1.6 (BANK2), U2.6 (Q2)
BANK3: U1.10 (BANK3), U2.16 (Q6)
BANK4: U1.9 (BANK4), U2.19 (Q7)
BUS_9V: J1.4 (+9V_(4))
BUS_BUSACK: J1.26 (BUSACK_(26))
BUS_BUSREQ: J1.19 (BUSREQ_(19))
BUS_CLK: J1.8 (CLOCK_(8))
BUS_HALT: J1.42 (/HALT_(42))
BUS_INT: J1.44 (/INT_(44))
BUS_IORQGE: J1.13 (IORQGE_(13))
BUS_M1: J1.33 (/M1_(33))
BUS_NMI: J1.43 (/NMI_(43))
BUS_P07: J1.7 (NC/GND_(7))
BUS_P15: J1.15 (GND/NC_(15))
BUS_P16: J1.16 (NC/Y_(16))
BUS_P17: J1.17 (BUS_P17_(17))
BUS_P18: J1.18 (NC/U_(18))
BUS_P34: J1.34 (12V_(34))
BUS_P35: J1.35 (12V_(35))
BUS_P37: J1.37 (+5V/-5V_(37))
BUS_RFSH: J1.32 (/RFSH_(32))
BUS_SOUNDIN: J1.53 (SOUND_IN_(53))
BUS_WAIT: J1.36 (/WAIT_(36))
CLK7FFD: TP2.1, U1.16 (CLK7FFD), U2.11 (CP)
D0: J1.51 (D0_(51)), U2.3 (D0), U3.13 (DQ0), U4.11 (D0)
D1: J1.50 (D1_(50)), U2.4 (D1), U3.14 (DQ1), U4.12 (D1)
D2: J1.49 (D2_(49)), U2.7 (D2), U3.15 (DQ2), U4.13 (D2)
D3: J1.46 (D3_(46)), U2.8 (D3), U3.17 (DQ3), U4.15 (D3)
D4: J1.45 (D4_(45)), U2.13 (D4), U3.18 (DQ4), U4.16 (D4)
D5: J1.47 (D5_(47)), U2.14 (D5), U3.19 (DQ5), U4.17 (D5)
D6: J1.48 (D6_(48)), U2.17 (D6), U3.20 (DQ6), U4.18 (D6)
D7: J1.54 (D7_(54)), U2.18 (D7), U3.21 (DQ7), U4.19 (D7)
DIS128: U1.5 (DIS128), U2.15 (Q5)
GND: C1.2, C2.2, C3.2, C4.2, C5.2, C6.2, D1.1 (K), J1.5 (GND_(5)), J1.6 (GND_(6)), J1.14 (GND_(14)), J1.52 (GND_(52)), JP3.2, U1.12 (GND), U2.10 (GND), U3.16 (GND), U4.14 (GND)
IORQ_N: J1.40 (/IORQ_(40)), U1.23 (IORQ)
LED_A: D1.2 (A), R3.2
MREQ_N: J1.41 (/MREQ_(41)), U1.1 (MREQ)
RAMCS_N: U1.19 (~RAMCS), U3.22 (~CE1)
RAMDIS: J1.29 (RAMDIS_(29)), R4.2
RD_N: J1.39 (/RD_(39)), U3.24 (~OE), U4.22 (~OE)
RESET_N: J1.20 (/RESET_(20)), U2.1 (~MR)
ROMA14: U2.12 (Q4), U4.27 (A14)
ROMCE_N: JP1.2, U4.20 (~CE)
ROMCS_BUS: J1.25 (ROMCS_(25)), R5.2
ROMCS_DRV: JP2.2, R5.1
ROMCS_N: JP1.1, JP2.1, U1.15 (~ROMCS)
SA14: U1.22 (SA14), U3.3 (A14)
SA15: U1.21 (SA15), U3.31 (A15)
SA16: U1.20 (SA16), U3.2 (A16)
SA17_CE2: U1.18 (~SA17), U3.30 (A17/CE2)
SA18: U1.17 (SA18), U3.1 (A18/NC)
VRAM: TP1.1, U2.9 (Q3)
WR_N: J1.38 (/WR_(38)), U1.4 (WR), U3.29 (~WE)
ZX512: JP3.1, R2.2, U1.2 (ZX512)

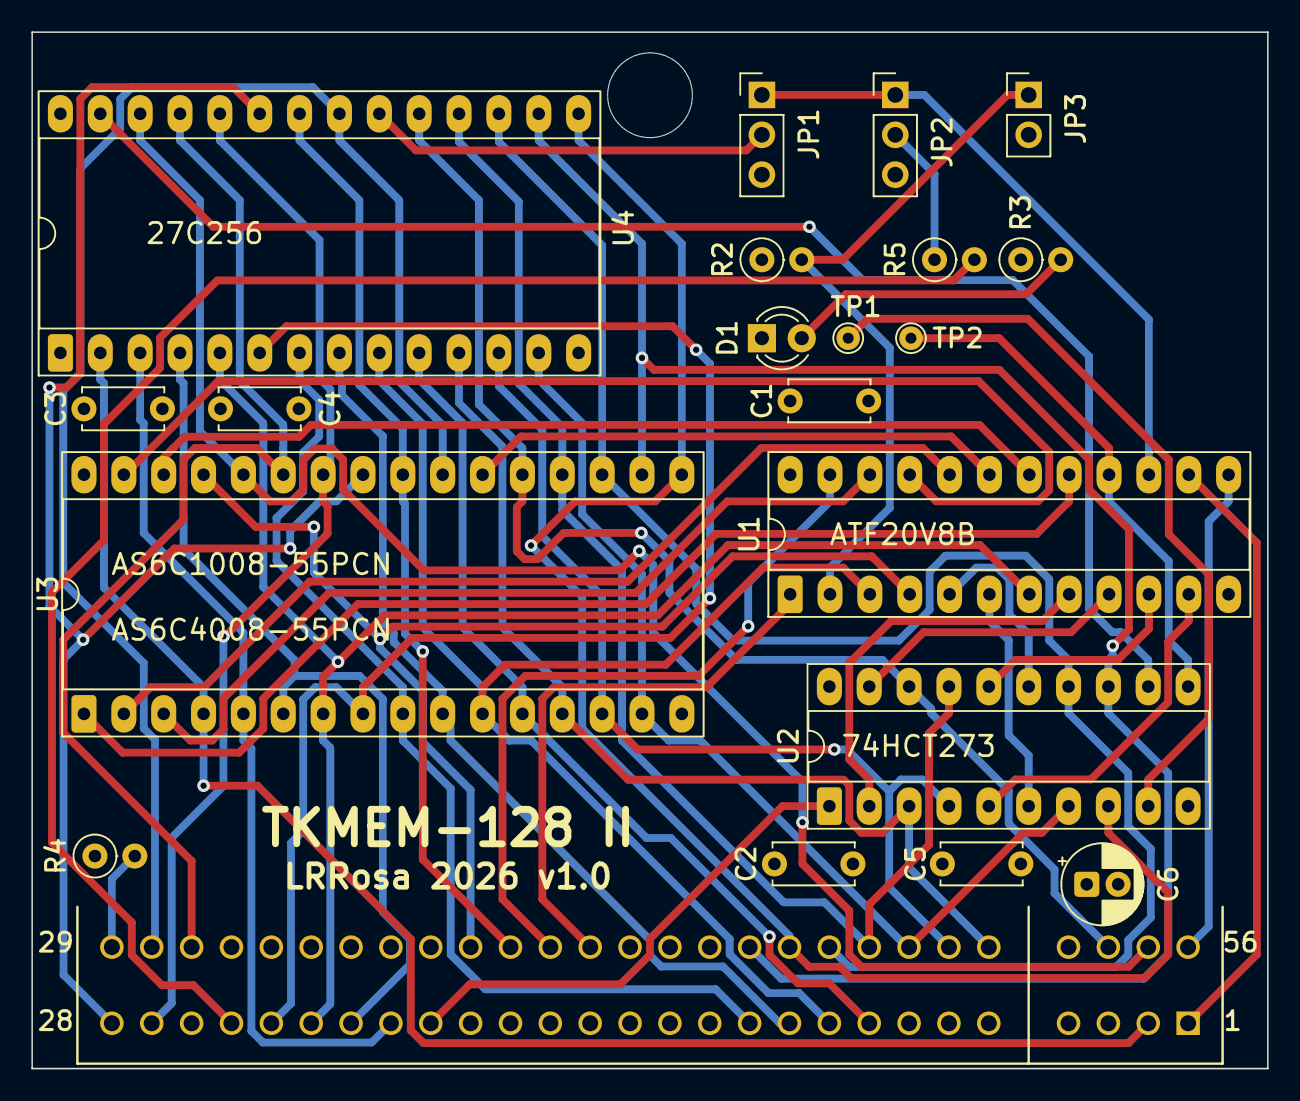
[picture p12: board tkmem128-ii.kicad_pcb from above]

Board: 4 copper layers, 78.7 x 66.0 mm, 22 parts (1 on the bottom side), 53 nets.

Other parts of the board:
H1: MountingHole_5.4mm

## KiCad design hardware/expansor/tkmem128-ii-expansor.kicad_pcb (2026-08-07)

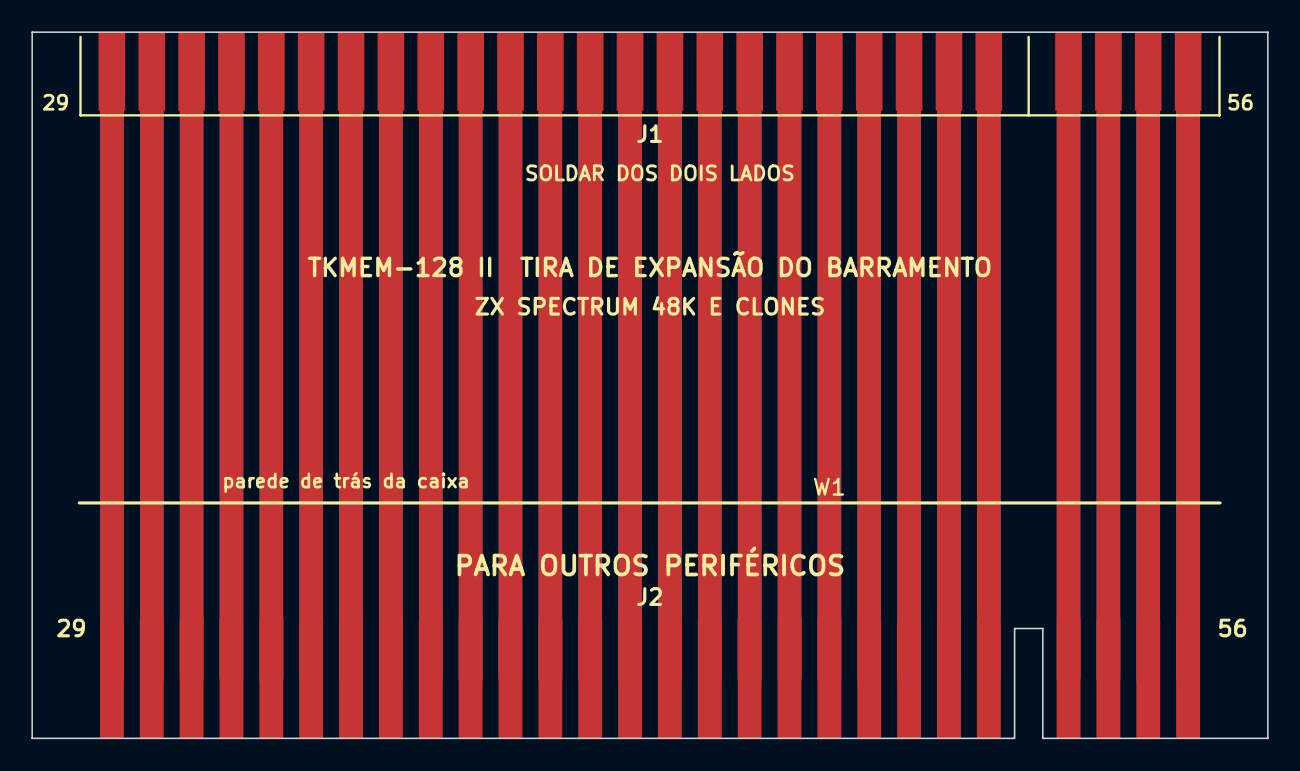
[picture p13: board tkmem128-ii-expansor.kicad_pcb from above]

Board: 2 copper layers, 78.7 x 45.0 mm, 3 parts (0 on the bottom side), 53 nets.

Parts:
J1: Terminais do conector; ZX_TK_Bus_SolderPads_56
J2: Passagem; ZX_TK_Bus_Fingers_56
W1: WireLink_GND_P20.32mm

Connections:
+5V: J1.3, J2.3
A0: J1.9, J2.9
A1: J1.10, J2.10
A2: J1.11, J2.11
A3: J1.12, J2.12
A4: J1.24, J2.24
A5: J1.23, J2.23
A6: J1.22, J2.22
A7: J1.21, J2.21
A8: J1.31, J2.31
A9: J1.27, J2.27
A10: J1.30, J2.30
A11: J1.28, J2.28
A12: J1.2, J2.2
A13: J1.55, J2.55
A14: J1.1, J2.1
A15: J1.56, J2.56
BUS_9V: J1.4, J2.4
BUS_BUSACK: J1.26, J2.26
BUS_BUSREQ: J1.19, J2.19
BUS_CLK: J1.8, J2.8
BUS_HALT: J1.42, J2.42
BUS_INT: J1.44, J2.44
BUS_IORQGE: J1.13, J2.13
BUS_M1: J1.33, J2.33
BUS_NMI: J1.43, J2.43
BUS_P07: J1.7, J2.7
BUS_P15: J1.15, J2.15
BUS_P16: J1.16, J2.16
BUS_P18: J1.18, J2.18
BUS_P29: J1.29, J2.29
BUS_P34: J1.34, J2.34
BUS_P35: J1.35, J2.35
BUS_P37: J1.37, J2.37
BUS_RFSH: J1.32, J2.32
BUS_SOUNDIN: J1.53, J2.53
BUS_WAIT: J1.36, J2.36
D0: J1.51, J2.51
D1: J1.50, J2.50
D2: J1.49, J2.49
D3: J1.46, J2.46
D4: J1.45, J2.45
D5: J1.47, J2.47
D6: J1.48, J2.48
D7: J1.54, J2.54
GND: J1.6, J1.14, J2.6, J2.14, W1.1
IORQ_N: J1.40, J2.40
MREQ_N: J1.41, J2.41
RAMDIS: J1.17, J2.17
RD_N: J1.39, J2.39
RESET_N: J1.20, J2.20
ROMCS_BUS: J1.25, J2.25
WR_N: J1.38, J2.38

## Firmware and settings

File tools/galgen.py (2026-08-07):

# -*- coding: utf-8 -*-
"""Monta o mapa de fusiveis do GAL20V8 a partir das equacoes da TKMEM-128
e confere contra um .jed de referencia.

A ideia: o mapa de colunas da matriz AND e DERIVADO das proprias equacoes
conhecidas (nao chutado), e depois usado para reencodar tudo. Se o resultado
sair bit a bit igual ao .jed de referencia, esta provado que:
  (a) o mapa de colunas deduzido esta certo, e
  (b) o .jed distribuido implementa exatamente as equacoes documentadas.
"""
import io, re, sys

QF = 2706
ROWS, COLS = 64, 40

# OLMC: bloco de 8 linhas -> pino de saida (linha 0 de cada bloco = OE)
BLOCK_PIN = {0: 22, 1: 21, 2: 20, 3: 19, 4: 18, 5: 17, 6: 16, 7: 15}

# equacoes: pino -> (saida_ativa_baixa, [termo, ...])
# termo = [(pino_de_entrada, True se literal verdadeiro), ...]
MREQ, ZX512, A1, WR, DIS128, BANK2, A5, BANK0 = 1, 2, 3, 4, 5, 6, 7, 8
BANK4, BANK3, BANK1, A15, A14, IORQ = 9, 10, 11, 13, 14, 23

EQ = {
    22: (False, [[(A14, True), (A15, True), (BANK0, True)]]),                # SA14
    21: (False, [[(A14, True), (A15, True), (BANK1, True)],
                 [(A14, False), (A15, True)]]),                              # SA15
    20: (False, [[(A14, True), (A15, True), (BANK2, True)]]),                # SA16
    19: (True,  [[(MREQ, False), (A15, True)]]),                             # /RAMCS
    18: (True,  [[(A14, True), (A15, True), (BANK3, True),
                  (ZX512, False)]]),                                         # /SA17
    17: (False, [[(A14, True), (A15, True), (BANK4, True),
                  (ZX512, False)]]),                                         # SA18
    16: (False, [[(IORQ, False), (WR, False), (A15, False), (A5, True),
                  (A1, False)],
                 [(DIS128, True)]]),                                         # CLK7FFD
    15: (True,  [[(MREQ, False), (A14, False), (A15, False)]]),              # /ROMCS
}


def read_jed(path):
    """Devolve a lista de 2706 fusiveis (0/1) de um arquivo JEDEC."""
    txt = io.open(path, encoding="latin-1").read()
    fuses = [0] * QF
    for m in re.finditer(r"L0*(\d+)\s+([01\s]+?)\*", txt):
        addr = int(m.group(1))
        bits = re.sub(r"\s", "", m.group(2))
        for i, c in enumerate(bits):
            fuses[addr + i] = int(c)
    return fuses


def and_rows(fuses):
    return [fuses[r * COLS:(r + 1) * COLS] for r in range(ROWS)]


def derive_colmap(rows):
    """Deduz coluna -> (pino, literal_verdadeiro) a partir das equacoes."""
    # candidatos: para cada literal, o conjunto de colunas possiveis
    cand = {}
    for block, pin in BLOCK_PIN.items():
        _, terms = EQ[pin]
        for ti, term in enumerate(terms):
            row = rows[block * 8 + 1 + ti]
            zeros = set(i for i, b in enumerate(row) if b == 0)
            if len(zeros) != len(term):
                raise SystemExit(
                    "bloco %d termo %d: %d zeros para %d literais"
                    % (block, ti, len(zeros), len(term)))
            for lit in term:
                cand.setdefault(lit, []).append(zeros)

    poss = {lit: set.intersection(*sets) for lit, sets in cand.items()}
    colmap = {}

    # propagacao de restricoes: (1) coluna ja usada sai dos candidatos;
    # (2) literal verdadeiro e barrado do mesmo pino ocupam colunas vizinhas
    #     do mesmo par (2k, 2k+1).
    for _ in range(len(poss) + 2):
        changed = False
        for lit in list(poss):
            if lit in colmap:
                continue
            opts = poss[lit] - set(colmap.values())
            pin, true_lit = lit
            other = colmap.get((pin, not true_lit))
            if other is not None:
                opts = opts & {other ^ 1}
            if len(opts) == 1:
                colmap[lit] = opts.pop()
                changed = True
            else:
                poss[lit] = opts
        if not changed:
            break

    # Literais que so aparecem juntos num mesmo produto ficam intercambiaveis:
    # o conjunto de colunas e o mesmo, e AND e comutativo, entao a escolha
    # dentro do grupo nao muda um unico fusivel. Fixa numa ordem estavel.
    faltando = sorted(l for l in poss if l not in colmap)
    if faltando:
        livres = sorted(set().union(*[poss[l] for l in faltando])
                        - set(colmap.values()))
        if len(livres) != len(faltando):
            raise SystemExit("literais ambiguos sem solucao: %s" % faltando)
        for lit, col in zip(faltando, livres):
            colmap[lit] = col
        print("nota: %d literais aparecem apenas num mesmo produto e sao "
              "intercambiaveis;" % len(faltando))
        print("      a atribuicao dentro do grupo nao altera o mapa de "
              "fusiveis.")
    return colmap


def build(colmap):
    """Reconstroi os 2706 fusiveis a partir das equacoes."""
    fuses = [0] * QF
    for block, pin in BLOCK_PIN.items():
        base = block * 8 * COLS
        # linha 0 = habilitacao de saida: sempre ligada -> todos os fusiveis 1
        for c in range(COLS):
            fuses[base + c] = 1
        _, terms = EQ[pin]
        for ti, term in enumerate(terms):
            off = base + (1 + ti) * COLS
            cols = set(colmap[lit] for lit in term)
            for c in range(COLS):
                fuses[off + c] = 0 if c in cols else 1
        # linhas restantes ficam em 0 (termo sempre falso)

    # ---- fusiveis de configuracao ----------------------------------------
    # XOR (L2560): polaridade da saida. 1 = ativa alta, 0 = ativa baixa.
    for block, pin in BLOCK_PIN.items():
        ativa_baixa, _ = EQ[pin]
        fuses[2560 + block] = 0 if ativa_baixa else 1

    # assinatura do usuario (L2568..2631): em branco
    for i in range(2568, 2632):
        fuses[i] = 0

    # AC1 (L2632): 1 em todos = saidas combinatorias tristate (modo complex)
    for block in range(8):
        fuses[2632 + block] = 1

    # PTD (L2640): habilita as linhas usadas de cada OLMC.
    # linha 0 = habilitacao de saida, linhas 1..n = os produtos.
    for block, pin in BLOCK_PIN.items():
        _, terms = EQ[pin]
        for row in range(8):
            fuses[2640 + block * 8 + row] = 1 if row <= len(terms) else 0

    # SYN e AC0 (L2704): 1,1 = modo complex
    fuses[2704] = 1
    fuses[2705] = 1
    return fuses


def checksum(fuses):
    """Checksum JEDEC: soma dos bytes little-endian dos fusiveis, 16 bits."""
    total = 0
    for i in range(0, len(fuses), 8):
        byte = 0
        for b in range(8):
            if i + b < len(fuses) and fuses[i + b]:
                byte |= 1 << b
        total += byte
    return total & 0xFFFF


PINNAMES = ("MREQ:1 ZX512:2 A1:3 WR:4 DIS128:5 BANK2:6 A5:7 BANK0:8 "
            "BANK4:9 BANK3:10 BANK1:11 GND:12 A15:13 A14:14 ROMCS:15 "
            "CLK7FFD:16 SA18:17 SA17:18 RAMCS:19 SA16:20 SA15:21 SA14:22 "
            "IORQ:23 VCC:24")
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

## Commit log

2026-07-26 TKMEM-128 KiCad: redesenho completo em duas placas
    Expansao de 128K/512K paginados (padrao ZX Spectrum 128) para TK90X/TK95,
    redesenhada em KiCad 10 a partir de dois projetos anteriores:
    - "external 128kb upgrade" (zx48_to_128-EASY_3), Velesoft, 2009 - circuito
    base: equacoes do GAL20V8, latch da porta 0x7FFD e paginacao da SRAM
    - TKMEM-128, Luccas Eletronica, 2012 - adaptacao ao TK: EPROM da ROM 128,
    jumpers de selecao, auto-desativacao da RAM interna pelo pino 17
    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
    [bom.csv, posicoes.csv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]
2026-07-27 Correcoes de revisao: pino 17, expansora dimensionada, .jed verificado
    Correcoes apontadas na revisao:
    - "Edu Luccas" -> "Eduardo Luccas" em toda a documentacao.
    - O pino 17 do barramento NAO e livre no ZX Spectrum: os pinos 16, 17 e 18
    la sao Y, V e U do video componente. Corrigido na definicao do barramento
    e na documentacao, com aviso explicito de nunca fechar JP4 em Spectrum.
    Isso tambem sustenta a analise de por que a placa original avisava que o
    jumper na posicao errada danificava o micro: o pino util no TK e sinal de
    video no Spectrum, entao o jumper escolhia entre dois pinos diferentes, e
    os dois barramentos divergem justamente em pinos de alimentacao (34, 35,
    37).
    -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
    [bom.csv, posicoes.csv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]
2026-07-27 Esquematicos e silk rearranjados; pendencia do plano do soquete de borda
    Esquematico das duas placas redesenhado a mao (havia simbolos saindo da
    folha e sinais misturados) e serigrafia reorganizada. Conferido: ERC 0,
    DRC 0, e a netlist exportada bate no a no com a intencao de projeto nas
    duas placas (74 e 53 nets, zero divergencia).
    Os geradores em tools/ passam a ser ferramenta de bootstrap: gen_schematic.py
    e gen_pcb.py sobrescreveriam o ajuste manual. A fonte corrente e o conteudo
    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
    [tkmem128-B_Cu.gbr, tkmem128-B_Mask.gbr, tkmem128-B_Silkscreen.gbr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]
2026-07-27 Soquete de borda: cotas do datasheet e problema de orientacao
    Datasheet identificado: TE/AMP 5645235 "Standard Edge II", passo 2,54 mm.
    Footprint ZX_TK_Bus_Socket_56 corrigido com as cotas reais:
    fileiras de terminais 5,08 -> 4,85 mm [.191]
    furo 1,00 -> 1,02 mm [.040]
    ilha 1,80 -> 1,75 mm
    O corte do desenho tambem mostra que o conector e de ENTRADA VERTICAL: o
    cartao entra perpendicular a placa em que ele esta soldado. Isso e
    incompativel com a expansora desenhada deitada, coplanar com o cartao do TK.
    A geometria correta - e que bate com as fotos das placas reais, onde a fenda
    fica alinhada com o plano dos dedos de passagem - poe o soquete numa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
2026-07-27 Arquitetura corrigida: conector na placa principal, tira soldada nos terminais
    As fotos do periferico de audio (mesma construcao da TKMEM) mostraram como o
    conjunto realmente se monta, e o datasheet do TE 5645235 confirmou o porque:
    - o conector de borda e de ENTRADA VERTICAL, ou seja, o cartao entra
    perpendicular a placa que o segura. Por isso ele vai soldado direto na
    placa PRINCIPAL, que fica em pe: a fenda cai no plano horizontal e recebe
    o cartao do TK;
    - os terminais atravessam a placa principal e sobram 3,18 mm do outro lado;
    - a tira de expansao encosta nesses terminais e e soldada neles. Ela nao tem
    conector nenhum: 56 ilhas de solda de um lado, dedos de borda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
    [bom.csv, posicoes.csv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]
2026-07-27 Conector no verso, sem furos na guia, tira soldada dos dois lados
    Tres correcoes de revisao:
    1. A guia ocupa a posicao das vias 5 e 52, entao nao ha terminal ali e a placa
    nao precisa de furo. Footprint do conector volta de 56 para 54 furos. O
    simbolo continua com 56 pinos, o que deixou o esquematico rearranjado a mao
    intacto - o KiCad aceita os dois pinos sem ilha e o DRC fica zerado (sao
    GND, que tem ilha de sobra).
    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
    [posicoes.csv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]
2026-07-27 Corrige a fileira dos pinos do conector: 1..28 embaixo
    Eu tinha invertido as fileiras do footprint do conector de borda em relacao ao
    que estava antes: os pinos 1..28 ficaram do lado de dentro da placa quando
    devem ficar junto a aresta INFERIOR, que e a fileira de baixo do cartao do TK.
    Corrigido no gerador do footprint.
    Havia tambem um erro em troca_j1.py: ele lia a rotacao gravada na placa (que ja
    carregava o efeito do flip anterior) e reaplicava rotacao + flip, espelhando
    duas vezes. Agora o footprint e sempre reposicionado com rotacao 0 e so entao
    flipado para B.Cu.
    Convencao documentada no README e no item 2 de ANTES-DE-FABRICAR: com a placa
    em pe e o conector na borda de baixo, 1..28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
    [tkmem128-B_Cu.gbr, tkmem128-B_Mask.gbr, tkmem128-B_Silkscreen.gbr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]
2026-07-27 Tira de expansao: ilhas de solda chegam ate a borda
    As ilhas de J1 agora comecam na propria aresta da tira e entram 5 mm, em vez
    de ficarem recuadas. Os terminais do TE 5645235 avancam 3,18 +-0,51 mm, mas ha
    conectores com terminal mais curto - com a ilha na borda o terminal encontra
    cobre em qualquer caso, e nao importa quanto a tira entra entre as fileiras.
    Ajustes que vieram junto:
    mk_decoy.py ganhou EDGE_PADS_TOP: a placa-isca nao pode recuar a aresta onde
    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
    [posicoes.csv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]
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2026-07-28 Tira estava espelhada em relacao a placa principal
    A tira e soldada nos terminais do conector da principal, mas as colunas das
    duas estavam invertidas ponta a ponta:
    coluna do pino 1 guia (coluna sem contato)
    principal x = 73,66 mm x = 63,50 mm
    tira x = 5,08 mm x = 15,24 mm <- espelhado
    Os dois layouts correm no MESMO sentido de X do mundo. Pela regra do KiCad
    (Xl x Yl = -N para a face F.Cu vista de fora):
    principal: N = -Y (componentes para tras), Yl = -Z => Xl = +X
    tira: N = +Z (F.Cu para cima), Yl = -Y => Xl = +X
    Logo a coluna de cada pino e a guia tem que cair no mesmo x nas duas placas.
    Corrigido girando J1 e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
    [posicoes.csv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]
2026-07-28 Serigrafia da tira: numeracao por face, nas duas faces
    As ilhas de J1 e os dedos de J2 sao SMD — cada pino existe em UMA face so. Na
    coluna x=73,66 o cobre de F.Cu e o pino 56 e o de B.Cu e o pino 1. A serigrafia
    da frente de J1 estava escrita "1" e "28": nomeando os pads de tras. Vira
    56 / 29. J2, do lado, ja estava certo, o que so deixava a divergencia mais
    visivel na placa.
    A tira e soldada dos DOIS lados, entao quem monta olha as duas faces. Cada face
    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
    [bom.csv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]
2026-07-28 Numeracao do conector tambem no lado dos componentes da principal
    J1 fica em B.Cu - e o unico componente do lado do cobre - e toda a serigrafia
    dele morava so em B.Silkscreen, o lado onde o conector e soldado. Mas o lado
    dos componentes e onde a TIRA DE EXPANSAO e soldada, nos mesmos terminais que
    atravessam a placa: quem monta precisa da numeracao la tambem.
    O conector e THT, entao cada pino existe nas duas faces na mesma coluna e os
    mesmos rotulos valem para as duas, nas mesmas coordenadas. Muda so qual ponta
    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
    [tkmem128-B_Cu.gbr, tkmem128-B_Mask.gbr, tkmem128-B_Silkscreen.gbr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]
2026-07-28 Rasgo da guia 2 mm mais fundo e serigrafia em negrito
    Conferencia em papel do Leonardo (impressao 1:1 contra as pecas reais, jul/2026):
    todas as medidas e alinhamentos bateram. Uma correcao saiu dela.
    RASGO DA GUIA (tira, entre os dedos de J2): 5,0 -> 7,0 mm de profundidade. Os
    5 mm nao chegavam ao fundo da guia do conector. Agora vai de y=45,00 a y=38,00.
    folga lateral ate o cobre mais proximo (pinos 4/6/51/53) 0,88 mm
    quanto ainda daria para aprofundar 0,62 mm
    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
    [tkmem128-B_Cu.gbr, tkmem128-B_Mask.gbr, tkmem128-B_Silkscreen.gbr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]
2026-07-28 Tira: 54 retas de 1,5 mm, zero via, zero plano de terra
    Voce esta certo nas tres criticas. Medindo o que estava la:
    trilha de sinal 0,25 mm
    cobre por face B.Cu 1885 mm x F.Cu 423 mm (82% numa face so)
    vias 53
    Numa placa que alimenta uma cascata de perifericos isso e indefensavel. E o pior
    e que a tira nem tem problema de roteamento: J1 e J2 estao nas MESMAS colunas e
    cada pino fica na MESMA face nos dois (F.Cu = 29..56, B.Cu = 1..28). Cada rede e
    uma reta vertical de x constante. Nao existe um unico cruzamento na placa. O
    Freerouting nao sabia disso e inventou 53 vias.
    Refeito a mao, sem autorouter:
    54 trilhas retas de 1,5 mm
    0 vias
    F.Cu 1044,6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
    [bom.csv, posicoes.csv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]
2026-07-29 Principal: trilha 0,50 mm, reposicionada para rotear
    Voce estava certo nos dois pontos. Medindo o que estava la: dos 96 vaos entre
    ilhas vizinhas de DIP, 10 tinham 2 ou 3 trilhas passando. E a ilha LongPads
    deixa 0,94 mm de vao, onde cabe EXATAMENTE UMA trilha em qualquer largura
    sensata — 0,25/0,15 precisava de 0,95 mm para duas. O autorouter espremeu onde
    nao cabia.
    REGRAS sinal 0,25 -> 0,50 mm | alimentacao 0,60 -> 1,00 | isolacao 0,14 ->
    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
    [bom.csv, posicoes.csv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]
2026-07-29 Ilhas dedicadas para os tres fios de ligacao
    Voce tem razao: fio soldado em cima da perna de outro componente parece conserto
    de erro, nao projeto. Cada uma das tres ligacoes ganhou um PAR DE ILHAS PROPRIAS,
    com o nome da rede na serigrafia ao lado.
    A4 par de ilhas marcado A4 face do cobre ~23 mm
    A2 par de ilhas marcado A2 face dos componentes ~26 mm
    RESET par de ilhas marcado RESET face do cobre ~28 mm
    As duas ilhas de um par caem sempre na MESMA face — senao o fio teria de
    contornar a placa. Cada ilha se liga ao cobre da sua rede por um coto reto de
    0,5 mm com 1,6 mm de comprimento.
    ILHA SMD, NAO PASSANTE, de proposito. Tentei passante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
    [tkmem128-B_Cu.gbr, tkmem128-B_Mask.gbr, tkmem128-B_Silkscreen.gbr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]
2026-07-29 Placa principal em 4 camadas: 100% roteada, zero fio
    F.Cu sinal
    In1.Cu plano de GND inteiro
    In2.Cu plano de +5V inteiro
    B.Cu sinal
    Como todos os componentes sao passantes, cada ilha de +5V e de GND toca o seu
    plano direto: nao ha uma unica trilha de alimentacao nas faces de sinal, nem via
    que sirva so para alimentacao. As duas faces ficam inteiras para sinal.
    MAS as 4 camadas sozinhas nao resolveram nada — continuou em 3 nets em aberto,
    as mesmas de sempre. Foi isso que finalmente expos a causa raiz, que eu vinha
    atacando pelo lado errado o tempo todo:
    As ilhas do conector tinham 1,75 mm num passo de 2,54, deixando 0,79 mm entre
    vizinhas. Uma trilha de 0,50 com 0,20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
    [tkmem128-B_Cu.gbr, tkmem128-B_Mask.gbr, tkmem128-B_Silkscreen.gbr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]
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2026-07-29 Renders no pipeline, e um resto de esquematico que faltava
    Fui conferir o que voce pediu e achei uma coisa real, mais duas que pareciam
    problema e nao eram.
    O QUE ESTAVA ERRADO: os pinos 7 e 15 do conector. Quando removi SJ1/SJ2 do
    esquematico, apaguei tambem os rotulos globais e os fios de 3,81 mm que ligavam
    esses dois pinos, e pus no_connect no lugar. So que dos 20 pinos de barramento
    que esta placa nao usa, os outros 18 (BUS_9V, BUS_CLK, BUS_M1...) continuam com
    rotulo. Ficaram dois pinos representados de um jeito e dezoito de outro, e o
    esquematico deixou de dizer o que sao os pinos 7 e 15 — que e justamente a
    informacao que importa para quem quiser soldar o fio de terra extra a mao.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
    [tkmem128-B_Cu.gbr, tkmem128-B_Mask.gbr, tkmem128-B_Silkscreen.gbr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]
2026-07-29 Auto-desativacao vai para o pino 29; JP4 deixa de existir
    Sua pesquisa resolve o pior risco que sobrava no projeto. Conferi antes de mexer,
    porque errar isso custa o micro de quem monta:
    Pinagem oficial do TK, arquivada em docs/ (imagem, extraida do PDF do Luccas):
    o pino 29 esta marcado **N.C.** E nas fotos do cartao do TK o dedo 29, como o
    17, nao tem trilha nenhuma chegando.
    O lado do Spectrum (28A livre) e a sua pesquisa. Vale registrar que o busdef
    deste projeto sinaliza TODO pino que difere entre as duas maquinas — 16/17/18
    como Y/V/U do video, 34/35/37 como alimentacao divergente — e o 29 nunca teve
    ressalva nenhuma. Duas fontes independentes concordando.
    Com o p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
    [bom.csv, posicoes.csv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]
2026-07-29 Documenta a compatibilidade com ZX Spectrum 48K
    Voce esta certo: com o JP4 fora, a placa passou a servir nas duas familias e a
    documentacao continuava dizendo TK90X/TK95 em toda parte.
    Antes de escrever isso, cruzei TODO contato que a placa toca contra as
    divergencias TK x Spectrum registradas no busdef:
    a placa liga 34 dos 54 contatos
    nove contatos diferem entre as maquinas: 4, 7, 15, 16, 17, 18, 34, 35, 37
    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
    [tkmem128-B_Cu.gbr, tkmem128-B_Mask.gbr, tkmem128-B_Silkscreen.gbr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]
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2026-07-30 Vista de lado: geometria corrigida com a foto da traseira do TK
    Tres correcoes suas, e a primeira era um erro de fato, nao de desenho.
    1. O CONECTOR FICA FORA DA CAIXA. Eu tinha posto o conector DENTRO da caixa
    Patola, com a caixa avancando por cima do micro. Impossivel: na foto da
    traseira do TK90X da para ver que a abertura EXPANSION e recuada dentro da
    carcaça. A caixa encosta na traseira do micro e so o conector entra, pelo
    recorte que se abre na frente dela — que e justamente o recorte que a
    MONTAGEM ja mandava fazer, e que o desenho contradizia.
    Agora o desenho mostra as DUAS carcaças em corte: a do micro com a abertura
    recuada e o cartao la dentro, e a Patol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
    [tkmem128-B_Cu.gbr, tkmem128-B_Mask.gbr, tkmem128-B_Silkscreen.gbr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]
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2026-08-07 Corrige o nome do projeto onde ele fica impresso
    A renomeacao para TKMEM-128 II passou por cima do bloco de titulo dos dois
    esquematicos, que sai no PDF entregue em production/, e do cabecalho do .jed,
    que sai na tela de quem grava a GAL. Os dois ainda diziam "TKMEM-128 KiCad",
    e o .jed ainda apontava para github.com/lrrosa/tkmem128-kicad.
    De quebra, o esquematico da tira carregava o titulo da placa PRINCIPAL — veio
    junto quando o projeto foi copiado. Agora diz o que ele e.
    O .jed foi regerado por galgen.py so pelo cabecalho: antes de escrever, as
    equacoes foram reconstruidas e comparadas fusivel a fusivel com o arquivo
    antigo (0 divergencias em 2706) e o resultado reconferido contra o
    G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
    [tkmem128-ii-B_Cu.gbr, tkmem128-ii-B_Mask.gbr, tkmem128-ii-B_Silkscreen.gbr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]
2026-08-07 Sobe J1 1,5 mm e abre o furo de fixacao H1
    A fileira de baixo do conector estava a 1,385 mm da aresta — 0,635 mm de cobre
    ate a borda — e o corpo do conector, que tem 10 mm de fundo, sobrava 1,19 mm
    PARA FORA da placa: o contorno cortava o conector ao meio, e por isso a
    serigrafia dele era um "U" aberto. Subindo 1,5 mm (medida conferida contra
    interfaces reais de TK90X) o cobre fica a 2,135 mm da aresta, o corpo termina
    0,31 mm DENTRO da placa e o retangulo da serigrafia fecha.
    Isso obrigou a rerotear: das 33 pontas de trilha que pousavam em ilhas de J1,
    26 saiam a 45 graus costurando ENTRE as ilhas, entao subir a fileira jogava as
    ilhas para dentro do proprio leque. Aproveitei o rerrot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
    [posicoes.csv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]
2026-08-07 H1 vira passagem da TORRE (Ø5,4), e a serigrafia dos jumpers vira tabela
    O FURO. H1 nasceu Ø2,7, dimensionado como furo de parafuso. Errado: no desenho
    PB 085/3_TP a torre da caixa tem Ø5 EXTERNO — o Ø2,5 e o furo-piloto dentro
    dela — e a placa assenta no fundo da tampa, que e de onde a torre nasce. Com
    Ø2,7 a placa nao desce, para em cima da torre. O furo tem que deixar passar a
    TORRE, nao o parafuso. Ø5,4 da 0,2 mm de folga radial, que a conicidade de
    desmoldagem pede: e a base da torre, a parte mais larga, que encontra a placa.
    Some junto com o furo pequeno todo o problema que ele criava: o parafuso agora
    corre dentro da torre e nunca toca a placa, entao nao ha questao de folga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
    [posicoes.csv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]
2026-08-07 Realoja as tabelas dos jumpers e afasta o titulo do silk de cima
    JP2 e JP3 foram para o meio do canal de U3 (y 29,00..42,64, 13,64 mm entre as
    duas fileiras de pinos do soquete), centrados nele. JP1 subiu para a faixa
    livre acima de U1, entre os pontos de teste e a fileira de cima do soquete
    (x 54..77, y 17..27). Sao os unicos retangulos grandes da placa: no verso nada
    cobre o canal de um DIP, e o resto esta tomado por ilhas passantes, que
    existem nas duas faces.
    Em JP2, "1-2 = ROMCS LOW" virou "1-2 = ROMCS GAL". Aquela posicao nao fixa
    nivel nenhum: ela liga o ROMCS do barramento a saida do GAL. Quem fixa nivel e
    a 2-3, em +5V, e essa continua "ROMCS HIGH".
    O titulo desceu 0,7 mm — cola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
    [tkmem128-ii-B_Cu.gbr, tkmem128-ii-B_Mask.gbr, tkmem128-ii-B_Silkscreen.gbr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]
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2026-08-07 Poda os desvios que o Freerouting deixou: 54,7 mm em 41 cadeias
    O `ROMA14` que o Leonardo apontou subia por cima de uma ilha do R5,
    atravessava, e descia pelo vao de 1,27 mm ENTRE as duas ilhas do R5 — com
    0,22 mm de folga de cada lado — so para voltar a mesma altura de onde tinha
    saido. Reto por baixo cabia, e com MAIS folga (0,25). Nao era restricao: era
    resto de uma iteracao anterior do autoroteador, que roteia e depois otimiza mas
    nao desfaz escadinha.
    `tools/endireita_trilhas.py` generaliza o teste que fiz a mao naquele caso.
    Quebra cada rede em cadeias entre nos fixos (ilha, via, bifurcacao) e tenta
    trocar o pedaco entre dois vertices por um caminho no estilo da placa — um
    trech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
    [tkmem128-ii-B_Cu.gbr, tkmem128-ii-B_Mask.gbr, tkmem128-ii-B_Silkscreen.gbr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]
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2026-08-07 Documenta o mod do ZX Spectrum 48K, e compara EASY_3 com EASY_6b
    A pagina de preparacao dizia que num Spectrum o ponto interno de desativacao
    "e outro e nos nao verificamos qual". O repositorio goloskokovic/zx16to128upgrade
    documenta os dois, por Issue de placa-mae:
    Issue 2/3/4 IC23 (74LS32) pino 5 -> pino 14 (+5V)
    Issue 5/6 IC27 (ZX8401) pino 35 -> pino 40 (+5V)
    Segurar CAS/RAS em nivel alto para nao chegar aos chips de cima — o mesmo
    efeito do fio do TK, e no caso da Issue 2/3/4 literalmente o mesmo tipo de
    intervencao: forcar a entrada de uma porta do 74LS32 para +5V. Registrei
    tambem o teste rapido que o autor da: com o mod e sem a interface, o micro tem
    que virar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
2026-08-08 Le os esquematicos do Velesoft e corrige o que eu tinha afirmado
    O Leonardo exportou os .sch do Eagle em PDF. Rasterizados com pypdfium2 dao para
    ler, e mudam duas coisas que eu tinha escrito.
    1. EU TINHA AFIRMADO DEMAIS SOBRE O EASY_6b. Escrevi que era "outra arquitetura
    de memoria" com base so no .eqn. A folha do EASY_6b imprime, no quadro de
    equacoes, o conjunto do EASY_3 — sem o + /MREQ*A14, sem o + A14*/A15, com
    + DIS128 puro. O pacote deles se contradiz.
    Quem decide e a tabela de uso de termos do .log, que e o que foi de fato
    compilado: ROMCS, SA17 e SA18 aparecem com 1 termo, e SA14, SA16 e RAMCS com 2.
    No EASY_3 essas tres teriam 1. Comparacao interna a mesma tabela, mesma
    ferram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
2026-08-08 Credita o goloskokovic/zx16to128upgrade no README
    De la vieram duas coisas que nao estavam aqui: os pontos de desativacao da RAM
    interna num ZX Spectrum 48K, por Issue de placa-mae, e os arquivos da variante
    EASY_6b, que permitiram comparar as duas versoes do circuito original.
    O credito diz o que e: o repositorio redistribui o material do Velesoft com o
    credito devido, nao inventa circuito. E fica registrado que nenhuma das duas
    contribuicoes foi verificada em bancada por nos.
    De quebra, a linha do Velesoft na tabela de derivacao ganhou o link para a
    pagina original dele, que ate agora so aparecia solto na documentacao.
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2026-08-08 Tabelas dos jumpers acompanham a fonte de 1,2 mm
    O texto das celulas ja estava em 1,2; a grade e que nao tinha acompanhado, e
    por isso "ABERTO" e "ROM INTERNA" se encavalavam. Agora cada COLUNA e
    dimensionada pelo seu conteudo mais largo, medido da placa e nao estimado —
    com largura unica as tres tabelas somariam mais que o vao e nao caberiam.
    JP1 17,9 x 6,0 JP2 20,8 x 8,0 JP3 14,8 x 6,0 mm
    E ACHEI UM TEXTO NA CAMADA DE COBRE. Um item '1,2 mm' em F.Cu, na altura de
    (43,00 ; 14,00), com a caixa indo ate x=46,80 — em cima da ilha do R2. Dava
    clearance de 0,000 mm e solder_mask_bridge entre redes diferentes. Removido.
    Sobrou de alguma anotacao feita ao ajustar as fontes; nao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
    [tkmem128-ii-B_Cu.gbr, tkmem128-ii-B_Mask.gbr, tkmem128-ii-B_Silkscreen.gbr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]
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2026-09-01 Sincroniza J1 com o PCB na BOM e acrescenta a PALCE20V8H
    A BOM sai do esquematico e as posicoes saem do PCB, e os dois discordavam
    sobre J1: a BOM trazia o header 2x28 do prototipo descartado ("Para a
    expansora", ZX_TK_Bus_Header_2x28) enquanto a placa ja tinha o conector de
    borda TE 5645235 (ZX_TK_Bus_Socket_56). O tools/netlist.py ja estava
    corrigido; so o .kicad_sch nunca foi ressincronizado, porque rodar o
    gen_schematic.py apagaria o rearranjo manual do esquematico.
    Como "Para a expansora" era o campo Value, o nome errado tambem saia
    impresso ao lado de J1 no PDF do esquematico entregue.
    A BOM da tira de expansao ja estava correta (ilhas de solda + dedos, sem
    conector nenhum).
    PALCE20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
    [bom.csv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]
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2026-09-01 Documenta o CI com os dois jobs em tools/README.md
    A secao dizia que o confere_alinhamento ficava de fora do CI, o que deixou
    de ser verdade no commit anterior. Passa a descrever os dois jobs, por que
    a imagem e fixada em 10.0.4 e por que o job usa `docker run` em vez de
    `container:`.
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2026-09-04 Pecas equivalentes para U3, com a ressalva do pino 30
    A BOM nomeia AS6C1008 e AS6C4008, mas o projeto nao depende de fabricante:
    serve qualquer SRAM 128Kx8 de 5 V em DIP-32 na pinagem JEDEC de 1 Mbit. A
    secao registra a REGRA antes da lista, porque a lista envelhece e a regra
    nao.
    A unica divergencia real entre essas pecas e o pino 30, e nos dois casos que
    aparecem na pratica a placa funciona sem alteracao: CE2 ativo alto (caso da
    AS6C1008) ou NC, quando o /CS1 do pino 22 controla sozinho. Isso vale porque
    /SA17 e saida invertida do GAL -- com JP3 aberto o pull-up poe ZX512 em alto,
    o produto zera e o pino 30 fica fixo em nivel alto.
    Dai sai o aviso que faltava nos dois documentos: com uma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
2026-09-05 Corrige a causalidade invertida sobre o contato 29 no Spectrum
    O README dizia que a auto-desativacao "e inerte num Spectrum, porque la o
    contato e N.C.". A conclusao estava certa, a razao nao -- e a razao errada
    induzia a leitura oposta da verdade.
    Ser N.C. nao e o que impede: e o PRE-REQUISITO. O busdef.py registra o contato
    29 como "N.C. no TK E no ZX Spectrum (28A)", e e exatamente por ser livre que
    o truque funciona no TK, onde um fio liga o contato 29 ao ponto interno. Dar
    "e N.C." como causa sugere que o Spectrum tem ali alguma coisa diferente, e
    nao tem.
    A diferenca real nao esta no barramento, esta no procedimento: o mod publicado
    para o Spectrum amarra o pino do mod ao +5 V do pro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

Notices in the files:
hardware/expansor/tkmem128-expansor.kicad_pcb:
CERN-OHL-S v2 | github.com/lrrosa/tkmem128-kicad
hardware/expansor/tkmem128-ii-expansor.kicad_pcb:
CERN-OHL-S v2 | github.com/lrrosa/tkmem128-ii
